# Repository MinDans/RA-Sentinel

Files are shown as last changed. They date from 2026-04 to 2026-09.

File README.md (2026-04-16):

# Project RA-Sentinel - a Radio Access Sentinel
FPGA-based Radio Receiver for securing Wifi an other access points against hacking attacks.

RA-Sentinel is an open-source project focused on creating a cost-effective, small, and low-power wide band radio receiver device that employs an FPGA to automatically detect malicious attacks on Wifi access points, such as Man in the Middle and Denial of Service attacks. By monitoring any Wifi cell, the device enhances internet safety for everyday users.
The device features low-cost receive-only chips that digitize 40 MHz of the Wifi radio spectrum at 2.4 GHz. An FPGA extracts relevant properties from demodulated and decoded packets in real-time without storage. These properties are then processed by a neural network, also implemented on the FPGA, to determine if the traffic is genuine or an attack.

 <br>
This project was funded through the NGI0 Entrust Fund, a fund established by NLnet with financial support from the European Commission's Next Generation Internet programme, under the aegis of DG Communications Networks, Content and Technology under grant agreement No 101069594.

## Latest Updates [15. Dec. 2025]

Added new firmware für the STM32 microcontroller ECU (Embedded Control Unit) on the Backend Board in "/RASBB/Software/RASBB_ECU".
It adds support for UPNP device discovery over Ethernet and provides a system configuration web page.

## System architecture

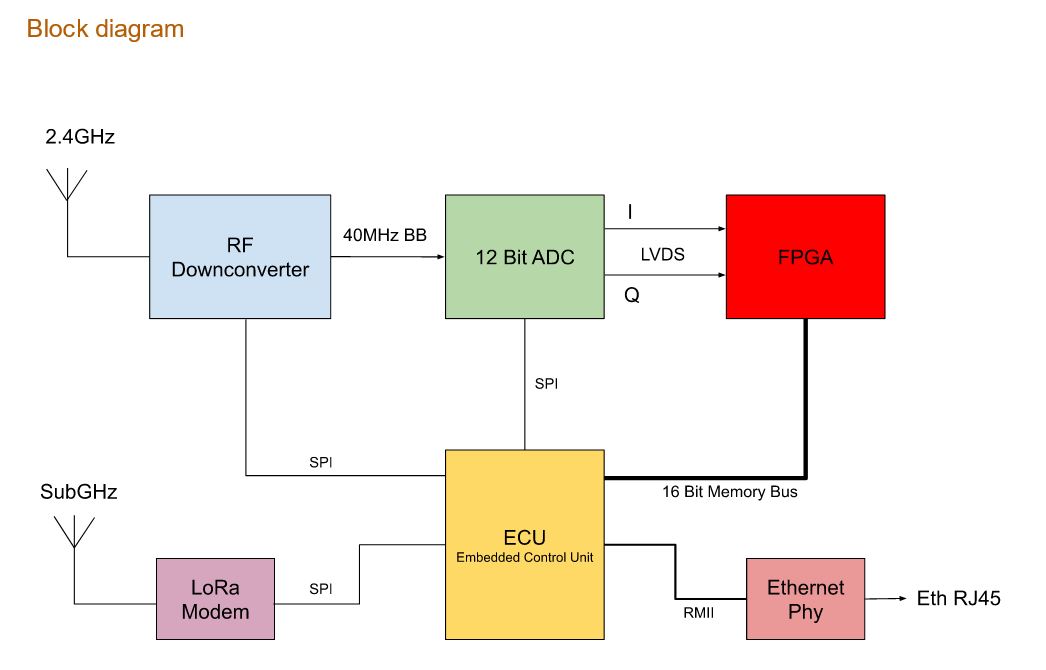
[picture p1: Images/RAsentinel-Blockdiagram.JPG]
RA-Sentinel Block Diagram


## The hardware

The hardware is a wide band SDR receiver that receives at least one complete WiFi Channel on the 2.4GHz ISM band with high resolution (12 Bits) to be able to detect smallest anomalies in a transmitted signal. The initial evaluation hardware consists of a Downcoverter/Tranceiver Chip for 2.4GHz which is widelay used in older WIFi Acess Points (MAX2831). This is followed by a 12 Bit ADC (Texas Instruments ADC3222) which converts a 40MHz window of the 2.4GHZ radio spectrum into a 4 x 240 Bit/s LVDS streams (960kBit/s total) into a XILNIX/AMD Artix7 FPGA sitting on a evaluation board made by QMTECH. 

Picture od the first RA-Sentinel prototype with QM-tech board
<sub>Picture 1: First RA-Sentinel prototype based on the QM-Tech Artix7 board and a new designed RF front end connected via PMOD connector.</sub>

Based on the experience collected with with first prototype, we designed a new SDR prototypr. Two boards of the RASBB and the RASRF2400 have arrived on 23th. Feb. 2025
Testing and bringing up is now ongoing. First results and findings can be found in the corresponding Findings_Rev*.md documents.

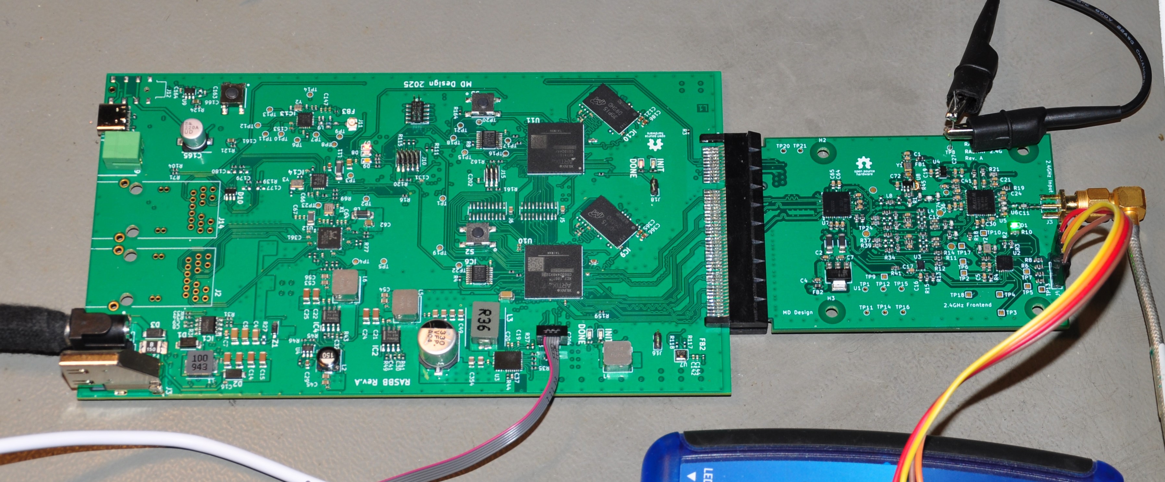
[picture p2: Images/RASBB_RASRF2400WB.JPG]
First RA-Sentinel prototype Revision A

<sub>Picture 2: RA-Sentinel prototype Revision A with RF front end board RASRF2400WB.</sub>

### Design files

**/RFFE2400WB** in this folder of this repository you find the PCB design files in KiCAD format and gerbers for the 2.4GHz 2x PMOD connected RF frontend evaluation/test board.

Link to the FPGA dev. board
[https://de.aliexpress.com/item/1005006473783593.html]

## Software / Firmware

The vast majority of the code will be written in Verilog and run on the FPGA. There is also now a firmware for the RASBB_ECU (Embedded Control Unit) and a"house keeping unit" microcontroller (STM32C031) which programms and controlling the frontend chips. The RASBB_ECI provides the interconnctivity with other systems (alarm forwarding) and the web configuration interface. This firmware is written in C. 

The firmware for the RASBB_ECU can be found <a href="https://github.com/Tobias-DG3YEV/RA-Sentinel/tree/main/RASBB/Software/RASBB_ECU">here</a>. 

The RASBB_ECU Firmware for the onboard STM32 provides a versatile configuration interface with GUI that allows to show statistics and maybe UDP for analytic packets transfer and secure TCP/IP configuration over Ethernet.
To access this, enter the IP of the RAS into your local browser like http://192.168.0.2:4842/. The IP can be easily found via network environment because the RAS supports UPNP over ethernet.

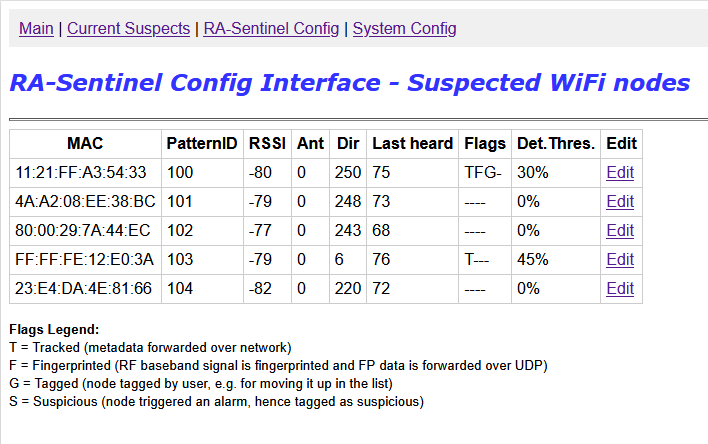
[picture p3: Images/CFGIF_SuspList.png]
WebInterface screenshot


A suspected WiFi node can be

* Tracked: Monitored by relative signal strength and later with additional direction. These values are forwarded to an IDS host that can combine this information with additional data retrieved from different RAS or other network monitoring systems.
* Tagged: Marked for internal memory, moving up in watch list.
* Fingerprinted: Raw IQ data of the frame start is forwarded to a fingerprinting algorythm.

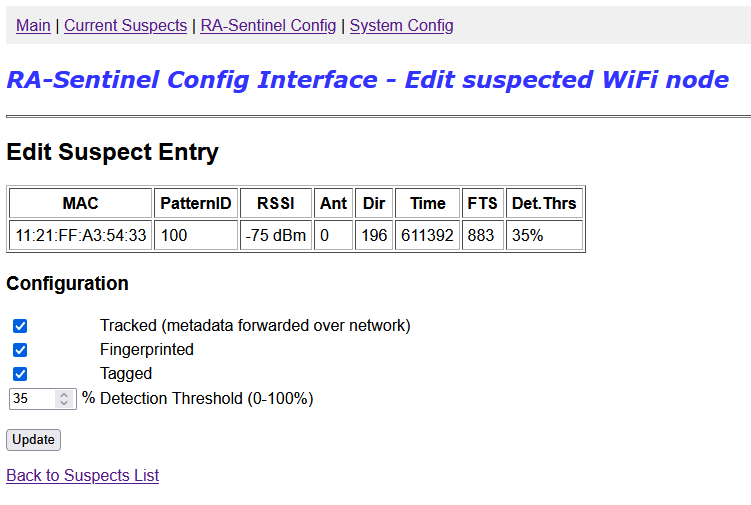
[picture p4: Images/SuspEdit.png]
Suspect Edit Screenshot


**UPNP support**

To ease the installation process, the RAS can be connected to any ethernet based LAN that provides an IPv4 DHCP server. Through the UPNP support, the RAS is easy to find in any network browser of Windows, Linux and Mac etc. 
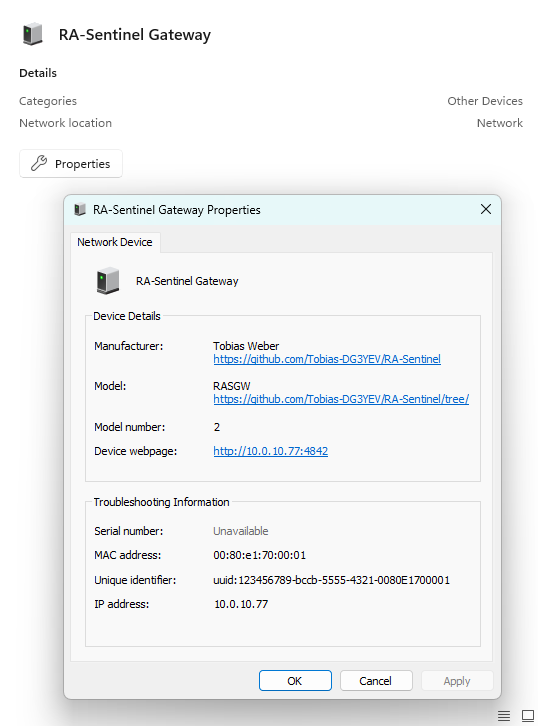
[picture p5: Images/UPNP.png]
UPNP Screenshot


---
## Sub project: RASRF2400WBMC - Directional RF Front End

The **RASRF2400WBMC** is a 4-channel, phase-coherent 2.4 GHz RF front-end board that extends RA-Sentinel with **Angle of Arrival (AoA)** estimation. By receiving the same signal across four spatially separated antennas, the system can estimate the physical direction of a detected attack - enabling threat localization for jamming, spoofing and unauthorized events.

This board connects to the existing RASBB via the PCIe connector and requires no hardware changes to the base band board.

> This sub-project was funded by NLnet: https://nlnet.nl/project/RA-Sentinel-directional/

<a href="https://nlnet.nl/commonsfund/">NGI0 Commons Fund</a>

See [RASRF2400WBMC/README.md](RASRF2400WBMC/README.md) for full details.

---

### Sub Projects / Project steps

The first step on this project was to have a reliable hardware basis. Initially I planned to have at least 40 Megasamples and with this 20 MHz bandwidth which is sufficient to capture the headers and the most common bandwitdhs used on 2.4GHz WiFi (802.11a,b,g) communications channel. But because 802.11n also defines the possibility to use 40MHz bandwith, I wanted the possibility to cover the complete possible channel bandwidth. This has been achieved with the first prototype hardware and prooved with the sub-project RASM2400, Radio Access Spectrum Monitor for 2400MHz. You can find all project details below.

## Sub project #1: RASM2400 - a spectrum monitor

RASM2400 stands for Radio Access Spectrum Monitor operationg on 2400MHZ. It offers a visual spectrum analyzer design that runs on the evaluation hardware set of RA-Sentinel the Artix7 XC7A100T Wukong board and the RFFE2400 front end board.
It shall proove that a 40MHz wide radio spectrum can be received and transported into the FPGA. Further, this project may already be useable for first RF forensics. Feel free to download all the stuff and build an RASM by yourself.

The following diagram shows the system architecture of the RASM2400.

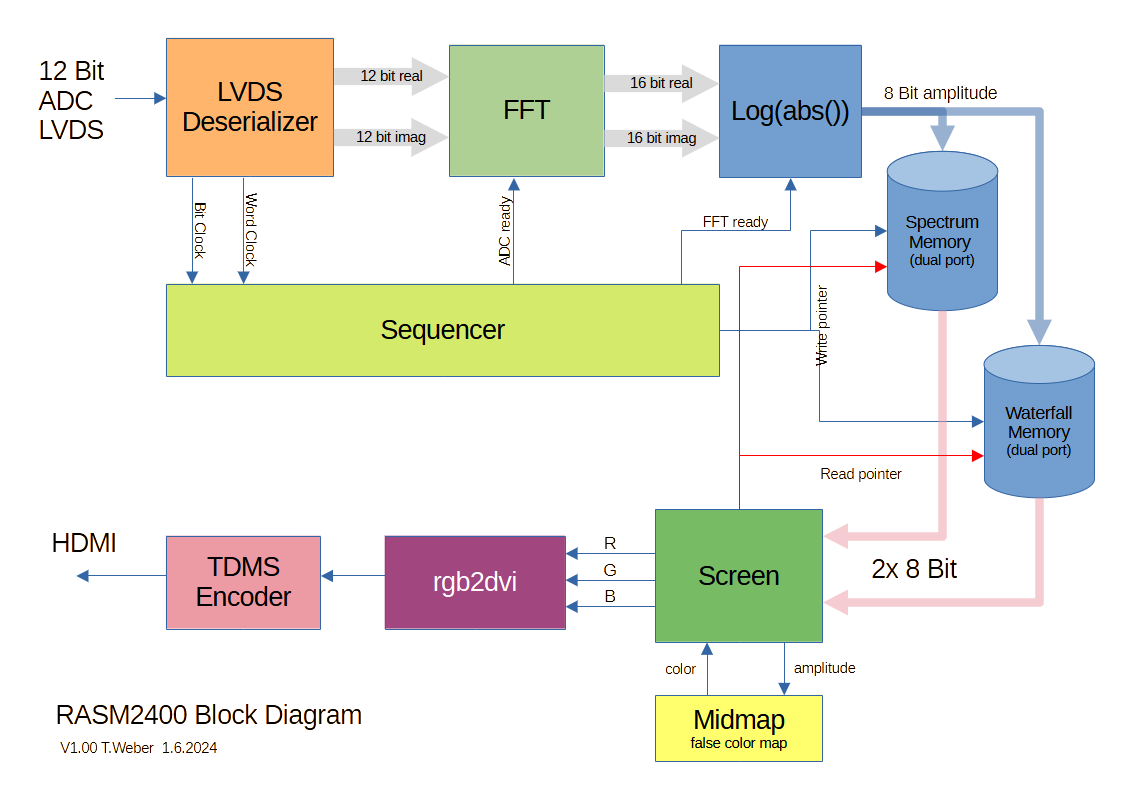
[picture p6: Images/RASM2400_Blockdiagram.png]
RASM2400 Block Diagram


The output of the HDMI port of the QMTECH Wukong board.

Screenshot of the RASM2400 HDMI output

Watch a short demonstration on Youtube by clicking on the thumbnail below.

Watch the video (https://youtu.be/tnwXk62DtHw)

### Software

In this repository you'll find also all software paerts needed to get the project up and running.

**/RASM2400_Verilog**

This folder contains the Verilog source files as well as a ready to program bit stream file. 

**/RASM2400_HKU**

Here you find the firmware for the RF board housekeeping unit. It does not do much a the moment but initializing the Downconverter MAX2831 and the ADC3222. It is planned to receive commands via I2C to change basic parameters wil center frequency, sensitivity and AGC characteristics. This porject can be compiled with arm-gcc or with the free available and Eclipse based development environment (IDE) from ST called "STM32CubeIDE". You can download this IDE from ST.com [https://www.st.com/en/development-tools/stm32cubeide.html]

### Project update 13th Oct. 2024

The target of the next Milestone #2 was the „Identification and isolation of appropriate software components“ and also to „Additionally apply modifications to the openOFDM module to get extra meta data out of the frame demodulator to have a wider data basis for the later fingerprinting process.“

In the following points I describe how I achieved each step of this Milestone.

**1. compile/synthesize openWiFi on the target FPGA**

The code of openWiFi has been successfully ported from the project GitHub site [1] to the evaluation setup that I have designed and set up in the first Milestone. After gluing together the ADC LVDS deserializer block inside the FPGA with the parallel input of the openOFDM core, got rid of several timing constraint issues, I finally achieved to decode a WiFi Frame coming from an arbitrary signal generator. To accomplish this target, the code needed to be isolated from the original open WiFi demo project code. This original demo was based on SDR evaluation boards relying all on the AMD ZYNQ FPGA-ARM chip family. This family provides an FPGA part and an integrated ARM micro processor to which all communication of the FPGA part is connected to. Data from and to the integrated processor is exchanged through a common memory bus. This however is not working with my design idea which is based on a more powerful FPGA with an external ARM co-processor. I tried extracting the needed HDL (Verilog) parts and make this code running stand-alone. Finally I came the conclusion that only the project „openOFDM“ needs to be ported to my RA-Sentinel project hardware because the network layer and the transmit part implemented in openWiFi is not really needed by the RA-Sentinel project because there is no need in routing real data back and forth to a network. We are only interested in the lowest layer of a WiFi frame and its analog characteristics, not the routing of packets and also not in the frame containing payload as such.

First I adapted the test-bench provided in [2] for the Vivado simulation environment. To be able to simulate the complete RA-Sentinel hardware, I created a LVDS emulator that can stream artificial synthesized and recorded  RF data coming originally from the TI ADC 3221. After providing recorded RF data via this LVDS simulator and generating a appropriate, to the ADC phase-locked master clock of 100MHz to the openOFDM core and (see top_tb.v), this setup was able to decode a complete 802.11a/g frame in the AMD Vivado simulator. It took me quite some fiddling and playing with timings and implementation settings of the tool-chain to finally get it running properly on my own hardware. (AMD Artix7 development board my QM-Tech and my 2.4GHz ADC board designed in Milestone 1)

**2. Strip down openWiFi and open OFDM to the receive part**

First this was regarded as an easy task but as deeper I dived into the code  by the original author of the two projects, the more I realized the code provides almost no comments and wire and register definitions are quite ambiguous and non-intuitive. In my opinion the code needed desperately a rework to be better understandable which would also lead to a lower learning curve for others also trying to implement and adapt the existing code base to their needs. Two major things I tried improving with my fork of openOFDM: The introduction of directional prefixes for module ports. I have seen such in the code of another NLnet founded guy called Dan Nissselquist. Adding the prefix  „i_“ to  input ports (defined as wires/registers in Verilog) and „o_“ to the port definition makes it IMHO much easier when browsing through the code, allowing to instantly realize which wire or register is being exported from this current module and which is only a local element. I added these prefixes all over the code of openOFDM. See my fork of openOFDM on GitHub [1] for details. The next thing I found hard to understand, was the use of the ever repeating word „sample“ for all data along the signal path, from the input of the openOFDM core (ADC base-band data) up to near the exit (decoded data bytes). As there is a switch from time domain (endless sample stream) into frequency domain (blocks of 64 frequency bands) in the module „sync_long“, I changed the name of all wires and registers after this module and renamed them into „spectrum“.  Also some comments were added to clarify what a wire or register is doing at a certain point. This work is not yet regarded as being completed. Each time I dig into the original code, I will add comments and try to make the code more „barrier free“.

**3. Create a new fork of openOFDM**

This has been done and the new fork of openOFDm can be found here:

[1] https://github.com/Tobias-DG3YEV/openofdm

It contains comments and my code changes proposed earlier in this document.

**4. Try adding additional meta date stubs**

As I tried figuring out which meta data could be used to distinguish between  genuine transmitting device and a counterfeit device, I found an article at mathworks.com [3] reporting that they proved finding counterfeit, evil twins of a WiFi Access Point by feeding the raw sampled channel data of a transmission into a ML algorithm. For this purpose they followed a kind of a brute force approach by taking all samples of a received frame into account and fed into a ML algorithm. Even the smallest frame like an information or flow control frame that is only 100uS of duration will produce 16kBytes of data which is rather huge. This amount of data may be processable - if the SDR is directly connected to a powerful computer with multiple cores etc. The project RA-Sentinel does not follow this kind of big processing power approach. Amplitude, phase and frequency change due to several effects during the transmission of a frame, but all of these changes always result in a phase shift. So I thought, in  the first attempt identifying a WiFi transmitting device by characterizing (or say learning) the phase deviation over time may be sufficient. Because the RF receiver front end of the RA-Sentinel project has a low noise and high stability master clock (a 40MHz TXCO by Abracom) that is multiple times more accurate that standard commercial WiFi transmitters, I hope that a small amount of phase shift data received in the beginning of a WiFi frame may be enough to clearly identify counterfeit devices. 

**5. Redefine a new simplified interface to access meta parameters**

One thing I have learned throughout the project progress so far, is that even many may say that an FPGA is one of the most versatile digital programmable devices available today, allowing the implementation of any kind of parallel and sequential tasks up to integration of soft-core processors the fact is that all this integrated logic leads to a rather time consuming iterative development process. To optimize WiFi data reception on one side and to interpret and forward meta data on the other side all inside the FPGA leads to an extremely slow and challenging development process. For the analysis of meta data, an external, traditional single chip microprocessor running straight C/C++ code,  offers much more opportunities and most importantly, allows much a faster  development progress. Bit for that, I need a fast and reliable interconnection between the FPGA and the micro processor.

I identified and implemented two interfaces which allow to access 

The first interface I implemented into the FPGA was the SPI slave interface. This interface allows reading and writing 32 wide registers inside the FPGA by an external micro controller (in this case, I use a STM32H743 Cortex-M7)

The SPI interface allows access to the following parameters:

- Receiver characteristics like receiver center frequency, gain, power threshold, max. error rate etc.

- reading current receiver parameters like noise level, signal to noise ratio etc.

Further I needed an interface that is capable transferring header and  metadata that is produced with each WiFi 802.11 frame received to my  external ARM processor. As I cannot foresee at this point in the project how much meta data is needed to distinctly identify a sender hardware of a frame, I was looking for a method to reliably transport greater chunks of data from the FPGA directly into the memory of the external micro-controller without code intervention. Hence, I started evaluating the possibilities based on the peripheral capabilities of the STM32 device family.  After I had invested some effort into research and experiments, I found that SPI especially in a 4-Bit configuration might feasible as it is able transporting 25MByte/s. But the digital camera interface (DCMI) that many of those top range micro-controllers provide, offer 8 Bit parallel data transfer directly into the controller’s memory via DMA at a maximum rate of 80MBytes/s.

So the next step was to design a logic circuit into the FPGA that can mimic the signaling of a digital camera module with DCMI interface. This has been implemented on both sides, the FPGA in Verilog Code and on the STM32H7 in C language. 

The received 802.11 frame info packet that is streamed upon each complete frame reception has the following format:

**Resources:**

[1] https://github.com/open-sdr/openwifi-hw/

[2] https://github.com/Tobias-DG3YEV/openofdm

[3] https://de.mathworks.com/help/comm/ug/design-a-deep-neural-network-with-simulated-data-to-detect-wlan-router-impersonation.html

Project Maintainer: Tobias Weber

Last updated: 27. Feb. 2025

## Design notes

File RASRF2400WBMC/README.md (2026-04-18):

# RASRF2400WBMC - 4-Channel Directional RF Front End

## Overview

The **RASRF2400WBMC** is a 4-channel, 2.4 GHz RF front-end board designed as a directional extension to the RA-Sentinel WiFi intrusion detection system. While the single-channel RASRF2400WB board can detect malicious WiFi attacks, this board adds the ability to determine the **direction from which an attack originates**.

By receiving the same signal across four spatially separated antennas in a phase-coherent manner, the system can estimate the **Angle of Arrival (AoA)** of incoming RF signals. This enables **threat localization** - helping to physically identify and locate sources of jamming, spoofing, Man-in-the-Middle, or Denial of Service attacks.

This board connects to the existing [RASBB](https://github.com/MinDans/RA-Sentinel/tree/main/RASBB) (RA-Sentinel Base Band Board) via a PCIe connector, making use of its multiple ADC input lines without requiring any changes to the base band hardware.

---

## System Architecture

```
ANT 1 --+
ANT 2 --+--[ 4x MAX2831 ]-[ I/Q analog ]-[ ADC3424 #1 ]-[ LVDS D0 ]-|
ANT 3 --+                                  [ ADC3424 #2 ]-[ LVDS D0 ]-|-[ PCIe ] -> RASBB
ANT 4 --+
```

All four channels are **phase-coherent**, meaning the RASBB can compare the phase difference between channels to compute the Angle of Arrival of a detected signal.

---

## Hardware Specifications

| Parameter | Value |
|---|---|
| Frequency | 2.4 GHz ISM band |
| Number of channels | 4 (phase-coherent) |
| Transceiver | Maxim MAX2831 (x4) |
| Digitization | TI ADC3424 x2 - 6-bit eff. - 40 MSPS |
| Interface to RASBB | PCIe connector |
| Primary function | Angle of Arrival (AoA) estimation |
| Status | Sent for manufacturing - not yet delivered |

---

## Repository Structure

```
RASRF2400WBMC/
+-- README.md                          This file
+-- Hardware/
|   +-- KiCad/                         Source design files
|   |   +-- RASRF2400WBMC.kicad_pro
|   |   +-- RASRF2400WBMC.kicad_sch
|   |   +-- RASRF2400WBMC.kicad_pcb
|   |   +-- Libraries/
|   |       +-- Footprints/           KiCad footprints
|   |       +-- Symbols/              KiCad symbols
|   +-- Production/
|       +-- RevA.0/                   Manufacturing outputs for Revision A.0
|           +-- Gerbers/              Gerber + drill files (.gbr, .drl)
|           +-- PickAndPlace/         Component placement files (.csv)
|           +-- BoM/                  Bill of Materials (.csv)
+-- Images/                           Board renders, photos, block diagrams
+-- Docs/
    +-- Design_Notes.md               Design decisions, antenna spacing, AoA theory
```

---

## Relationship to Other RA-Sentinel Boards

| Board | Antennas | Purpose | Interface |
|---|---|---|---|
| RASRF2400WB | 1 | Wideband detection | PCIe -> RASBB |
| RASRF2400WBMC | 4 | Detection + direction finding | PCIe -> RASBB |
| RASBB | - | Base band processing (shared) | - |

Both RF front-end boards are designed to work with the same RASBB.

---

## Status

>  This board has been sent for manufacturing and not yet delivered. A bring-up log will be added to `/Docs/` once the first boards arrive.

---

## Funding

This project was funded through the **NGI0 Commons Fund**, a fund established by NLnet with financial support from the European Commission's Next Generation Internet programme, under the aegis of DG Communications Networks, Content and Technology under grant agreement No 101135429. Additional funding is made available by the Swiss State Secretariat for Education, Research and Innovation (SERI).

<a href="https://nlnet.nl/commonsfund/">NGI0 Commons Fund</a>
<a href="https://nlnet.nl/project/RA-Sentinel-directional/">NLnet</a>

---

## Project Maintainer

**Mina Daneshpajouh** - in collaboration with Tobias Weber

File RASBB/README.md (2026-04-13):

# RA-Sentinel System Overview

The **RA-Sentinel** system consists of two main boards that work together to enable high-performance RF signal reception, digitization, and processing.

## RA-Sentinel Radio Front-End Board (RASRF)
The **RASRF** board is responsible for receiving and conditioning, and digitizing RF signals before transmitting them to the baseband processor.
 - The antenna is connected through a Balun to an RF front-end transceiver, which performs signal reception, downconversion, and filtering.
 - The downconverted signal is then conditioned using a driver circuit optimized for impedance matching and signal integrity.
 - A high-speed 12-bit ADC samples a 40 MHz portion of the 2.4 GHz radio spectrum, converting it into a 960 Mbit/s data stream (2 channels: I+Q, 12-bit each @ 40 
   MSPS). 
 - The digitized data is transmitted over a PCIe interface to the RASBB board for baseband processing.

## RA-Sentinel Baseband Board (RASBB)
The **RASBB** board processes the received digital RF data and manages higher-layer communication.
 - It performs baseband signal processing, extracting relevant information from the digitized RF data.
 - It transitions the processed data from OSI Layer 1 (Physical) to OSI Layer 2 (Data Link) for further communication and protocol handling.
 - The board integrates additional processing units and interfaces for system-level control, data management, and external communication.

Together, the **RASRF** and **RASBB** boards create a scalable, high-performance platform for RF signal acquisition and real-time processing.

Below is the block diagram illustrating the architecture of both boards and their interconnections:





## The hardware

The PCB of the RASBB is constructed from an FR4 eight-layer PCB, which contains several processing units, sensors, and radio and wired interfaces.
Below is a list of its features:

- Two Artix-7 FPGAs with 100k Logic Elements each
- 4 Gigabit (512MB with 16-bit access) Low Voltage DDR3 RAM
- STM32H7 high-performance (up to 480MHz) ARM Cortex-M7 microcontroller
- x8 PCI Express slot
- HDMI port, with video generated in FPGA 1
- 40-bit (32+8) inter-processor communication bridge (accessible by external logic analyzers)
- Two separately usable 16M Flash chips for FPGA configuration, accessible by both FPGA and STM32
- Temperature and humidity sensor for physical environment supervision
- Audio DAC with a 1W output amplifier (for alarm and voice output)
- Audio ADC for capacitive microphone connection (for acoustic environment surveillance)
- Open-collector 30V/1A capable switching output (for alarming devices)
- USB-C port with virtual COM port support for debugging and updates
- 2.4GHz LoRaWAN™ modem chip for robust alarm distribution
- 100Mbit/s Ethernet port connected to the STM32H7 MCU
- 1Gbit/s Ethernet port connected to FPGA 2
- Power over Ethernet (PoE) Type 1 with a maximum power of 13W
- LEDs for indication
- Configuration button
- FPGAs and STM32 accessible through JTAG port

*The RA-Sentinel Baseband Board design will fit into a 100mm extrusion enclosure.* 


*RASBB Rev A (Top View)*


*RASBB Rev AB (Bottom View)*

The PCB of the RASRF is constructed from an FR4 Four-layer PCB, which contains  processing unit, RF-transmitter, and an Analoge/to/Digital converter.

*RASRF Rev AB (Top View)*


*RASRF Rev AB (Bottom View)*

*Hardware designed by **Mina Daneshpajouh**.*

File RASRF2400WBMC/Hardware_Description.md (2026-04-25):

# RASRF2400WBMC - Hardware Description

## What this board does

The RASRF2400WBMC is the RF front end for the directional extension of RA-Sentinel. Where the original single-channel board can tell you *that* a WiFi attack is happening, this one can tell you *where it's coming from*. It does that by receiving the same signal on four separate antennas simultaneously and measuring the phase difference between channels - from which the RASBB can calculate the Angle of Arrival (AoA).

The board was designed to plug into the same PCIe slot as the single-channel RASRF_2400WB. No changes to the RASBB are needed; the baseboard already has enough ADC inputs and the FPGA handles the rest.

---

## Signal chain

Four antennas connect through balun transformers (HHM1902B1) directly into four MAX2831 transceivers. The MAX2831 is a direct-conversion 2.4 GHz chip - it downconverts the incoming signal to baseband I/Q, which comes out as a differential analog signal. Those analog outputs feed two ADC3424 converters (Texas Instruments, 12-bit capable - **6-bit effective**, quad-channel, 40 MSPS). Only the D0 LVDS output pairs are connected; D1 pairs are left unconnected. Each ADC handles two channels (I+Q each), so ADC #1 digitises CH1 and CH2, and ADC #2 handles CH3 and CH4. The resulting LVDS streams go through the PCIe connector to the RASBB, where the FPGA picks them up.

Total digital data rate: four channels x 6-bit I/Q x 40 MSPS = ~ 1.92 Gbit/s.

```
ANT 1 --+
ANT 2 --+--[ 4x MAX2831 ]-[ I/Q analog ]-[ ADC3424 #1 ]-[ LVDS D0 ]-|
ANT 3 --+                                  [ ADC3424 #2 ]-[ LVDS D0 ]-|-[ PCIe ] -> RASBB
ANT 4 --+                                                              +
```

---

## Clock distribution

Phase coherence across the four channels depends entirely on all four MAX2831 chips and both ADCs sharing a single reference clock. A 5PB1206NDGK8 clock fanout buffer takes the 40 MHz reference from an onboard TCXO and distributes it to six outputs: one per MAX2831 and one per ADC. PCB trace lengths from the fanout to each chip are matched.

---

## Housekeeping MCU

A STM32C031K6U6 manages startup and configuration. It talks to all four MAX2831 chips and both ADC3424s over a shared SPI bus, with individual chip selects per device. A level shifter (SN74AXC4T774RSVR) handles the voltage translation between the STM32 and the ADCs SPIs pins. The STM32 also has an I2C interface connected to the RASBB, so the RASBB can send configuration commands or read status without the STM32 needing a standalone firmware update for each parameter change.

---

## Power supply

The board takes 3.3 V from the PCIe connector and generates the additional rails locally:

- **1.8 V** - LD1117 LDO, for the ADC3424 core supply
- **3 V** - ADP7154 LDO, for the MAX2831 supply rails

---

## Key components

| Part | Function |
|---|---|
| Maxim MAX2831 x4 | 2.4 GHz direct-conversion transceiver, RX only in this design |
| TI ADC3424 x2 | 12-bit capable (6-bit effective, D0 only), quad-channel ADC, 40 MSPS, LVDS output |
| 5PB1206NDGK8 | 6-output clock fanout buffer, drives all four transceivers and both ADCs |
| STM32C031K6U6 | Housekeeping MCU - SPI config, I2C to RASBB |
| SN74AXC4T774RSVR | 4-bit dual-supply level shifter (3.3 V <-> 1.8 V) |
| HHM1902B1 x4 | 2.4 GHz balun, single-ended to differential conversion at antenna input |
| LD1117DT18  | 1.8 V LDO regulator |
| ADP7156ACPZ-3.0-R7 | Adjustable LDO, set to 3V |

---

## Block diagram
Block Diagram

---

## Design notes

See [Design Notes](https://github.com/MinDans/RA-Sentinel/blob/main/RASRF2400WBMC/Docs/Design_Notes.md) for antenna spacing derivation, AoA algorithm selection, phase coherence strategy, and the open questions list being worked through during the design phase.

---

*Hardware design: Mina Daneshpajouh*
*Firmware / signal processing: Tobias Weber*

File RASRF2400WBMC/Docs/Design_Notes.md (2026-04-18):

# 

>  This document is a living record of design decisions made during development. It will be updated as the design matures and bring-up begins.

---

## 1. Motivation and Design Goals

The single-channel RASRF2400WB board can detect the presence a WiFi attack (e.g. jamming, spoofing), but cannot determine where the attacker is physically located. In dense environments - offices, apartment buildings, public venues - this limits the usefulness of the detection: an alert without a direction is difficult to act on.

The RASRF2400WBMC adds a spatial dimension to RA-Sentinel's detection capability by implementing a 4-element antenna array with phase-coherent reception. From the phase differences measured across channels, the RASBB FPGA can compute the Angle of Arrival (AoA) of any detected transmission.

---

## 2. Angle of Arrival (AoA) Theory

### 2.1 Basic Principle

To be added

### 2.4 Algorithms Considered

To be added

---

## 3. Phase Coherence Strategy

All 4 MAX2831 transceivers must share a single reference clock to ensure phase coherence across channels. Any independent oscillator drift would introduce pseudo-random phase offsets that make AoA estimation impossible.

**Approach:**
- Route a single master clock (from RASBB or an on-board TCXO) to all four MAX2831 REF_CLK inputs
- Use matched-length PCB traces from the clock source to each transceiver
- Use matched-length traces from ADC outputs to the PCIe connector

The MAX2831 requires a 40 MHz reference clock. This is consistent with the 40 MHz TCXO already used on the RASRF2400WB board.

---

## 4. ADC and Data Path

Each MAX2831 produces a baseband I/Q analog output. Each of the 4 channels feeds an ADC for digitisation. The digitised streams are serialised for transport over the PCIe interface to the RASBB.

Data rate estimate per channel:
- 6-bit I, 6-bit Q @ 40 MSPS = 480 Mbit/s per channel (ADC3424 D0 only - D1 pairs not connected)
- 4 channels = 1.92 Gbit/s total

---

## 5. PCB Stack-up 

The RASRF_2400_Directional PCB will use a **6-layer stack-up**:

| Layer | Function |
|---|---|
| Top | RF and signal routing |
| L2 | Ground plane |
| L3 | Power plane/signal routing |
| L4 | Power plane/signal routing |
| L5 | Ground plane |
| L6 | Signal routing |

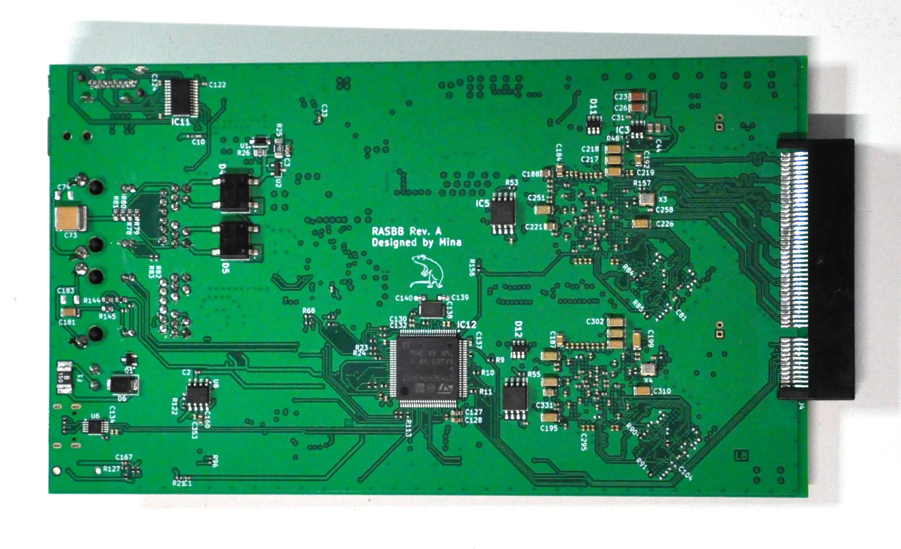
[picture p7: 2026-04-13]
RASBB/RASBB_RevA_back.JPG

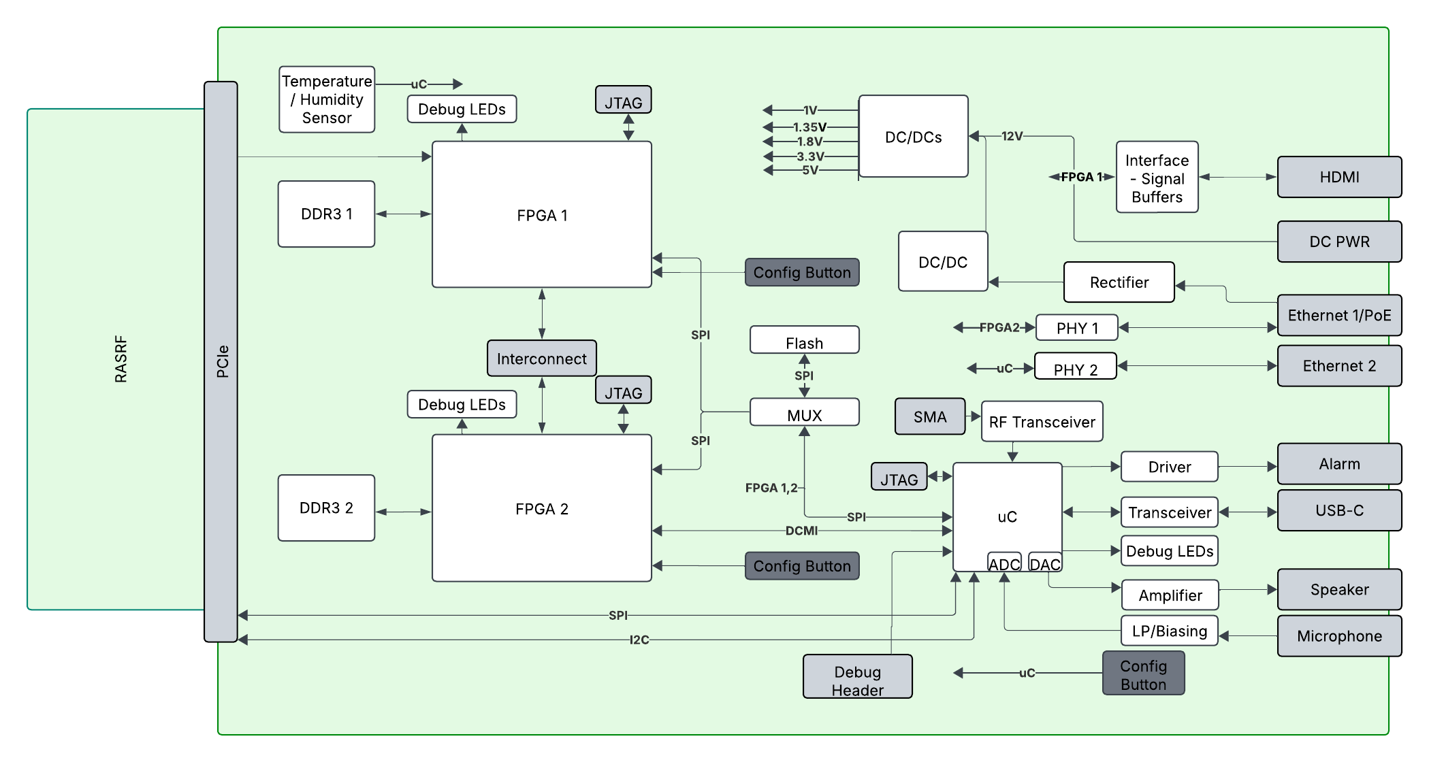
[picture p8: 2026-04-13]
RASBB/RASBB-BlockDiagram.png

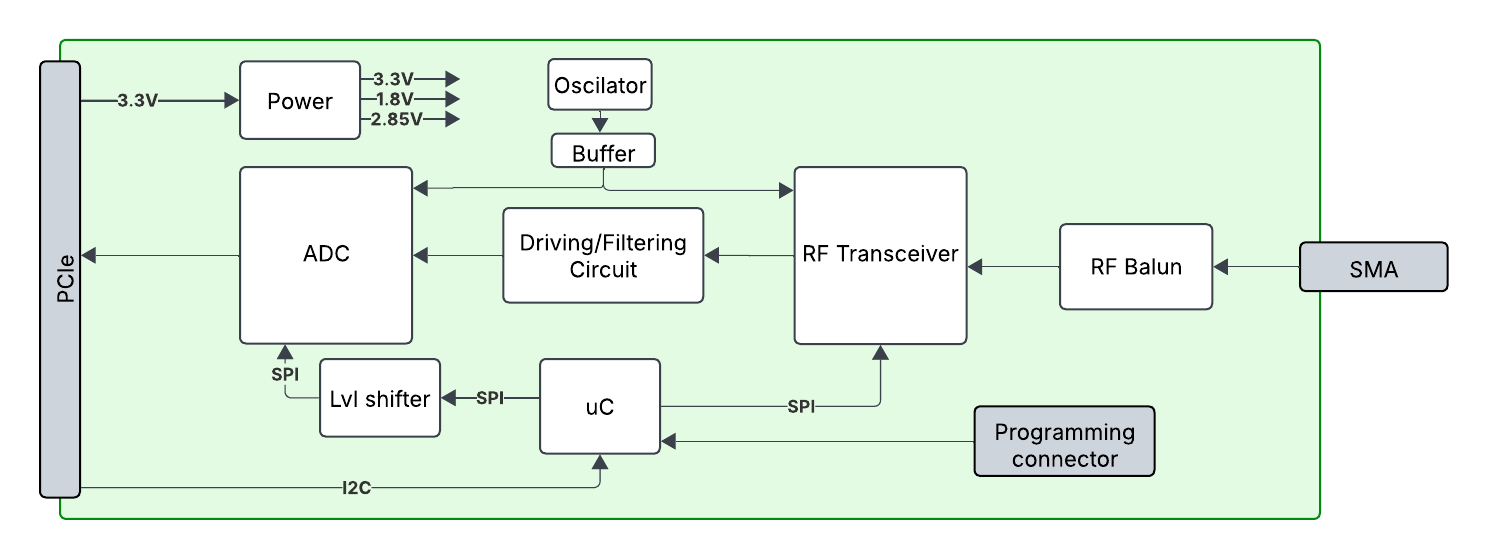
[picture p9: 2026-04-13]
RASBB/RASRF-BlockDiagram.png

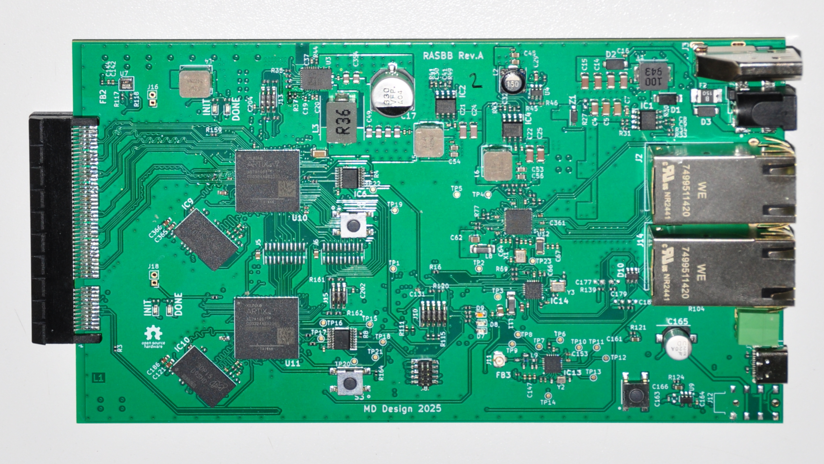
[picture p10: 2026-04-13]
RASBB/RASBB_RevA_top.jpg

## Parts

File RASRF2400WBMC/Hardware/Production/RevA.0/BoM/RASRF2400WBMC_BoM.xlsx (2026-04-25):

Reference | Qty | Value | DNP | Exclude from BOM | Exclude from Board | Footprint | Manufacturer_Name | Manufacturer_Part_Number | Description
H1,H2,H3,H4 | 4 | MountingHole | DNP |  |  | MountingHole:MountingHole_3.2mm_M3_ISO7380
J7 | 1 | PCIexpress_x8 | DNP |  |  | Connector_PCBEdge:BUS_PCIexpress_x8
TP1,TP2,TP3,TP4,TP5,TP6,TP7,TP9,TP10,TP12,TP16,TP19,TP20,TP22 | 14 | TestPoint | DNP |  |  | TestPoint:TestPoint_THTPad_D1.0mm_Drill0.5mm
TP8 | 1 | TestPoint | DNP |  |  | TestPoint:TestPoint_Pad_1.0x1.0mm
TP11,TP13,TP15,TP17 | 4 | TestPoint | DNP |  |  | TestPoint:TestPoint_Pad_D1.0mm
J1,J2,J3,J4 | 4 | 60312202111527 |  |  |  | JACK_02114307_WRE | Würth Elektronik | 60312202111527 | Conn, WR-MPC3 Power, Male Header, 2-pos, 3.81mm Pitch, SMD, 12A, 250V
J5 | 1 | 1-1478979-0 | DNP |  |  | 114789790 | TE Connectivity | 1-1478979-0 | Conn, SMA, Jack/Female, Straight, PCB Mount, 50Ω, Solder, Through Hole, 18GHz
C159,C160,C161,C162,C163,C164,C165,C166,C194,C195,C196,C197,C198,C199,C200,C201 | 16 | 11pF |  |  |  | Capacitor_SMD:C_0402_1005Metric | Johanson | 500R07S110GV4T | Cap, MLCC, 11pF, 50V, C0G/NP0, 0402, ±2%
IC2 | 1 | 5PB1206NDGK8 |  |  |  | QFN40P300X300X100-21N-D | Renesas Electronics | 5PB1206NDGK8 | IC, Clock Buffer, 1:6 TCXO/LVCMOS, 1.8V, 200MHz, Individual OE, 20-VFQFPN, T&R
Y1 | 1 | 7L-40.000MBS-T |  |  |  | 4-SMD_NoLead_Oscillator | TXC Corporation | 7L-40.000MBS-T | OSC, TCXO, 40MHz, 3.3V, ±2ppm, Clipped Sine, SMD 2.5x2mm, 4-Pin
Y2 | 1 | ABM10-166-12.000MHZ-T3 |  |  |  | ABM10 | Abracon | ABM10-166-12.000MHZ-T3 | Crystal, 12MHz, 8pF, ±10ppm, 125Ω ESR, SMD 2.5x2.0mm, T&R
IC5,IC6 | 2 | ADC3424IRTQR |  |  |  | QFN50P800X800X100-57N-D | Texas Instruments | ADC3424IRTQR | IC, ADC, Quad-Ch, 12-bit, 25–125MSPS, LVDS Output, JESD204B, 56-QFN (8x8mm), T&R
IC1 | 1 | ADP7156ACPZ-3.0-R7 |  |  |  | SON50P300X300X80-11N-D | Analog Devices | ADP7156ACPZ-3.0-R7 | 1.2 A, Ultralow Noise, High PSRR, Fixed Output, RF Linear Regulator
D1 | 1 | APTD1608SECK/J4-PF |  |  |  | LED_SMD:LED_0603_1608Metric | Kingbright | APTD1608SECK/J4-PF | LED, Orange, 605nm, 2.2V, 20mA, 0603, SMD
FB1 | 1 | BLM18BD601BH1D |  |  |  | IND_BLM18_0603_MUR | Murata | BLM18BD601BH1D | Ferrite Bead, 600Ω @100MHz, 500mA, 0.38Ω DCR, 0603, T&R
FB2 | 1 | BLM18SG331TN1B |  |  |  | IND_BLM18_0603_MUR | Murata | BLM18SG331TN1D | Ferrite Bead, 330Ω @100MHz, ±25%, 1.5A, 70mΩ DCR, 0603, T&R
FB3,FB4,FB5,FB6 | 4 | BLM41PG102SN1L |  |  |  | IND_BLM41_1806_MUR | Murata | BLM41PG102SN1L | Ferrite Bead, 1kΩ @100MHz, ±25%, 1.5A, 90mΩ DCR, 1806 (4516 Metric), T&R
Z1 | 1 | BZT52C4V7 |  |  |  | BZT52C4V7 | Diotec | BZT52C4V7 | Zener Diode, 4.7V, ±5%, 200mW, SOD-123, T&R
C171,C173,C176,C178,C206,C208,C211,C213 | 8 | 0.22uF |  |  |  | Capacitor_SMD:C_0603_1608Metric | Yageo | CC0603KRX7R9BB224 | Cap, MLCC, 220nF, 50V, X7R, 0603, ±10%
C77,C78,C100,C101,C123,C124,C146,C147 | 8 | 1.5pF |  |  |  | Capacitor_SMD:C_0402_1005Metric | Murata | GJM1555C1H1R5BB01D | Cap, MLCC, 1.5pF, 50V, C0G/NP0, 0402, ±0.1pF
C52,C54 | 2 | 6pF |  |  |  | Capacitor_SMD:C_0402_1005Metric | Murata | GJM1555C1H6R0CB01D | Cap, MLCC, 6pF, 50V, C0G/NP0, 0402, ±0.25pF
C71,C72,C94,C95,C117,C118,C140,C141 | 8 | 10pF | DNP |  |  | Capacitor_SMD:C_0402_1005Metric | Murata | GRM1555C1H100JZ01D | Cap, MLCC, 10pF, 50V, C0G/NP0, 0402, ±5%
C61,C62,C65,C68,C70,C75,C80,C84,C85,C88,C91,C93,C98,C103,C107,C108,C111,C114,C116,C121,C126,C130,C131,C134,C137,C139,C144,C149 | 28 | 100pF |  |  |  | Capacitor_SMD:C_0402_1005Metric | Murata | GRM1555C1H101JA01D | Cap, MLCC, 100pF, 50V, C0G/NP0, 0402, ±5%
C2 | 1 | 2200pF | DNP |  |  | Capacitor_SMD:C_0402_1005Metric | Murata | GRM1555C1H222JA01D | Cap, MLCC, 2200pF, 50V, C0G/NP0, 0402, ±5%
C3,C81,C104,C127,C150 | 5 | 2200pF |  |  |  | Capacitor_SMD:C_0402_1005Metric | Murata | GRM1555C1H222JA01D | Cap, MLCC, 2200pF, 50V, C0G/NP0, 0402, ±5%
C7,C8,C9,C10 | 4 | 47pF |  |  |  | Capacitor_SMD:C_0402_1005Metric | Murata | GRM1555C1H470FA01D | Cap, MLCC, 47pF, 50V, C0G/NP0, 0402, ±1%
C79,C102,C125,C148 | 4 | 68pF |  |  |  | Capacitor_SMD:C_0402_1005Metric | Murata | GRM1555C1H680JZ01D | Cap, MLCC, 68pF, 50V, C0G/NP0, 0402, ±5%
C55,C59,C60,C63,C73,C82,C83,C86,C96,C105,C106,C109,C119,C128,C129,C132,C142 | 17 | 10uF |  |  |  | Capacitor_SMD:C_0402_1005Metric | Murata | GRM155R61A106ME11D | Cap, MLCC, 10µF, 10V, X5R, 0402, ±20%
C1,C11,C12,C13,C14,C15,C16,C17,C18,C19,C20,C21,C22,C23,C24,C25,C26,C27,C28,C29,C30,C31,C32,C36,C41,C44,C56,C57,C58,C76,C99,C122,C145,C167,C168,C169,C170,C172,C174,C175,C177,C179,C180,C181,C182,C183,C184,C185,C202,C203,C204,C205,C207,C209,C210,C212,C214,C215,C216,C217,C218,C219,C220 | 63 | 100nF |  |  |  | Capacitor_SMD:C_0402_1005Metric | Murata | GRM155R71A104KA01D | Cap, MLCC, 100nF, 10V, X7R, 0402, ±10%
C39,C45,C46,C47,C64,C66,C67,C69,C74,C87,C89,C90,C92,C97,C110,C112,C113,C115,C120,C133,C135,C136,C138,C143 | 24 | 10nF |  |  |  | Capacitor_SMD:C_0402_1005Metric | Murata | GRM155R71H103KA88D | Cap, MLCC, 10nF, 50V, X7R, 0402, ±10%
C33,C34,C35,C38,C42,C48,C50,C51 | 8 | 10uF |  |  |  | Capacitor_SMD:C_0603_1608Metric | Murata | GRM188R61E106MA73D | Cap, MLCC, 10µF, 25V, X5R, 0603, ±10%
C40,C43,C49 | 3 | 1uF |  |  |  | Capacitor_SMD:C_0603_1608Metric | Murata | GRM188R71E105KA12D | Cap, MLCC, 1µF, 25V, X7R, 0603, ±10%
C4,C5,C6,C53 | 4 | 100nF | DNP |  |  | Capacitor_SMD:C_0603_1608Metric | Murata | GRM188R71H104KA93D | Cap, MLCC, 100nF, 50V, X7R, 0603, ±10%
C37,C151,C152,C153,C154,C155,C156,C157,C158,C186,C187,C188,C189,C190,C191,C192,C193 | 17 | 100nF |  |  |  | Capacitor_SMD:C_0603_1608Metric | Murata | GRM188R71H104KA93D | Cap, MLCC, 100nF, 50V, X7R, 0603, ±10%
U5,U7,U9,U11 | 4 | HHM1902B1 |  |  |  | HHM-4_1P0X0P5 | TDK Corporation | HHM1902B1 | Balun, Multilayer, 2.4–2.5GHz, 50/50Ω, 0.8dB IL, SMD 0402
U2 | 1 | LD1117DT33TR |  |  |  | DPAK456P1010X240-3N | STMicroelectronics | LD1117DT33TR | IC, LDO Regulator, 3.3V, 800mA, Fixed, DPAK (TO-252), T&R
U4,U6,U8,U10 | 4 | MAX2831ETM+T |  |  |  | 21-0144_T4877&plus_4_MXM | Analog Devices (Maxim Integrated) | MAX2831ETM+T | IC, RF Transceiver, 802.11b/g, 2.4–2.5GHz, 21dBm, 48-TQFN, T&R
Q2 | 1 | MMBT3904LT1G |  |  |  | SOT96P237X111-3N | Onsemi | MMBT3904LT1G | These Devices are Pb-Free, Halogen Free/BFR Free and are RoHS Compliant; S Prefix for Automotive and Other Applications Requiring Unique Site and Control Change Requirements; AEC-Q101 Qualified and PPAP Capable
R9,R23,R24,R26,R27,R29,R30,R31,R32,R33,R34,R95,R125,R126 | 14 | 10K |  |  |  | Resistor_SMD:R_0402_1005Metric | Yageo | RC0402FR-0710KL | Res, Thick Film, 10kΩ, 1/16W, 0402, ±1%
R35,R36,R44,R45,R53,R54,R62,R63 | 8 | 10K | DNP |  |  | Resistor_SMD:R_0402_1005Metric | Yageo | RC0402FR-0710KL | Res, Thick Film, 10kΩ, 1/16W, 0402, ±1%
R16,R17 | 2 | 4K7 | DNP |  |  | Resistor_SMD:R_0402_1005Metric | Yageo | RC0402FR-074K7L | Res, Thick Film, 4.7kΩ, 1/16W, 0402, ±1%
R18,R19,R20,R21,R127 | 5 | 100K |  |  |  | Resistor_SMD:R_0402_1005Metric | Yageo | RC0402FR-07100KL | Res, Thick Film, 100kΩ, 1/16W, 0402, ±1%
R28,R71,R72,R73,R74,R75,R76,R77,R78,R98,R99,R100,R101,R102,R103,R104,R105 | 17 | 1K |  |  |  | Resistor_SMD:R_0603_1608Metric | Yageo | RC0603FR-071KL | Res, Thick Film, 1kΩ, 1/10W, 0603, ±1%
R2 | 1 | 10K | DNP |  |  | Resistor_SMD:R_0603_1608Metric | Yageo | RC0603FR-0710KL | Res, Thick Film, 10kΩ, 1/10W, 0603, ±1%
R3,R8 | 2 | 10K |  |  |  | Resistor_SMD:R_0603_1608Metric | Yageo | RC0603FR-0710KL | Res, Thick Film, 10kΩ, 1/10W, 0603, ±1%
R10,R11,R12,R13,R14,R15 | 6 | 33 |  |  |  | Resistor_SMD:R_0603_1608Metric | Yageo | RC0603FR-0733RL | Res, Thick Film, 33Ω, 1/10W, 0603, ±1%
R4 | 1 | 100K |  |  |  | Resistor_SMD:R_0603_1608Metric | Yageo | RC0603FR-07100KL | Res, Thick Film, 100kΩ, 1/10W, 0603, ±1%
R22 | 1 | 100K | DNP |  |  | Resistor_SMD:R_0603_1608Metric | Yageo | RC0603FR-07100KL | Res, Thick Film, 100kΩ, 1/10W, 0603, ±1%
R39,R48,R57,R66 | 4 | 100 |  |  |  | Resistor_SMD:R_0603_1608Metric | Yageo | RC0603FR-07100RL | Res, Thick Film, 100Ω, 1/10W, 0603, ±1%
R87,R88,R89,R90,R91,R92,R93,R94,R114,R115,R116,R117,R118,R119,R120,R121 | 16 | 150 |  |  |  | Resistor_SMD:R_0603_1608Metric | Yageo | RC0603FR-07150RL | Res, Thick Film, 150Ω, 1/10W, 0603, ±1%
R42,R51,R60,R69 | 4 | 750 |  |  |  | Resistor_SMD:R_0603_1608Metric | Yageo | RC0603FR-07750RL | Res, Thick Film, 750Ω, 1/10W, 0603, ±1%
R43,R52,R61,R70 | 4 | 1.2K |  |  |  | Resistor_SMD:R_0603_1608Metric | Yageo | RC0603FR-071K2L | Res, Thick Film, 1.2kΩ, 1/10W, 0603, ±1%
R40,R41,R49,R50,R58,R59,R67,R68,R96,R123 | 10 | 49.9 |  |  |  | Resistor_SMD:R_0603_1608Metric | Yageo | RC0603FR-0749R9L | Res, Thick Film, 49.9Ω, 1/10W, 0603, ±1%
R5 | 1 | 68.1K |  |  |  | Resistor_SMD:R_0603_1608Metric | Yageo | RC0603FR-0768K1L | Res, Thick Film, 68.1kΩ, 1/10W, 0603, ±1%
L1,L2,L3,L4,L5,L6,L7,L8 | 8 | 0 |  |  |  | Inductor_SMD:L_0603_1608Metric | Yageo | RC0603JR-070RL | Res, Thick Film, 0Ω, 1/10W, 0603, Jumper
R1 | 1 | 0 | DNP |  |  | Resistor_SMD:R_0603_1608Metric | Yageo | RC0603JR-070RL | Res, Thick Film, 0Ω, 1/10W, 0603, Jumper
R6,R7,R25,R37,R38,R46,R47,R55,R56,R64,R65,R79,R80,R81,R82,R83,R84,R85,R86,R97,R106,R107,R108,R109,R110,R111,R112,R113,R124 | 29 | 0 |  |  |  | Resistor_SMD:R_0603_1608Metric | Yageo | RC0603JR-070RL | Res, Thick Film, 0Ω, 1/10W, 0603, Jumper
U3 | 1 | SN74AXC4T774RSVR |  |  |  | RSV0016A | Texas Instruments | SN74AXC4T774RSVR | IC, Level Shifter, 4-bit Dual-Supply Bus Transceiver, Bidirectional, Independent Dir Control, Tri-State, 16-UQFN (1.8x2.6mm), T&R
IC3 | 1 | STM32C031K6U6 |  |  |  | QFN50P500X500X60-33N-D | STMicroelectronics | STM32C031K6U6 | IC, MCU, 32-bit ARM Cortex-M0+, 48MHz, 32KB Flash, 12KB RAM, 2x USART, SPI, I2C, ADC, 2–3.6V, 32-UFQFPN
U1 | 1 | TLV9001DBVR |  |  |  | Package_TO_SOT_SMD:SOT-23-5 | Texas Instruments | TLV9001DBVR | R-R I/O, 1MHz, 60µA, 3.3V
J6 | 1 | Conn_01x04_Pin |  |  |  | Connector_PinSocket_2.54mm:PinSocket_1x04_P2.54mm_Vertical | Samtec | TSW-104-07-G-S | Conn, Header, Male, 1x4, 2.54mm Pitch, THT, Vertical, Unshrouded

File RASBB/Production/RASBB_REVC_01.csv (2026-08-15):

Reference | Value | Footprint | Qty | DNP | LCSC Part # | Mfr. Part # | Description
C1,C2,C19,C130,C167,C171 | 1uF | Capacitor_SMD:C_0402_1005Metric | 6 |  | C3889771 | 0402X105M160CT | 16V 1uF X5R ±20% 0402 Multilayer Ceramic Capacitors MLCC - SMD/SMT ROHS
C3,C7 | 10nF | Capacitor_SMD:C_0603_1608Metric | 2 |  | C6119837 | CGA0603X7R103K101JT | ±10% X7R 10nF 100V 0603
C4 | 10uF/100V | Capacitor_SMD:C_1206_3216Metric | 1 |  | C6872041 | C3216X6S2A106K160AC | 100V 10uF X6S ±10% 1206 Multilayer Ceramic Capacitors MLCC - SMD/SMT ROHS
C5,C6 | 4.7uF | Capacitor_SMD:C_1206_3216Metric | 2 |  | C2997285 | GRM31CZ72A475KE11L | 100V 4.7uF X7R ±10% 1206 Multilayer Ceramic Capacitors MLCC - SMD/SMT ROHS
C8 | 22pF | Capacitor_SMD:C_0402_1005Metric | 1 |  | C2175872 | CC0402JRNPO7BN220 | 16V 22pF NP0 ±5% 0402 Multilayer Ceramic Capacitors MLCC - SMD/SMT ROHS
C9 | 4.7nF | Capacitor_SMD:C_0402_1005Metric | 1 |  | C1852867 | CC0402KRX7R6BB472 | 10V 4.7nF X7R ±10% 0402 Multilayer Ceramic Capacitors MLCC - SMD/SMT ROHS
C10,C16,C18,C27,C28,C31,C33,C34,C35,C36,C37,C55,C58,C59,C60,C61,C63,C64,C65,C67,C68,C70,C71,C76,C77,C84,C95,C99,C100,C107,C118,C122,C123,C124,C129,C131,C132,C133,C134,C135,C136,C137,C138,C144,C148,C152,C154,C164,C169,C172,C173,C174,C202,C204,C237,C258,C259,C260,C268,C270,C276,C283,C342,C352,C353,C356,C357,C358,C359,C360,C361,C362,C363,C364 | 100nF | Capacitor_SMD:C_0402_1005Metric | 74 |  | C152814 | 0402B104K500CT | 10V 100nF X7R ±10% 0402 Multilayer Ceramic Capacitors MLCC - SMD/SMT ROHS,50V 100nF X7R ±10% 0402 Multilayer Ceramic Capacitors MLCC - SMD/SMT ROHS
C11,C38,C39,C40,C50,C51,C126,C150,C151 | 10nF | Capacitor_SMD:C_0402_1005Metric | 9 |  | C301927 | 0402B103K500CT | 50V 10nF X7R ±10% 0402 Multilayer Ceramic Capacitors MLCC - SMD/SMT ROHS
C12,C13,C14,C15,C21,C22,C23,C24,C25,C26 | 10uF | Capacitor_SMD:C_1206_3216Metric | 10 |  | C531431 | CGA5L1X7R1H106KT0Y0N | 50V 10uF X7R ±10% 1206 Multilayer Ceramic Capacitors MLCC - SMD/SMT ROHS
C17 | 33uF | RASBB:EEE0JA152UAP | 1 |  | C178581 | EEE-FP1V330AP | Aluminum Electrolytic Capacitors - SMD 33UF 35V ELECT FP SMD
C20,C69,C72,C206,C208,C210,C211,C212,C213,C214,C215,C216,C217,C223,C227,C228,C246,C247,C249,C250,C266,C267,C290,C292,C294,C295,C296,C297,C298,C299,C300,C301,C307,C311,C312,C330,C331,C333,C334,C350,C351 | 4.7uF | Capacitor_SMD:C_0402_1005Metric | 41 |  | C77004 | GRM155R61A475KEAAD | 10V 4.7uF X5R ±10% 0402 Multilayer Ceramic Capacitors MLCC - SMD/SMT ROHS
C29,C98,C115,C121,C127,C128,C175,C186,C279,C365,C366 | 4.7uF | Capacitor_SMD:C_0603_1608Metric | 11 |  | C7281848 | GMK107BBJ475KA-T | 35V 4.7uF X5R ±10% 0603 Multilayer Ceramic Capacitors MLCC - SMD/SMT ROHS
C30,C32,C75,C89,C92,C112,C153,C182,C185,C189,C190,C191,C193,C194,C196,C197,C200,C201,C203,C205,C207,C209,C222,C224,C225,C229,C230,C231,C232,C233,C234,C235,C236,C238,C239,C241,C242,C243,C244,C245,C251,C252,C253,C254,C255,C257,C261,C262,C263,C264,C265,C269,C273,C274,C275,C277,C278,C280,C281,C284,C285,C287,C289,C291,C293,C306,C308,C313,C314,C315,C316,C326,C327,C328,C329,C335,C336,C337,C338,C346,C347,C348,C349 | 470nF | Capacitor_SMD:C_0402_1005Metric | 83 |  | C471404 | GRT155R71A474KE01D | 16V 470nF X7R ±10% 0402 Multilayer Ceramic Capacitors MLCC - SMD/SMT ROHS
C41 | 10pF | Capacitor_SMD:C_0402_1005Metric | 1 |  | C2182752 | C0402C100J4GAC7867 | 16V 10pF C0G ±5% 0402 Multilayer Ceramic Capacitors MLCC - SMD/SMT ROHS
C42,C46,C49,C52,C62,C170,C184,C187,C188,C192,C221,C305 | 47uF | Capacitor_SMD:C_0805_2012Metric | 12 |  | C124129 | GRM21BR61A476ME15L | 10V 47uF X5R ±20% 0805 Multilayer Ceramic Capacitors MLCC - SMD/SMT ROHS
C43 | 5.1pF | Capacitor_SMD:C_0402_1005Metric | 1 |  | C3855079 | GRM1555C1E5R1CA01D | 25V 5.1pF C0G 0402 Multilayer Ceramic Capacitors MLCC - SMD/SMT ROHS
C44,C45,C47,C48,C53,C54,C56,C57,C125,C256 | 22uF | Capacitor_SMD:C_0603_1608Metric | 10 |  | C6776252 | 0603YD226MAT2A | 16V 22uF X5R ±20% 0603 Multilayer Ceramic Capacitors MLCC - SMD/SMT ROHS
C66 | 470pF | Capacitor_SMD:C_0402_1005Metric | 1 |  | C526993 | CC0402JRNPO7BN471 | 16V 470pF NP0 ±5% 0402 Multilayer Ceramic Capacitors MLCC - SMD/SMT ROHS
C73 | 100nF | Capacitor_SMD:C_2220_5750Metric | 1 |  | C5290327 | FV55X104K202EGG | 2kV 100nF X7R ±10% 2220 Multilayer Ceramic Capacitors MLCC - SMD/SMT ROHS
C74,C183 | tbd | Capacitor_SMD:C_1206_3216Metric | 2 | DNP |  |  | CAP, CER, 1nF, 2kV, 10%, X7R, 1210
C78,C79,C80,C81,C82,C83,C85,C86,C87,C88,C90,C91,C93,C94,C96,C97,C101,C102,C103,C104,C105,C106,C108,C109,C110,C111,C113,C114,C116,C117,C119,C120,C162,C317,C339 | 47nF | Capacitor_SMD:C_0402_1005Metric | 35 |  | C2178375 | C0402C473J8RAC7867 | 10V 47nF X7R ±5% 0402 Multilayer Ceramic Capacitors MLCC - SMD/SMT ROHS
C139,C140,C145,C149 | 20p | Capacitor_SMD:C_0402_1005Metric | 4 |  | C123468 | 0402N200J500CT | 50V 20pF NP0 ±5% 0402 Multilayer Ceramic Capacitors MLCC - SMD/SMT ROHS
C141,C143 | 2.2uF | Capacitor_SMD:C_0402_1005Metric | 2 |  | C3905586 | 0402X225M160CT | 16V 2.2uF X5R ±20% 0402 Multilayer Ceramic Capacitors MLCC - SMD/SMT ROHS
C142,C146,C147 | 10uF | Capacitor_SMD:C_0402_1005Metric | 3 |  | C2992625 | 0402X106M100CT | 10V 10uF X5R ±20% 0402 Multilayer Ceramic Capacitors MLCC - SMD/SMT ROHS
C155 | 0.8pF | Capacitor_SMD:C_0402_1005Metric | 1 |  | C396870 | RF15N0R8B500CT | 50V 0.8pF NP0 0402 Multilayer Ceramic Capacitors MLCC - SMD/SMT ROHS
C156,C158 | 1.2pF | Capacitor_SMD:C_0402_1005Metric | 2 |  | C301969 | 0402N1R2C500CT | 50V 1.2pF NP0 0402 Multilayer Ceramic Capacitors MLCC - SMD/SMT ROHS
C157 | 0.5pF | Capacitor_SMD:C_0402_1005Metric | 1 |  | C2918554 | RT15N0R5B500CT | 50V 0.5pF NP0 0402 Multilayer Ceramic Capacitors MLCC - SMD/SMT ROHS
C159,C163 | 100pF | Capacitor_SMD:C_0402_1005Metric | 2 |  | C387967 | 0402N101G500CT | 50V 100pF NP0 ±2% 0402 Multilayer Ceramic Capacitors MLCC - SMD/SMT ROHS
C160,C161,C166 | 10uF | Capacitor_SMD:C_0603_1608Metric | 3 |  | C4555498 | 0603X106M250CT | 25V 10uF X5R ±20% 0603 Multilayer Ceramic Capacitors MLCC - SMD/SMT ROHS
C165 | UUD1A221MCL1GS | RASBB:CAPAE660X800N | 1 |  | C445275 | UUD1A221MCL1GS | 220uF 10V 280mA@100kHz 340mΩ@100kHz ±20% SMD,D6.3xL7.7mm Aluminum Electrolytic Capacitors - SMD ROHS
C168,C176 | 10p | Capacitor_SMD:C_0402_1005Metric | 2 |  | C301961 | 0402N100J500CT | 10pF 50V C0G/NP0 ±5% 0402 Multilayer Ceramic Capacitors MLCC - SMD/SMT ROHS
C177,C178,C179,C180 | 10p/50V | Capacitor_SMD:C_0603_1608Metric | 4 |  | C152928 | 0603N100J500CT | 10pF 50V C0G/NP0 ±5% 0603Multilayer Ceramic Capacitors MLCC - SMD/SMT ROHS
C181 | 1nF | Capacitor_SMD:C_1206_3216Metric | 1 |  | C303946 | 1206B102K202CT | 2kV 1nF X7R ±10% 1206 Multilayer Ceramic Capacitors MLCC - SMD/SMT ROHS
C195,C198,C199,C218,C220,C226,C248,C282,C302,C303,C304,C310,C332 | 100uF | Capacitor_SMD:C_1206_3216Metric | 13 |  | C883598 | GRM31CR61A107MEA8L | 10V 100uF X5R ±20% 1206 Multilayer Ceramic Capacitors MLCC - SMD/SMT ROHS
C219 | 100uF | Capacitor_SMD:C_1206_3216Metric | 1 | DNP | C883598 | GRM31CR61A107MEA8L | 10V 100uF X5R ±20% 1206 Multilayer Ceramic Capacitors MLCC - SMD/SMT ROHS
C271 | 2200pF | Capacitor_SMD:C_0402_1005Metric | 1 | DNP |  |  | Cap, MLCC, 2200pF, 50V, C0G/NP0, 0402, ±5%
C272 | 2200pF | Capacitor_SMD:C_0402_1005Metric | 1 |  | C1531 | 0402B222K500NT | Cap, MLCC, 2200pF, 50V, C0G/NP0, 0402, ±5%
C354,C355 | 2.2uF | Capacitor_SMD:C_0805_2012Metric | 2 |  | C2918681 | 0805B225K500CT | 50V 2.2uF X7R ±10% 0805 Multilayer Ceramic Capacitors MLCC - SMD/SMT ROHS
D1 | SDT5A60SA-13 | RASBB:SDT5A60SA13 | 1 |  | C3024223 | SDT5A60SA-13 | Diode 60 V 5A Surface Mount SMA
D2,D3 | VSSAF5L45HM3_A_H | RASBB:SODFL5226X100N | 2 |  | C6000165 | VSSAF5L45HM3_A/H | Schottky Diodes & Rectifiers TMBS 45V Vrrm eSMP AEC-Q101 Qualified
D4,D5,D26 | DF1501S-T | RASBB:DF1501ST | 3 |  | C155338 | DF1501S-T | 50A 1.1V@1.5A 1.5A 100V DF-S Bridge Rectifiers ROHS
D6 | S210_R1_00001 | Diode_SMD:D_SMB | 1 |  | C391676 | S210_R1_00001 | 2A Independent Type 100V 660mV@2A SMB(DO-214AA) Diodes - General Purpose ROHS
D7,D13,D14,D15,D16 | A-SP192YR6C-C01-4T | LED_SMD:LED_0603_1608Metric | 5 |  | C5355433 | A-SP192YR6C-C01-4T | 5mA Colorless Transparent Lens 72mcd 616nm~624nm -40℃~+85℃ Positive Stick Red 120° 60mW 1.7V~2.2V 0603 LED Indication - Discrete ROHS
D8,D17,D18,D19,D20,D21,D22,D25 | A-SP192DGHC-C01-4T | LED_SMD:LED_0603_1608Metric | 8 |  | C19171301 | A-SP192DGHC-C01-4T | 225mcd~450mcd Colorless Transparent Lens -40℃~+85℃ Positive Stick 520nm~535nm Green 120° 70mW 2.4V~3V 0603 LED Indication - Discrete ROHS
D9,D23,D24 | A-SP192GS1D-C01-4T | LED_SMD:LED_0603_1608Metric | 3 |  | C5355434 | A-SP192GS1D-C01-4T | 5mA 285mcd Frosted Orange Lens -40℃~+85℃ 592nm~600nm Positive Stick Orange 130° 20mW 2.4V~3V 0603 LED Indication - Discrete ROHS
D10 | D5V0F4U6SO-7 | RASBB:SOT95P285X140-6N | 1 |  | C445539 | D5V0F4U6SO-7 | 3A@8/20us 12V 6V Unidirectional 5.5V SOT-26 ESD and Surge Protection (TVS/ESD) ROHS
D11,D12 | DT2042-04SO-7 | RASBB:SOT95P285X140-6N | 2 |  | C2841428 | DT2042-04SO-7 | Diodes Inc DT2042-04SO-7 Quad Uni-Directional TVS Diode Array, 300mW peak, 6-Pin SOT-26
D27 | SMAJ33A | DIOM5026X229N | 1 |  | C223988 | SMAJ33A | 33V 400W 53.3V 7.5A SMA(DO-214AC) Uni-Directional TVS Voltage Suppressors / Diodes ROHS
F1 | Polyfuse 1.5A | RASBB:BSMD1812 | 1 |  | C883154 | BSMD1812-150-33V | PTC RESET FUSE 33V 1.5A 1812
F2 | Polyfuse 2A | RASBB:BSMD1812 | 1 |  | C960026 | BSMD1812-200-30V | PTC RESET FUSE 30V 2A 1812
FB1,FB2,FB3 | BLM15BD601SH1D | RASBB:NFZ15SG152SN10B | 3 |  | C710334 | BLM15BD601SH1D | BLM15_H1D Series EMI Suppression Filter 600+/-25% at 100MHz 200mA @85
IC1 | RT6365GSP | RASBB:SOIC127P600X175-9N | 1 |  | C3024482 | RT6365GSP | Switching Voltage Regulators 60VIN, 5A, Asynchronous Step-Down Converter with Low Quiescent Current
IC2,IC4 | TPS56528DDAR | RASBB:SOIC127P600X170-9N | 2 |  | C138716 | TPS56528DDAR | 4.5V to 18V Input, 5-A Synchronous Step-Down Converter with Advanced Eco-mode&#153;
IC3 | TPS563201DDCR | RASBB:SOT95P280X110-6N | 1 |  | C116592 | TPS563201DDCR | 4.5 V to 17 V input, 3 A output, synchronous step-down converter in Eco-mode
IC5,IC7 | S25FL128LAGMFI010 | RASBB:SOIC127P800X216-8N | 2 |  | C2959152 | S25FL128LAGMFI010 | CYPRESS SEMICONDUCTOR - S25FL128LAGMFI010 - FLASH MEMORY, 128MBIT, 133MHZ, SOIC-8
IC6,IC8 | TS3A5018DBQR | RASBB:SOP64P600X175-16N | 2 |  | C202285 | TS3A5018DBQR | Analog SW Quad SPDT 3.6V 16-Pin SSOP Texas Instruments TS3A5018DBQR, Analogue SPDT Switch Quad SPDT, 3 V, 16-Pin SSOP
IC9,IC10 | MT41K128M16JT-107:K | RASBB:BGA96C80P9X16_800X1400X120 | 2 |  | C2841151 | MT41K128M16JT-107:K | IC DRAM 2GBIT PAR 96FBGA
IC11 | TPD12S016PWR | RASBB:SOP65P640X120-24N | 1 |  | C201665 | TPD12S016PWR | Texas Instruments,TPD12S016PWR,IC,HDMI TPD12S016PWR, HDMI Interface 12-channel HDMI 4.5
IC12 | STM32H743VGT6 | RASBB:QFP50P1600X1600X160-100N | 1 |  | C730183 | STM32H743VGT6 | STM32H743VGT6
IC13 | SX1280IMLTRT | RASBB:QFN50P400X400X100-25N-D | 1 |  | C125969 | SX1280IMLTRT | RF Transceiver Long range 2.4 GHz Wireless Transceiver
IC14 | LAN8742AI-CZ-TR | RASBB:QFN50P400X400X100-25N-D | 1 |  | C621425 | LAN8742AI-CZ-TR | VQFN-24-EP(4x4) Buffers, Drivers, Receivers, Transceivers ROHS
IC15 | DS90LV028AQDQFRQ1 | RASBB:SON50P200X200X80-8N | 1 |  | C2868409 | DS90LV028AQDQFRQ1 | LVDS Driver 5-Pin SOT-23 T/R
J1 | PJ-002AH-SMT-TR | RASBB:CUI_PJ-002AH-SMT-TR | 1 |  | C22434687 | PJ-002AH-SMT-TR | SMD DC Power Connectors ROHS
J2 | HR911196AE | RASBB:JK00229NL | 1 |  | C5149194 | HR911196AE | Plugin Ethernet Connectors / Modular Connectors (RJ45 RJ11) ROHS
J3 | HDMI-001A | RASBB:HDMI-001A | 1 |  | C41347845 | HDMI-001A | Push-Pull HDMI Connectors ROHS
J4 | X3157WS-98-9TV30 | RASBB:SAMTEC_PCIE-098-02-X-D-EMS3 | 1 |  | C5711253 | X3157WS-98-9TV30 | Plugin PCI / PCIe Connector ROHS
J5 | FH12-50S-0.5SV | RASBB:CON50_1X50_DUTB_HRS_HIR | 1 |  | C597991 | FH12-50S-0.5SVA(54) | CONN FFC FPC 50POS 0.5mm VERTICAL - 1 SIDED CNT SMD
J7 | USB_C_Receptacle | Connector_USB:USB_C_Receptacle_Palconn_UTC16-G | 1 |  | C2765186 | TYPE-C 16PIN 2MD(073) | USB Full-Featured Type-C Receptacle connector
J8,J10 | ZX-PZ1.27-2-5PWZ | Connector_PinHeader_1.27mm:PinHeader_2x05_P1.27mm_Vertical_SMD | 2 |  | C41370773 | ZX-PZ1.27-2-5PWZ | https://www.lcsc.com/datasheet/lcsc_datasheet_2408280907_Megastar-ZX-PZ1-27-2-5PWZ_C41370773.pdf
J9 | KF2EDGR-3.5-2P | RASBB:SHDRRA2W80P0X350_1X2_1050X920X750P | 1 |  | C441171 | KF2EDGR-3.5-2P | Bend -40℃~+105℃ 1 3.5mm 300V 10A 2 1x2P Green Receptacle-Close Push-Pull,P=3.5mm Pluggable System Terminal Block ROHS
J11 | Conn_Coaxial | Connector_Coaxial:U.FL_Hirose_U.FL-R-SMT-1_Vertical | 1 |  | C22418213 | CONUFL001-SMD-T or similar | coaxial connector (BNC, SMA, SMB, SMC, Cinch/RCA, LEMO, ...)
J12 | AudioJack4 | RASBB:FC68128 | 1 |  | C7501803 | HC-PJ-313E8-B-SMT | -25℃~+70℃ 3.5mm Headphone Jack 30V Nickel 500mA Phosphor Bronze SMD Audio Connectors ROHS
J13,J15 | Conn_01x06_Socket | Connector_PinHeader_1.27mm:PinHeader_2x03_P1.27mm_Vertical_SMD | 2 |  | C41370771 | ZX-PZ1.27-2-3PWZ | Gold 1A Standing paste Policy 1mm 6P 4mm -40℃~+105℃ 1.27mm Brass Double Row Black 2x3P 1.27mm SMD,P=1.27mm Pin Headers ROHS
J14 | 636101112001 | RASBB:J_Wurth_WR-UMRF_636101112001 | 1 |  |  | 636101112001 | PCB Receptacle with 3 Pads
J16,J17,J18,J20 | Conn_01x02_Pin | Connector_PinHeader_2.54mm:PinHeader_1x02_P2.54mm_Vertical | 4 |  | C492401 | PZ254V-11-02P | Generic connector, single row, 01x02, script generated
J19 | HC-WK88-H16-DB | RASBB:HC-WK88-H16-DB | 1 |  | C7501824 | HC-WK88-H16-DB | CONN MOD JACK RJ45 TH R/A SHIELDED
L1 | 10uH | RASBB:0630CDMCDDS-100MC | 1 |  | C2595948 | 0630CDMCDDS-100MC | 4.5A 10uH ±20% 4.6A 2726 Power Inductors ROHS
L2 | 15uH | RASBB:SMDRS6028-150N | 1 |  | C163563 | SMDRS6028-150N | 1A 15uH Shielded inductor ±30% 1A SMD Power Inductors ROHS
L3 | 360nH | RASBB:INDPM109103X400N | 1 |  | C845083 | IHLP4040DZERR36M01 | 31.5A 360nH ±20% 60A SMD,10.8x10.2mm Power Inductors ROHS
L4,L5,L6 | 2.2uH | RASBB:IND_IHLP-2525CZ_VIS | 3 |  | C845037 | IHLP2525EZER2R2M01 | 10A 2.2uH ±20% 10A SMD,6.5x6.9mm Power Inductors ROHS
L7 | 2.2uH | Inductor_SMD:L_1206_3216Metric | 1 |  | C486337 | microgate MGFL3216F2R2MT-LF | 1.3A 2.2uH ±20% 150mΩ 1206 Inductors (SMD) ROHS
L8,L11 | BLM41PG102SN1L | RASBB:IND_BLM41_1806_MUR-M | 2 |  | C88999 | BLM41PG102SN1L | 90mΩ ±25% 1kΩ@100MHz 1806 Ferrite Beads ROHS
L9 | 3nH | Inductor_SMD:L_0402_1005Metric | 1 |  | C433005 | MHQ1005P3N0BT000 | 3nH 800mA ±0.1nH 0402 High Frequency / RF Inductors - Surface Mount ROHS
L10 | 2.5nH | Inductor_SMD:L_0402_1005Metric | 1 |  | C317668 | FHW0402UC2N5KST | 640mA 2.5nH ±10% 120mΩ 0402 Inductors (SMD) ROHS
Q1 | DMN6075S | Package_TO_SOT_SMD:SOT-23 | 1 |  | C5122015 | DMN6075S | 60V 3A 350mW 125mΩ@4.5V,3A 500mV@250uA SOT-23 MOSFETs ROHS
R1,R2,R3,R4,R6,R7,R8,R11,R12,R13,R14,R15,R16,R22,R72,R73,R139,R140,R141,R142,R152,R153,R154,R155,R157,R158,R159,R160,R161,R162,R163,R166,R167 | 49.9 | Resistor_SMD:R_0402_1005Metric | 33 |  | C4229190 | RMCF0402FT49R9 | 62.5mW Thick Film Resistors ±100ppm/℃ ±1% 49.9Ω 0402 Chip Resistor - Surface Mount ROHS
R5,R53,R54,R55,R56,R85,R86,R91,R92,R103,R196,R197,R198,R199,R204,R207 | 4K7 | Resistor_SMD:R_0402_1005Metric | 16 |  | C105871 | RC0402FR-074K7L | 62.5mW Thick Film Resistors 50V ±100ppm/℃ ±1% 4.7kΩ 0402 Chip Resistor - Surface Mount ROHS
R9,R10,R57,R58,R59,R60,R61,R62,R74,R76,R101,R107,R114,R115,R116,R117,R118,R119,R120 | 4.7K | Resistor_SMD:R_0402_1005Metric | 19 |  | C163826 | WR04X4701FTL | 62.5mW Thick Film Resistors 50V ±100ppm/℃ ±1% 4.7kΩ 0402 Chip Resistor - Surface Mount ROHS
R17,R18,R19,R20,R23,R24,R99,R100 | 22 | Resistor_SMD:R_0402_1005Metric | 8 |  | C163821 | WR04X22R0FTL | 62.5mW Thick Film Resistors 50V ±100ppm/℃ ±1% 22Ω 0402 Chip Resistor - Surface Mount ROHS
R21,R63,R64,R65,R66,R68,R69,R70,R71,R87,R93,R187,R188,R189,R190 | 100 | Resistor_SMD:R_0402_1005Metric | 15 |  | C163808 | WR04X1000FTL | 62.5mW Thick Film Resistors 50V ±100ppm/℃ ±1% 100Ω 0402 Chip Resistor - Surface Mount ROHS
R25 | 24.9K | Resistor_SMD:R_1206_3216Metric | 1 |  | C171074 | WR12X2492FTL | 250mW Thick Film Resistors 200V ±100ppm/℃ ±1% 24.9kΩ 1206 Chip Resistor - Surface Mount ROHS
R26 | 249K | Resistor_SMD:R_0805_2012Metric | 1 |  | C170853 | WR08X2493FTL | 125mW Thick Film Resistors 150V ±100ppm/℃ ±1% 249kΩ 0805 Chip Resistor - Surface Mount ROHS
R27,R123 | 51K | Resistor_SMD:R_0603_1608Metric | 2 |  | C227390 | WR06X5102FTL | 100mW Thick Film Resistors 75V ±100ppm/℃ ±1% 51kΩ 0603 Chip Resistor - Surface Mount ROHS
R28 | 590K | Resistor_SMD:R_0402_1005Metric | 1 |  | C172103 | WR04X5903FTL | 62.5mW Thick Film Resistors 50V ±100ppm/℃ ±1% 590kΩ 0402 Chip Resistor - Surface Mount ROHS
R29,R30 | 18K | Resistor_SMD:R_0402_1005Metric | 2 |  | C168206 | WR04X1802FTL | 62.5mW Thick Film Resistors 50V ±100ppm/℃ ±1% 18kΩ 0402 Chip Resistor - Surface Mount ROHS
R31 | 120K | Resistor_SMD:R_0402_1005Metric | 1 |  | C137924 | RC0402JR-07120KL | 62.5mW Thick Film Resistors 50V ±100ppm/℃ ±5% 120kΩ 0402 Chip Resistor - Surface Mount ROHS
R32,R44 | 3.3 | Resistor_SMD:R_0402_1005Metric | 2 |  | C384380 | CRCW04023R30FKEDC | 62.5mW Thick Film Resistors ±100ppm/℃ ±1% 3.3Ω 0402 Chip Resistor - Surface Mount ROHS
R33 | 180K | Resistor_SMD:R_0402_1005Metric | 1 |  | C168207 | WR04X1803FTL | 62.5mW Thick Film Resistors 50V ±100ppm/℃ ±1% 180kΩ 0402 Chip Resistor - Surface Mount ROHS
R34 | 12K | Resistor_SMD:R_0402_1005Metric | 1 |  | C2991361 | SR04X1202FTL | 100mW Thick Film Resistors 50V ±100ppm/℃ ±1% 12kΩ 0402 Chip Resistor - Surface Mount ROHS
R35,R41,R42,R43,R49,R125,R126 | 100K | Resistor_SMD:R_0402_1005Metric | 7 | DNP | C60491 | RC0402FR-07100KL | 62.5mW Thick Film Resistors 50V ±100ppm/℃ ±1% 100kΩ 0402 Chip Resistor - Surface Mount ROHS
R36 | 220K | Resistor_SMD:R_0402_1005Metric | 1 |  | C25767 | 0402WGF2203TCE | 62.5mW Thick Film Resistors 50V ±100ppm/℃ ±1% 220kΩ 0402 Chip Resistor - Surface Mount ROHS
R37 | 100K | Resistor_SMD:R_0402_1005Metric | 1 |  | C60491 | RC0402FR-07100KL | 62.5mW Thick Film Resistors 50V ±100ppm/℃ ±1% 100kΩ 0402 Chip Resistor - Surface Mount ROHS
R38 | 5.49K | Resistor_SMD:R_0402_1005Metric | 1 |  | C2092200 | CRCW04025K49FKED | 62.5mW Thick Film Resistors 50V ±1% ±100ppm/℃ 5.49kΩ 0402 Chip Resistor - Surface Mount ROHS
R39 | 2.32K | Resistor_SMD:R_0402_1005Metric | 1 |  | C2091739 | CRCW04022K32FKED | 62.5mW Thick Film Resistors 50V ±1% ±100ppm/℃ 2.32kΩ 0402 Chip Resistor - Surface Mount ROHS
R40 | 3.48K | Resistor_SMD:R_0402_1005Metric | 1 |  | C4336043 | CRCW04023K48FKED | 63mW Thick Film Resistors ±100ppm/℃ ±1% 3.48kΩ 0402 Chip Resistor - Surface Mount ROHS
R45 | 11K | Resistor_SMD:R_0402_1005Metric | 1 |  | C172152 | WR04X113JTL | 62.5mW Thick Film Resistors 50V ±100ppm/℃ ±5% 11kΩ 0402 Chip Resistor - Surface Mount ROHS
R46 | 2.1K | Resistor_SMD:R_0402_1005Metric | 1 |  | C170256 | WR04X2101FTL | 62.5mW Thick Film Resistors 50V ±100ppm/℃ ±1% 2.1kΩ 0402 Chip Resistor - Surface Mount ROHS
R47 | 7.68k | Resistor_SMD:R_0402_1005Metric | 1 |  | C334733 | WR04X7681FTL | 62.5mW Thick Film Resistors 50V ±100ppm/℃ ±1% 7.68kΩ 0402 Chip Resistor - Surface Mount ROHS
R48,R67,R96,R104,R105,R106,R111,R112,R113,R124,R132,R133,R135,R137,R156,R164,R191,R192,R193,R194,R202 | 10K | Resistor_SMD:R_0402_1005Metric | 21 |  | C163810 | WR04X1002FTL | 62.5mW Thick Film Resistors 50V ±100ppm/℃ ±1% 10kΩ 0402 Chip Resistor - Surface Mount ROHS
R50,R52 | 49.9K | Resistor_SMD:R_0402_1005Metric | 2 |  | C350874 | CRCW040249K9FKED | 62.5mW Thick Film Resistors 50V ±1% ±100ppm/℃ 49.9kΩ 0402 Chip Resistor - Surface Mount ROHS
R51 | 226K | Resistor_SMD:R_0402_1005Metric | 1 |  | C2076623 | CRCW0402226KFKED | 62.5mW Thick Film Resistors 50V ±1% ±100ppm/℃ 226kΩ 0402 Chip Resistor - Surface Mount ROHS
R75,R88,R89,R94,R95,R108,R109,R110,R131,R138,R146,R147,R148,R149 | 1K | Resistor_SMD:R_0402_1005Metric | 14 |  | C327796 | MR04X1001FTL | 100mW Thick Film Resistors 50V ±100ppm/℃ ±1% 1kΩ 0402 Chip Resistor - Surface Mount ROHS
R77,R136,R205,R206 | 1.5K | Resistor_SMD:R_0402_1005Metric | 4 |  | C384376 | WR04X152JTL | 62.5mW Thick Film Resistors 50V ±100ppm/℃ ±5% 1.5kΩ 0402 Chip Resistor - Surface Mount ROHS
R78,R79,R80,R81,R144,R145 | 75 | Resistor_SMD:R_0603_1608Metric | 6 |  | C2074227 | ESR03EZPF75R0 | 250mW Thick Film Resistors 150V ±100ppm/℃ ±1% 75Ω 0603 Chip Resistor - Surface Mount ROHS
R82,R83,R186 | 270 | Resistor_SMD:R_0402_1005Metric | 3 |  | C880838 | SR04X271JTL | 62.5mW ±100ppm/℃ ±5% 270Ω 0402 Chip Resistor - Surface Mount ROHS
R84,R90 | 240 | Resistor_SMD:R_0402_1005Metric | 2 |  | C728568 | RT0402BRE07240RL | 62.5mW Thin Film Resistor 50V ±50ppm/℃ ±0.1% 240Ω 0402 Chip Resistor - Surface Mount ROHS
R97,R98 | 5.1K | Resistor_SMD:R_0402_1005Metric | 2 |  | C384321 | WR04X512JTL | 62.5mW Thick Film Resistors 50V ±100ppm/℃ ±5% 5.1kΩ 0402 Chip Resistor - Surface Mount ROHS
R102 | 0 | Resistor_SMD:R_0402_1005Metric | 1 |  | C396825 | MR04X000PTL | 100mW Thick Film Resistors 50V -200ppm/℃~+400ppm/℃ 0Ω 0402 Chip Resistor - Surface Mount ROHS
R121 | 1.2K | Resistor_SMD:R_0402_1005Metric | 1 |  | C168197 | WR04X1201FTL | 62.5mW Thick Film Resistors 50V ±100ppm/℃ ±1% 1.2kΩ 0402 Chip Resistor - Surface Mount ROHS
R122 | 10 | Resistor_SMD:R_0402_1005Metric | 1 |  | C25077 | 0402WGF100JTCE | 62.5mW Thick Film Resistors 50V ±1% ±200ppm/℃ 10Ω 0402 Chip Resistor - Surface Mount ROHS
R127 | 5.6K | Resistor_SMD:R_0402_1005Metric | 1 |  | C168239 | WR04X5601FTL | 62.5mW Thick Film Resistors 50V ±100ppm/℃ ±1% 5.6kΩ 0402 Chip Resistor - Surface Mount ROHS
R128,R129,R130 | 715 | Resistor_SMD:R_0402_1005Metric | 3 |  | C334727 | WR04X7150FTL | 62.5mW Thick Film Resistors 50V ±100ppm/℃ ±1% 715Ω 0402 Chip Resistor - Surface Mount ROHS
R134 | 12.1K | Resistor_SMD:R_0402_1005Metric | 1 |  | C168199 | WR04X1212FTL | 62.5mW Thick Film Resistors 50V ±100ppm/℃ ±1% 12.1kΩ 0402 Chip Resistor - Surface Mount ROHS
R143 | 0 | Resistor_SMD:R_0603_1608Metric | 1 |  | C2094997 | RCS06030000Z0EC | 250mW Thick Film Resistors 75V 0Ω 0603 Chip Resistor - Surface Mount ROHS
R150 | 0 | Resistor_SMD:R_0603_1608Metric | 1 | DNP |  |  | Res, Thick Film, 0Ω, 1/10W, 0603, Jumper
R151 | 10K | Resistor_SMD:R_0603_1608Metric | 1 | DNP |  |  | Res, Thick Film, 10kΩ, 1/10W, 0603, ±1%
R165 | 0.005 | Resistor_SMD:R_2512_6332Metric | 1 |  | C7419996 | FRM252WJR005TN | 2W 5mΩ Current Sensing Resistors ±50ppm/℃ ±5% 2512 Current Sense Resistors / Shunt Resistors ROHS
R168,R169,R170,R171,R172,R173,R174,R175,R176,R177,R178,R179,R180,R181,R182,R183,R184 | 100 | Resistor_SMD:R_0201_0603Metric | 17 |  | C367410 | WR02X1000FTL | 50mW 25V ±100ppm/℃ ±1% 100Ω 0201 Chip Resistor - Surface Mount ROHS
R185 | 0 | Resistor_SMD:R_1206_3216Metric | 1 |  | C17888 | 1206W4F0000T5E | 250mW Thick Film Resistors 200V 0Ω 1206 Chip Resistor - Surface Mount ROHS
R195,R200,R201 | 10K | Resistor_SMD:R_0603_1608Metric | 3 |  | C25804 | 0603WAF1002T5E | Res, Thick Film, 10kΩ, 1/10W, 0603, ±1%
R203 | 2.49K | Resistor_SMD:R_0402_1005Metric | 1 |  | C114768 | RC0402FR-072K49L | 62.5mW Thick Film Resistors 50V ±100ppm/℃ ±1% 2.49kΩ 0402 Chip Resistor - Surface Mount ROHS
RN1,RN2,RN3,RN4,RN5,RN6,RN7,RN8,RN9,RN10 | CAY10-330J4LF | RASBB:CAY10-XXXJ4 | 10 |  | C1731024 | CAY10-330J4LF | Bourns CAY10 Series 33 +/-5% Isolated SMT Resistor Array, 4 Resistors, 0.125W total 0804 (2010M) package Convex
S1,S2,S3 | B3FS-1002P | RASBB:B3FS-1000P | 3 |  | C271750 | B3FS-1002P | Tactile Switches 6x6x3.1mm Flat 150OF PhosphorBronze Ag TR
SW1,SW2 | 435451019820 | RASBB:J_Wurth_WR-UMRF_636101112001 | 2 |  |  | 435451019820 | SMT Washable Tact Switch 4.1 x 2.8 mm
T1 | 15FB-30NL | RASBB:SOIC127P940X597-16N | 1 | DNP | C2987675 | 15FB-30NL | Power over Ethernet (POE+) Magnetics, 10/100BASE-TX VoIP Magnetics Modules
TP1,TP2,TP3,TP4,TP5,TP6,TP7,TP8,TP9,TP10,TP11,TP12,TP13,TP14,TP15,TP16,TP17,TP18,TP19,TP20,TP21,TP22 | TestPoint | TestPoint:TestPoint_Pad_D1.0mm | 22 | DNP |  |  | test point
TP23 | 125M | TestPoint:TestPoint_Pad_D1.0mm | 1 | DNP |  |  | test point
U1 | SZMMSZ4702T1G | RASBB:SOD-123_ONS | 1 |  | C463904 | SZMMSZ4702T1G | 500mW 15V SOD-123 Zener Diodes ROHS
U2 | SI2324DS-T1-GE3 | RASBB:SOT_4DS-T1-GE3_VIS | 1 |  | C190351 | SI2324DS-T1-GE3 | 100V 2.3A 1.6W 0.234Ω@10V,2.3A 2.8V@250uA SOT-23 MOSFETs ROHS
U3 | SIC453ED-T1-GE3 | RASBB:POWERPAK_MLP34-57_VIS | 1 |  | C5334327 | SIC453ED-T1-GE3 | https://www.lcsc.com/datasheet/lcsc_datasheet_2212301230_Vishay-Intertech-SIC453ED-T1-GE3_C5334327.pdf
U4 | JW5026 | Package_TO_SOT_SMD:SOT-23-6 | 1 |  | C185109 | JW5026 | Step-down type 1A SOT-23-6 DC-DC Converters ROHS
U5 | TLV9001DBVR | Package_TO_SOT_SMD:SOT-23-5 | 1 |  |  | TLV9001QDBVRQ1 | R-R I/O, 1MHz, 60µA, 3.3V
U6 | CH340E | Package_SO:MSOP-10-1EP_3x3mm_P0.5mm_EP1.68x1.88mm | 1 |  | C99652 | CH340E | 2Mbps Transceiver USB 2.0 MSOP-10 USB Converters ROHS
U7 | AHT20 | RASBB:AHT20 | 1 |  | C2757850 | AHT20 | SMD Temperature and Humidity Sensor ROHS
U8 | LM386 | Package_SO:SOP-8_3.9x4.9mm_P1.27mm | 1 |  | C510560 | LM386D | SOP-8 Audio Amplifiers ROHS
U9 | LM321 | Package_TO_SOT_SMD:SOT-23-5 | 1 |  | C280706 | LM321-TR | Low Power Single Operational Amplifier, SOT-23-5
U10,U11 | XC7A100T-CSG324 | RASBB:BGA324C80P18X18_1500X1500X150 | 2 |  | C1521791 | XC7A100T-2CSG324I | Artix 7 T 100 XC7A100T-CSG324
U12 | RTL8211E-VB-CG | RASBB:QFN48_6X6X0P85_RTK | 1 |  | C90735 | RTL8211E-VB-CG | 4 PHYtransceiver QFN-48-EP(6x6) Ethernet Transceivers ROHS
X1,X3,X4 | OT2EL4C4JI-111OLP-50M | Oscillator:Oscillator_SMD_Abracon_ASE-4Pin_3.2x2.5mm | 3 |  | C5203552 | OT2EL4C4JI-111OLP-50M | 1.8V~3.3V ±10ppm CMOS 50MHz SMD3225-4P Crystal Oscillator
Y1 | X503220MSB2GI | RASBB:X503220MSB2GI | 1 |  | C112566 | X503220MSB2GI | 20MHz Surface Mount Crystal 20pF ±10ppm ±20ppm SMD5032 Crystals ROHS
Y2 | XC21M4-52.000-F10NNHPL | RASBB:XC21M4-52.000-F10NNHPL | 1 |  | C3034316 | XC21M4-52.000-F10NNHPL | 52MHz Surface Mount Crystal 10pF ±10ppm ±10ppm SMD2016-4P Crystals ROHS
Y3 | 25MHz | Crystal:Crystal_SMD_3225-4Pin_3.2x2.5mm | 1 |  | C5280577 | XL2EL89CSI-111YLC-25M | Four pin crystal, GND on pins 2 and 3
Z1 | MMSZ5255BT1G | RASBB:SOD3716X135N | 1 |  | C242284 | MMSZ5255BT1G | Independent Type 26.6V~29.4V 500mW 28V SOD-123 Zener Diodes ROHS

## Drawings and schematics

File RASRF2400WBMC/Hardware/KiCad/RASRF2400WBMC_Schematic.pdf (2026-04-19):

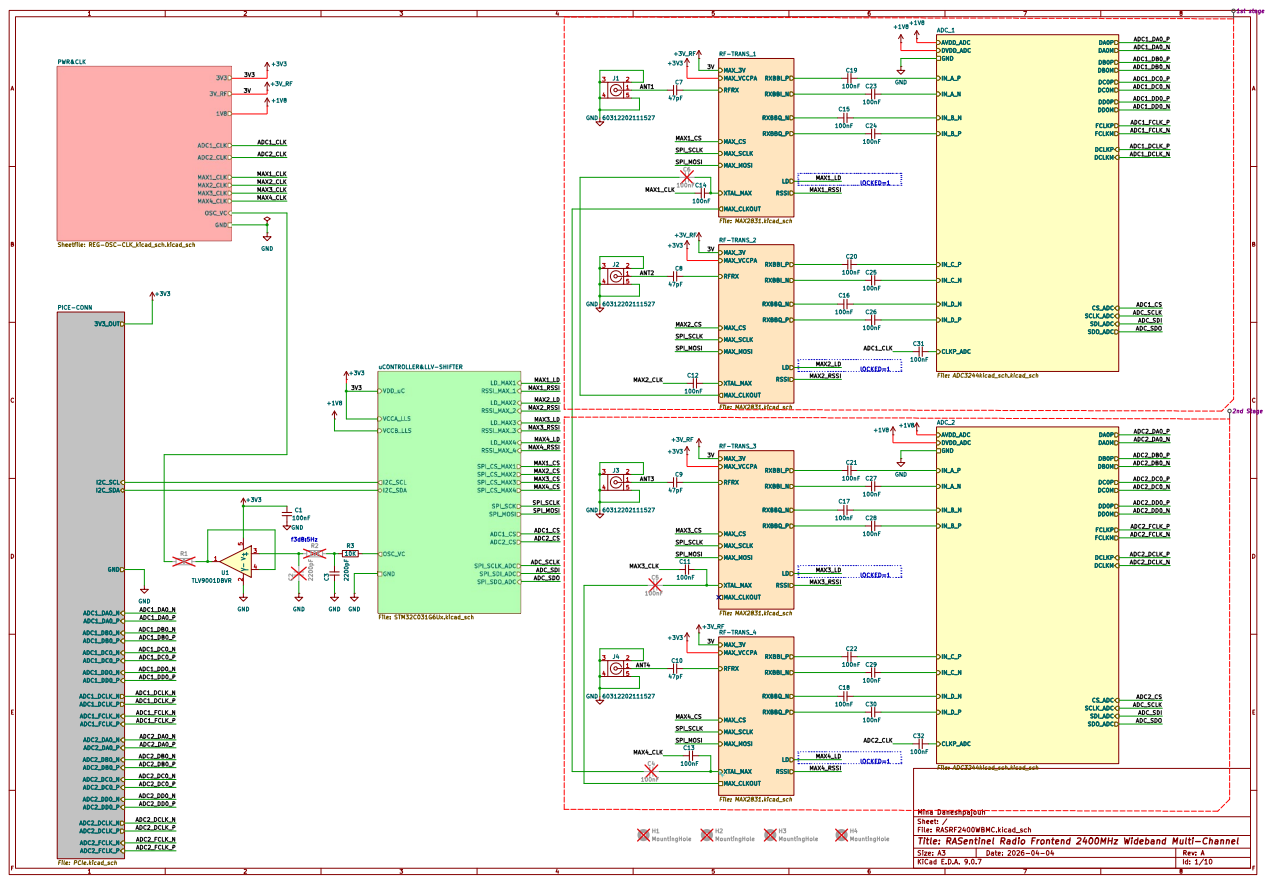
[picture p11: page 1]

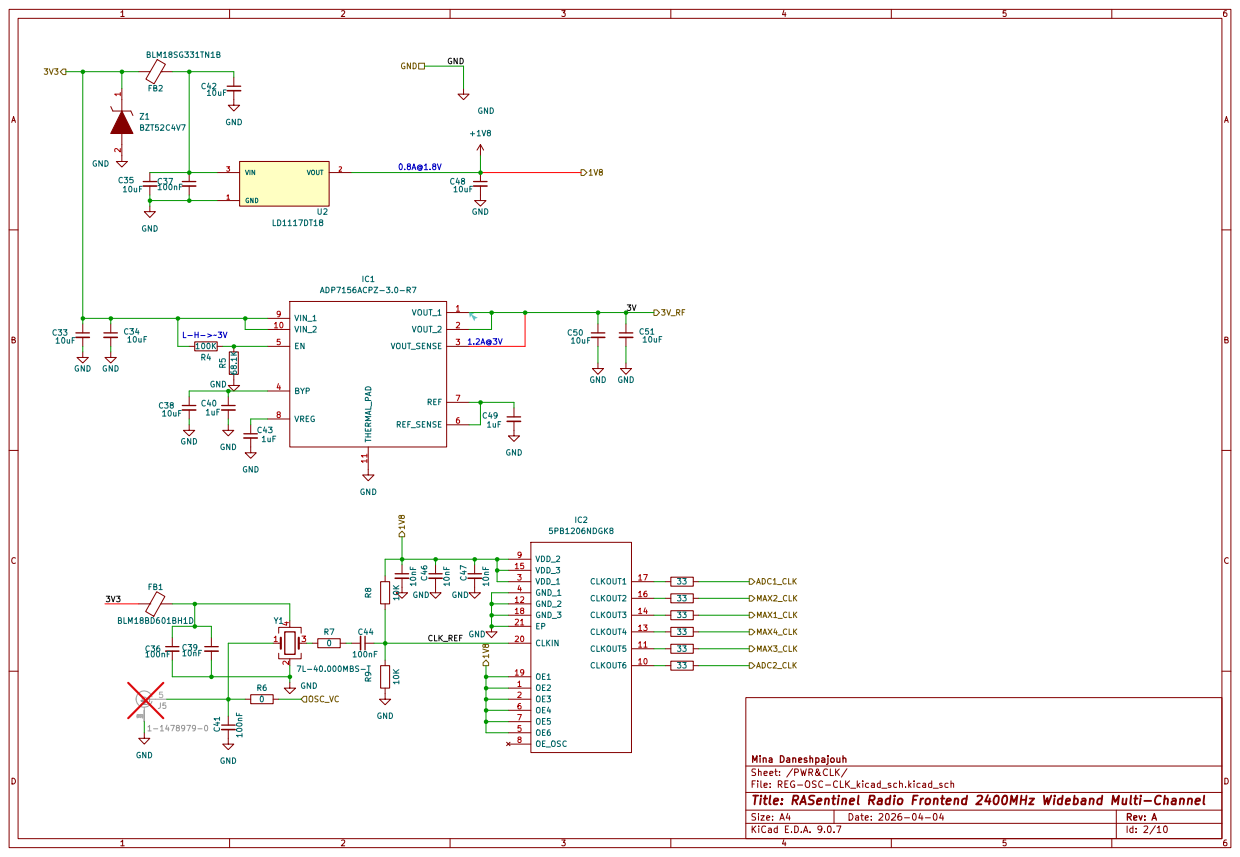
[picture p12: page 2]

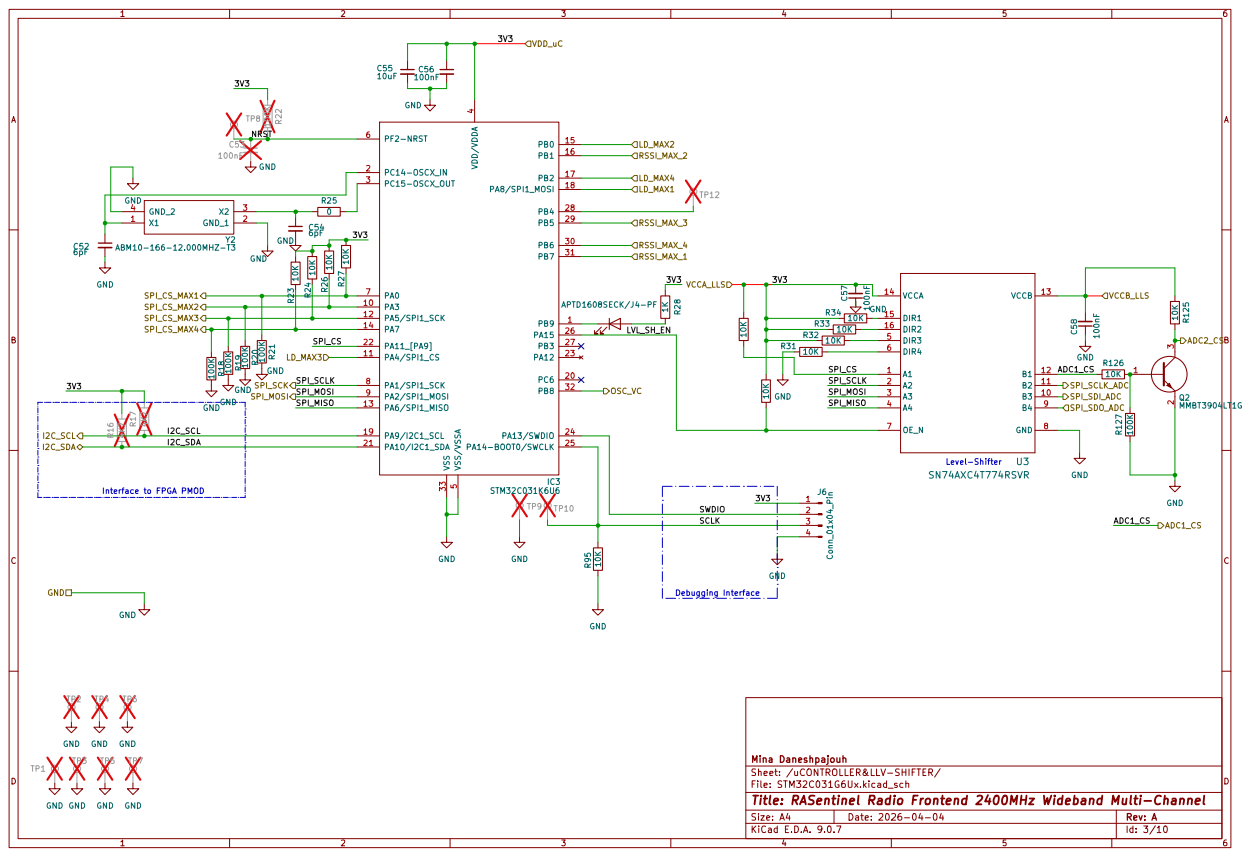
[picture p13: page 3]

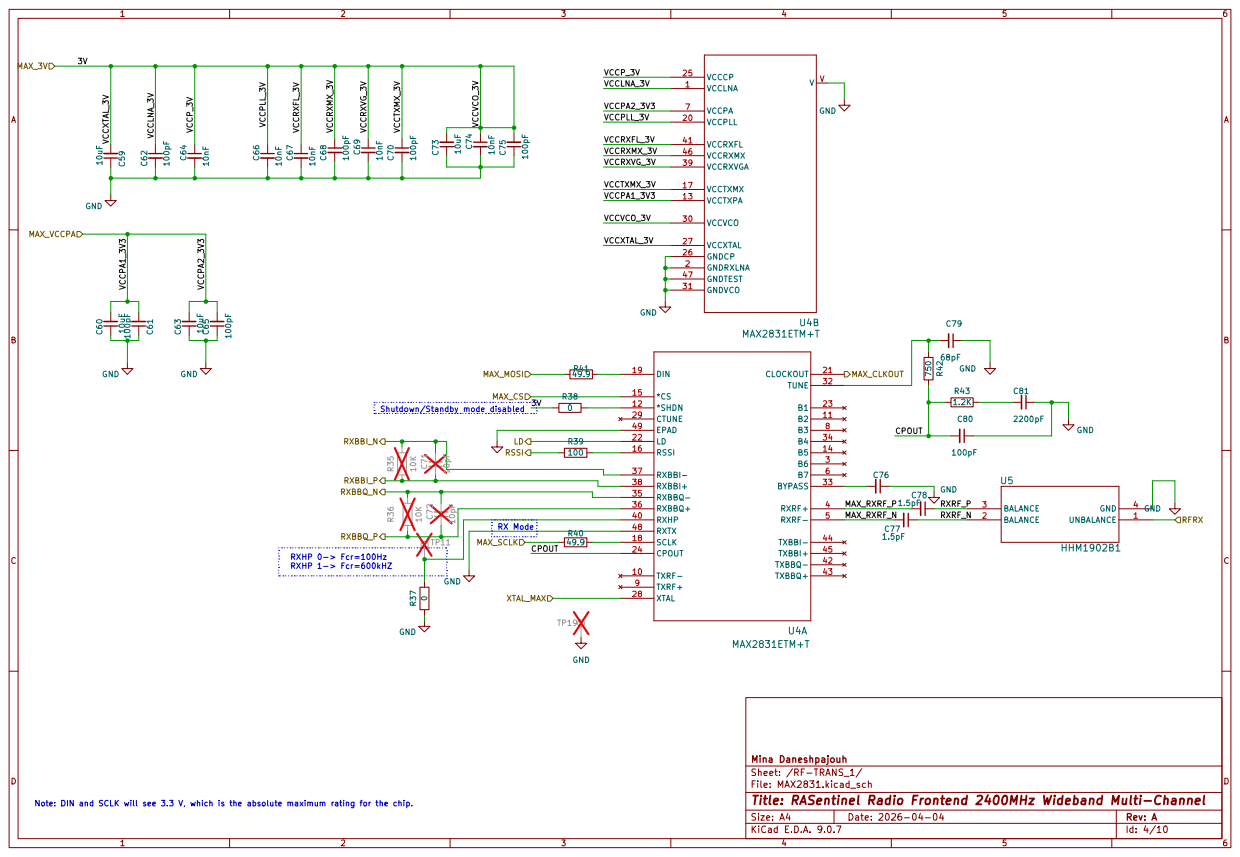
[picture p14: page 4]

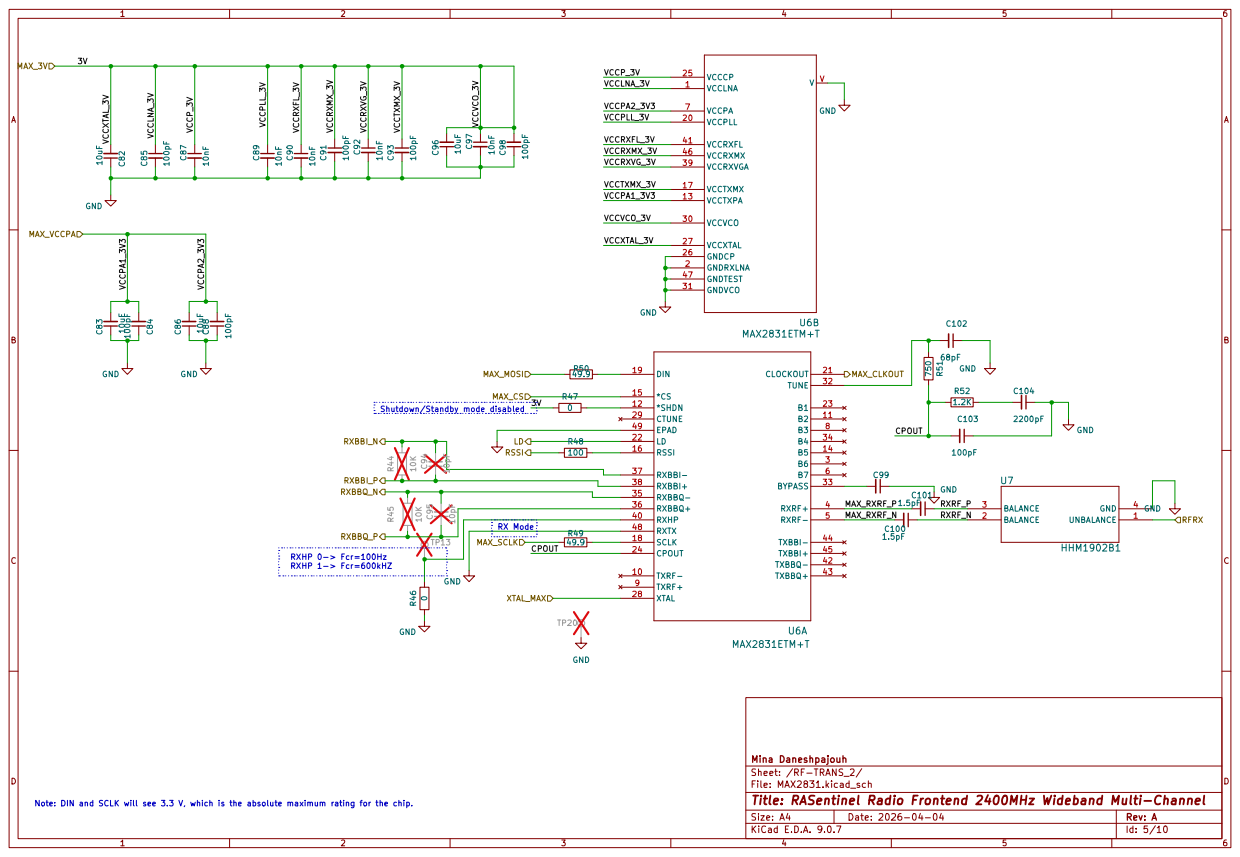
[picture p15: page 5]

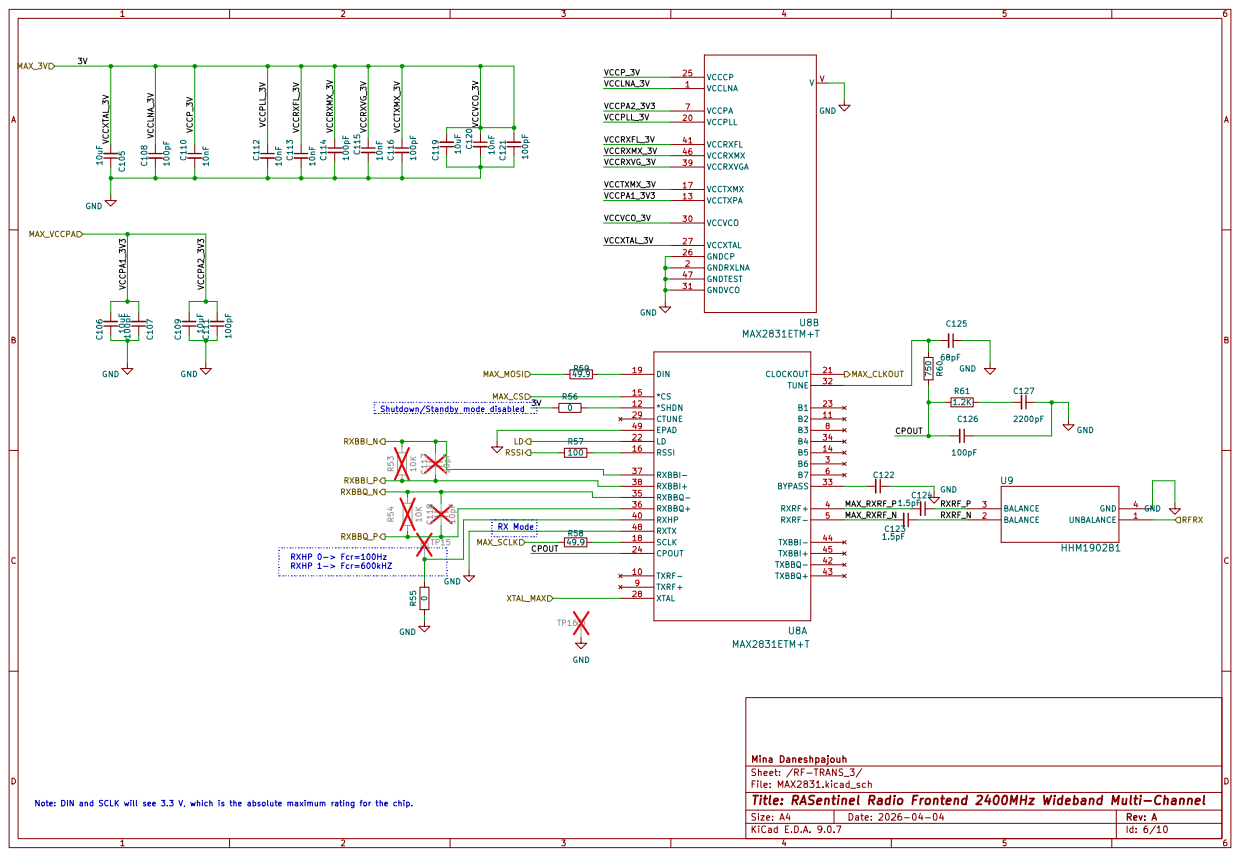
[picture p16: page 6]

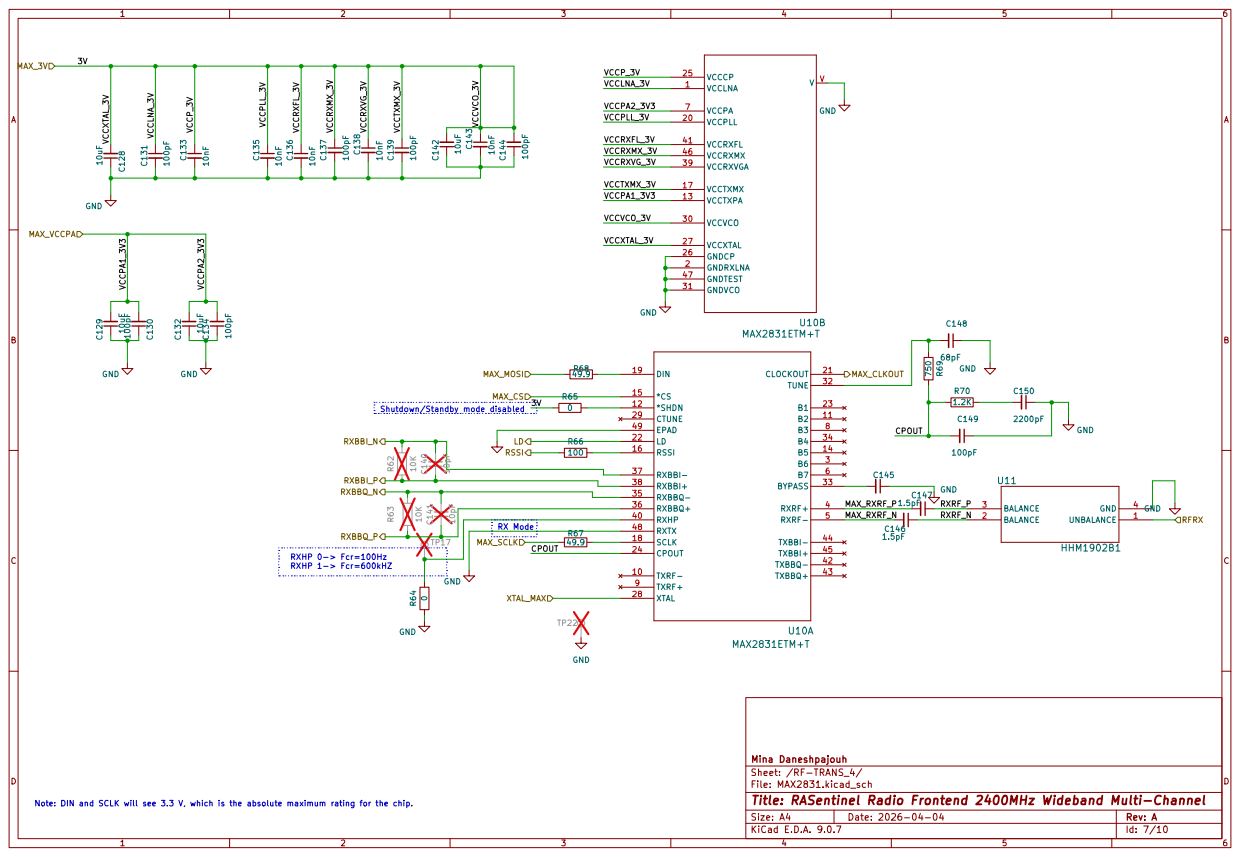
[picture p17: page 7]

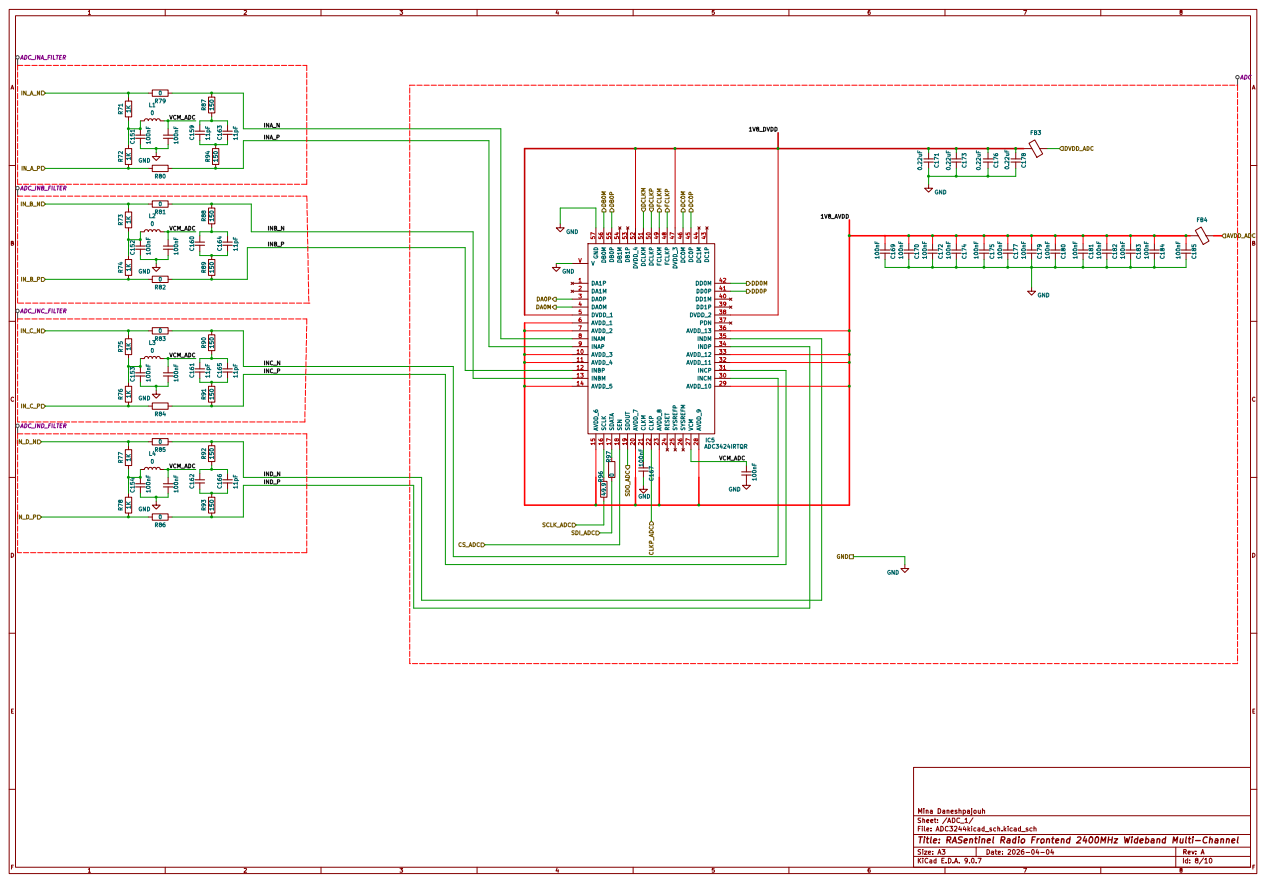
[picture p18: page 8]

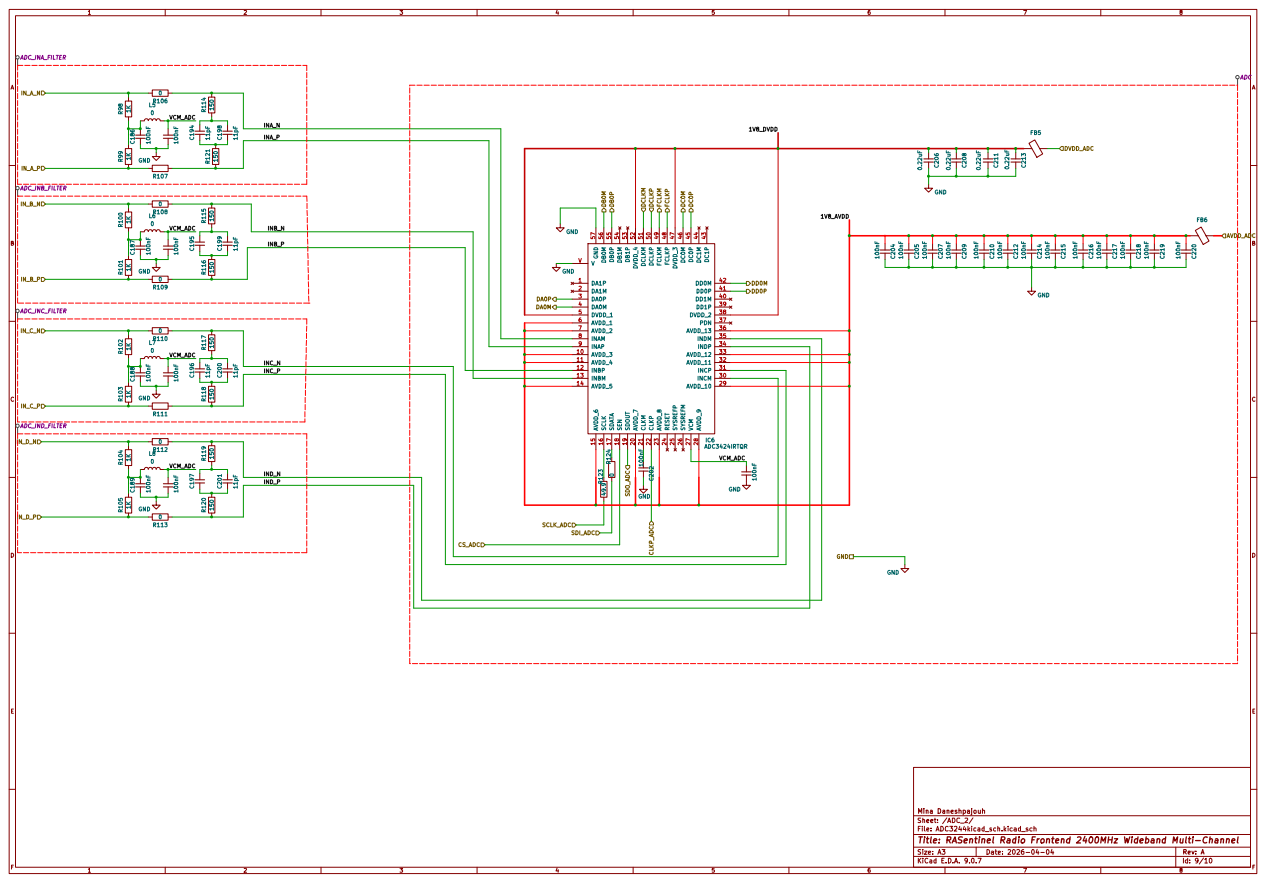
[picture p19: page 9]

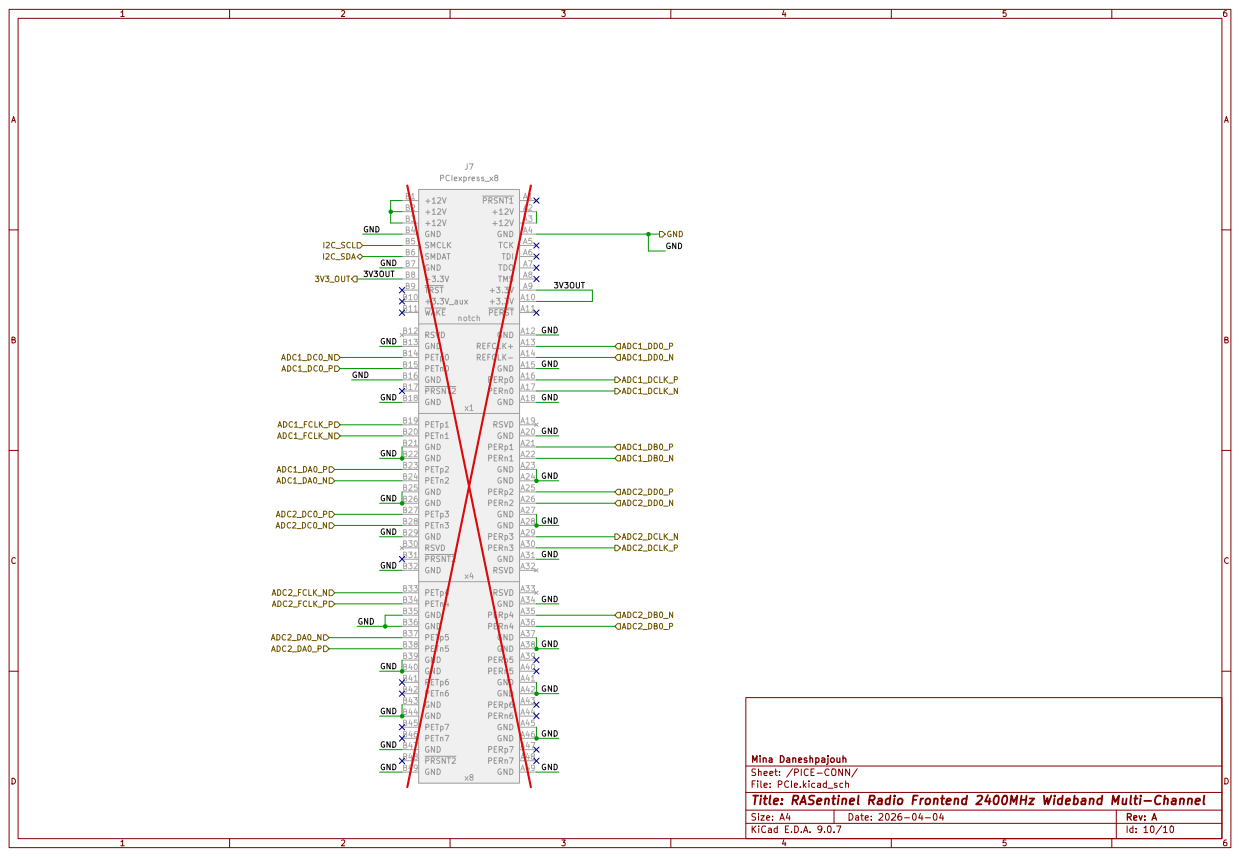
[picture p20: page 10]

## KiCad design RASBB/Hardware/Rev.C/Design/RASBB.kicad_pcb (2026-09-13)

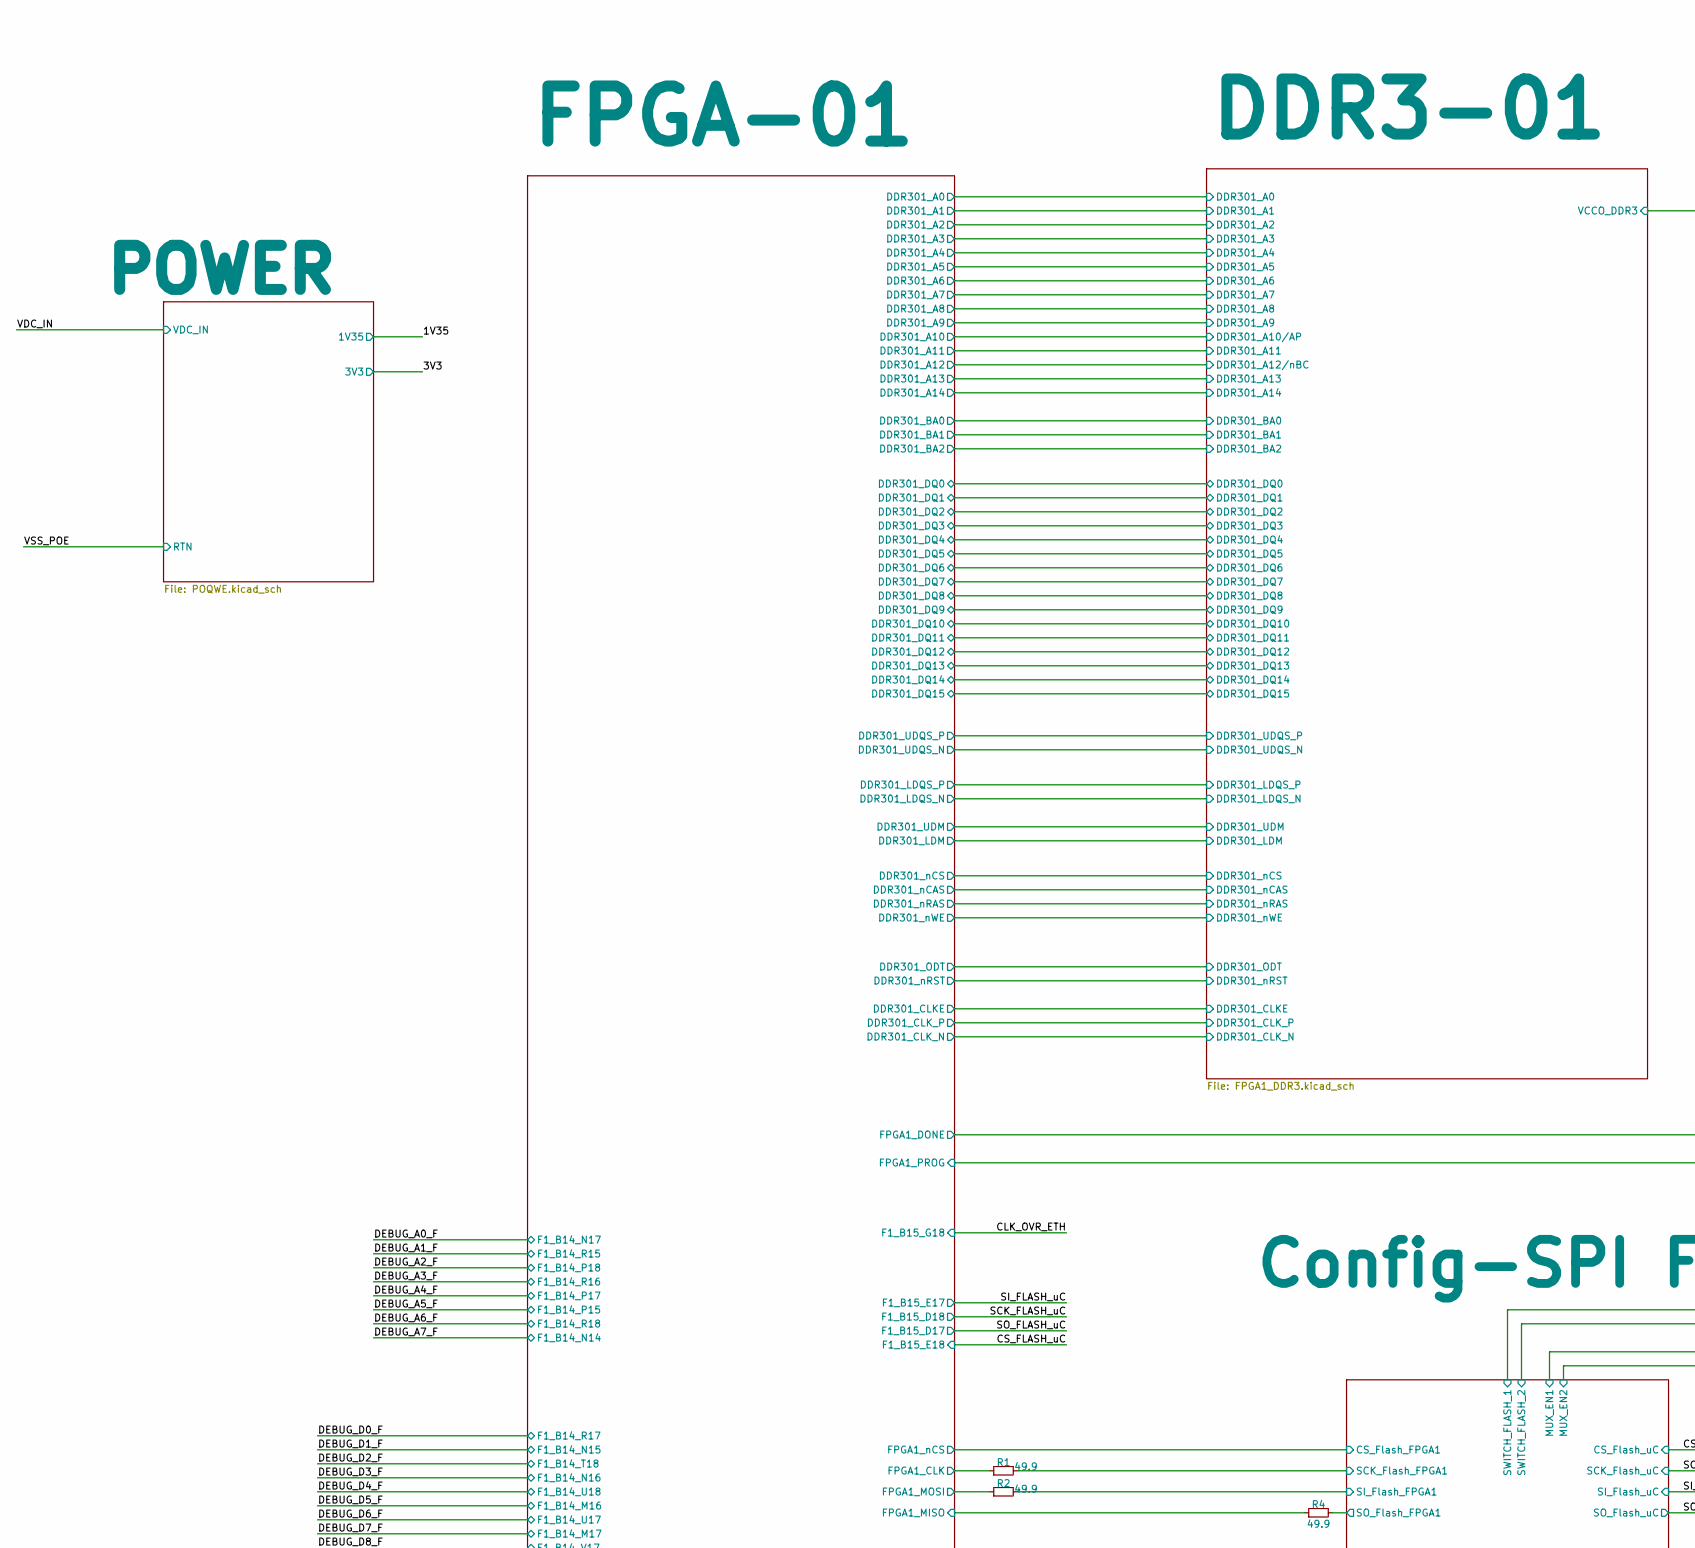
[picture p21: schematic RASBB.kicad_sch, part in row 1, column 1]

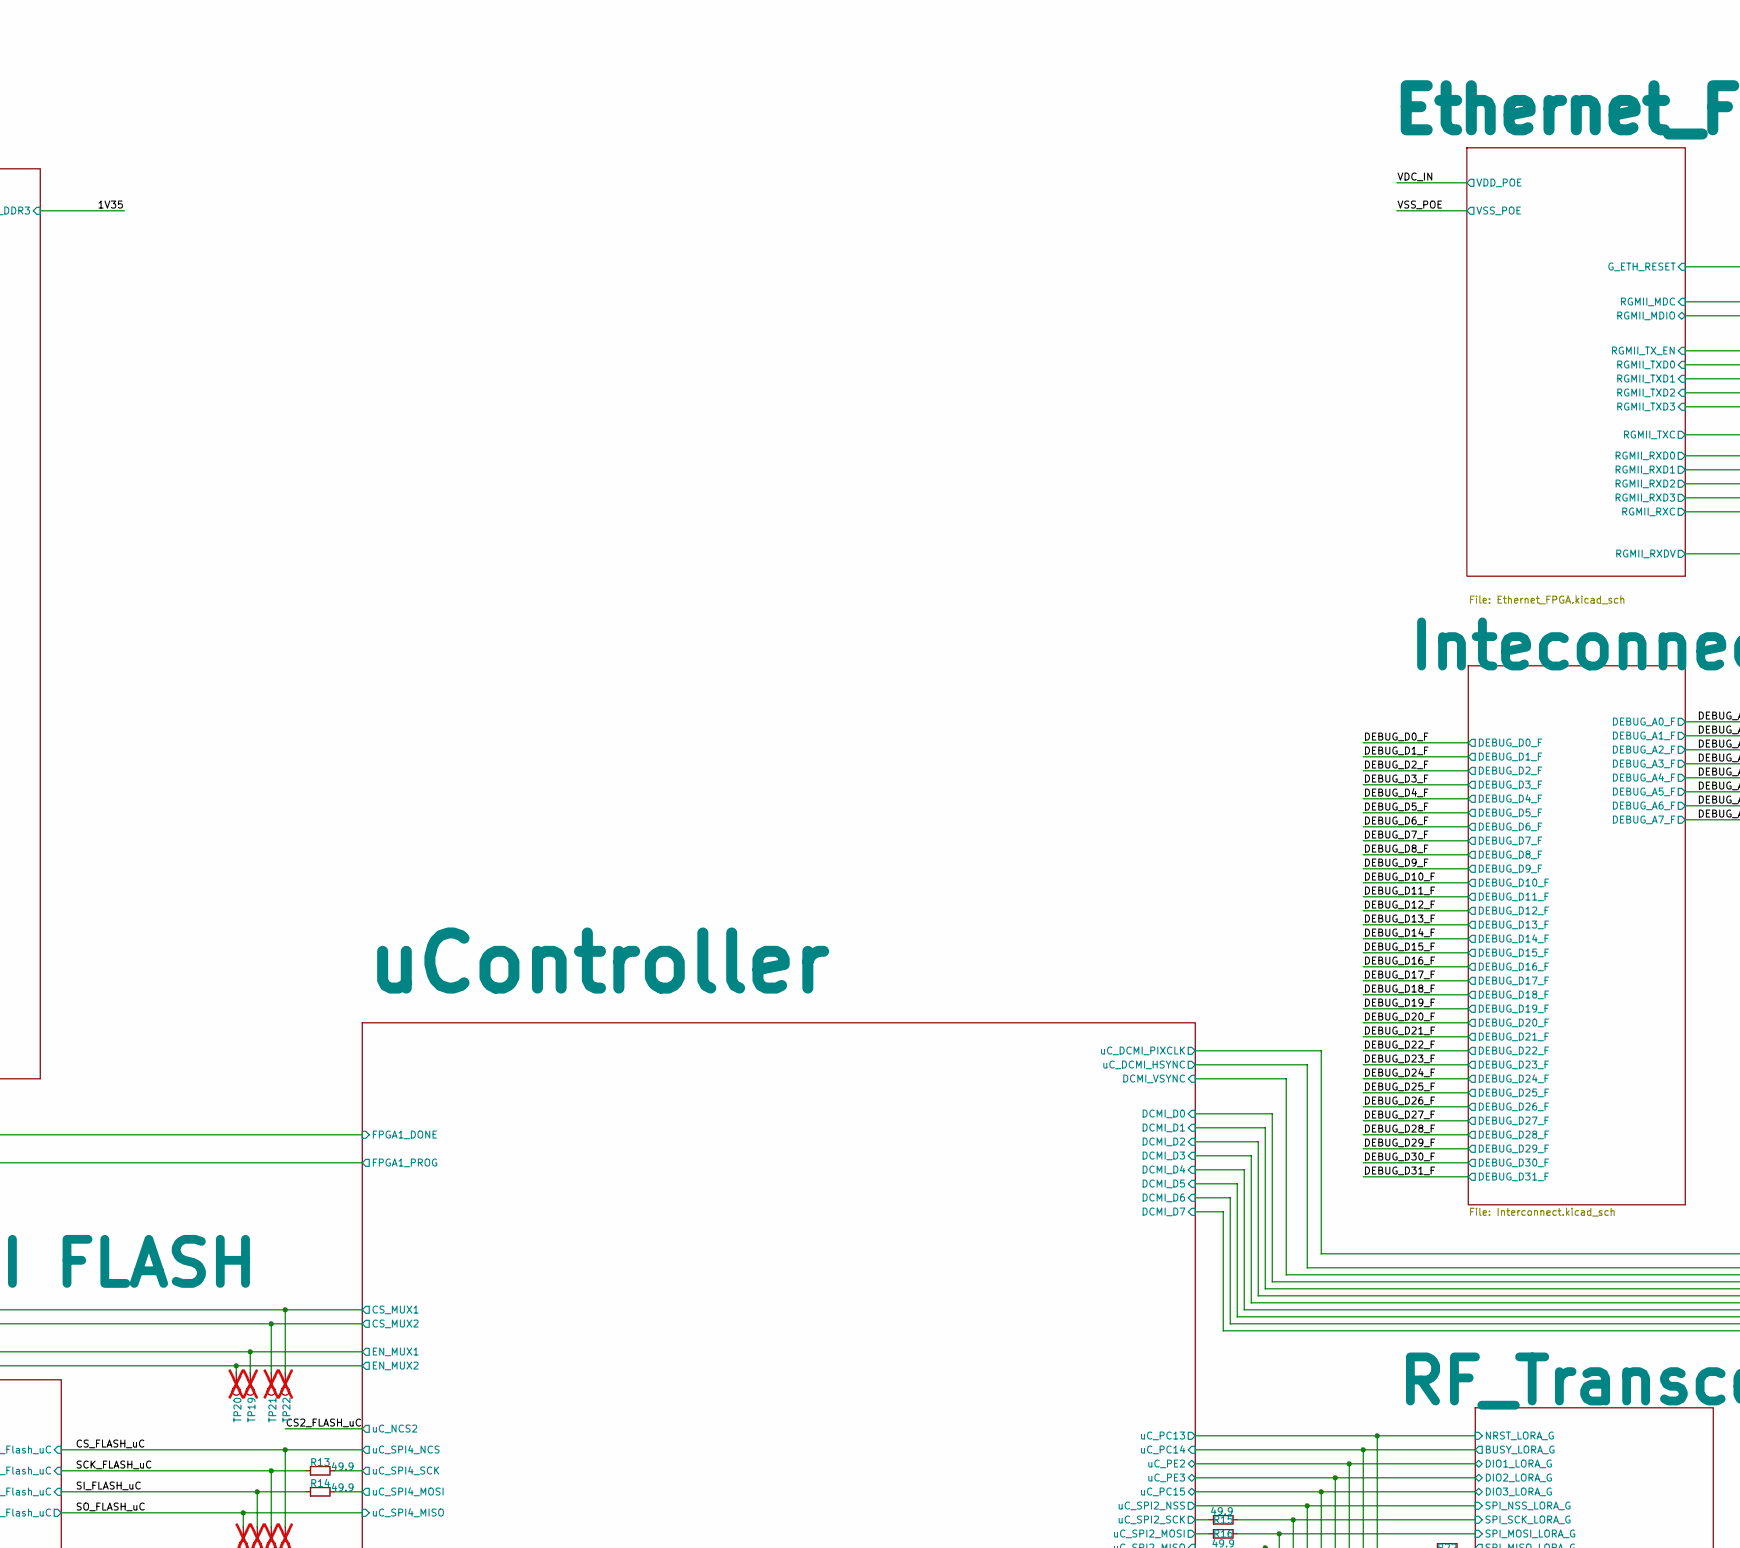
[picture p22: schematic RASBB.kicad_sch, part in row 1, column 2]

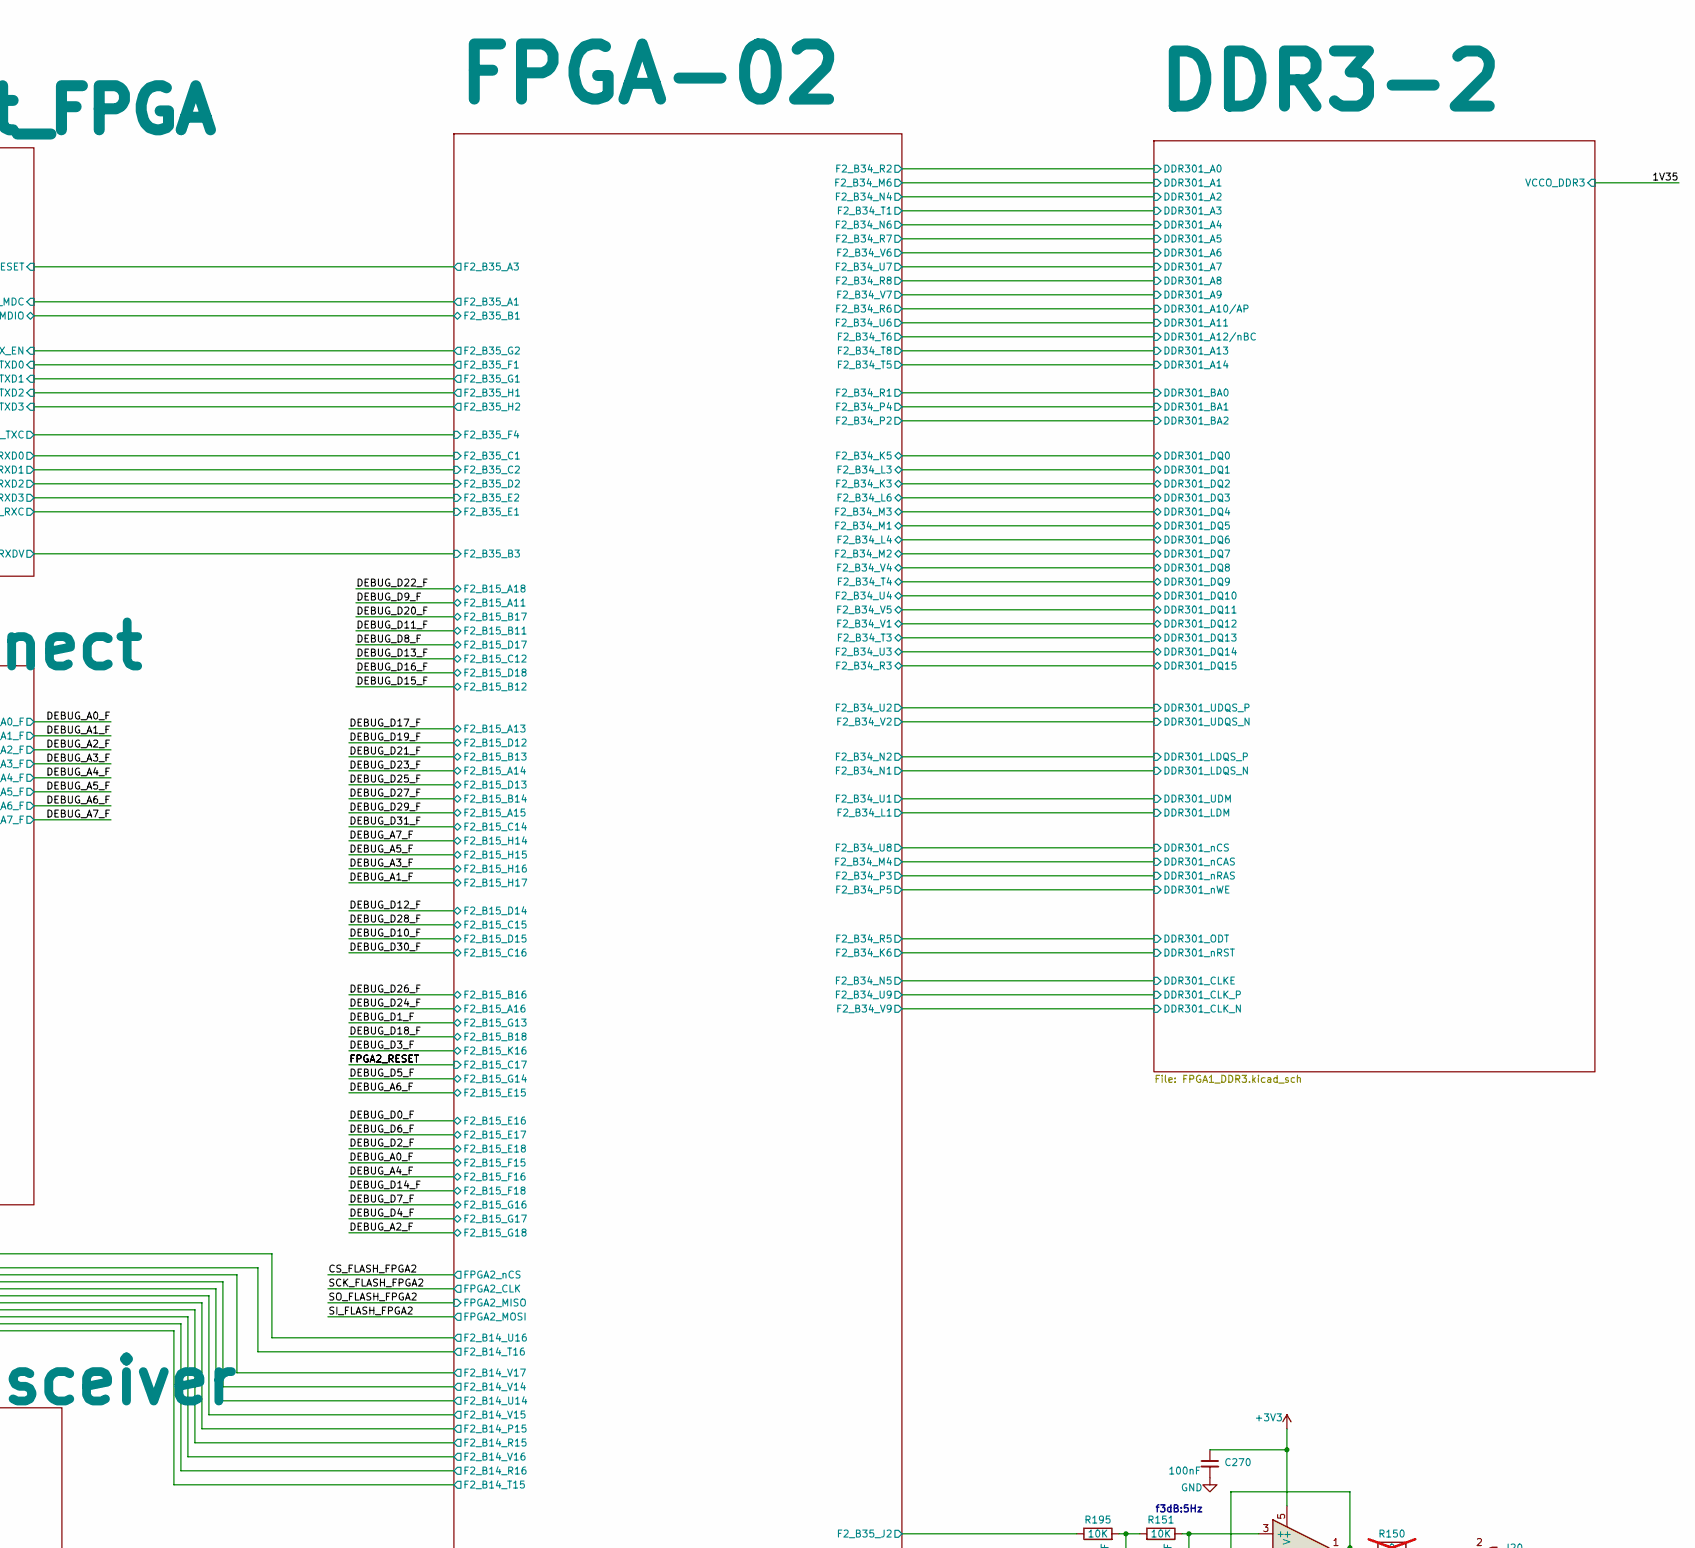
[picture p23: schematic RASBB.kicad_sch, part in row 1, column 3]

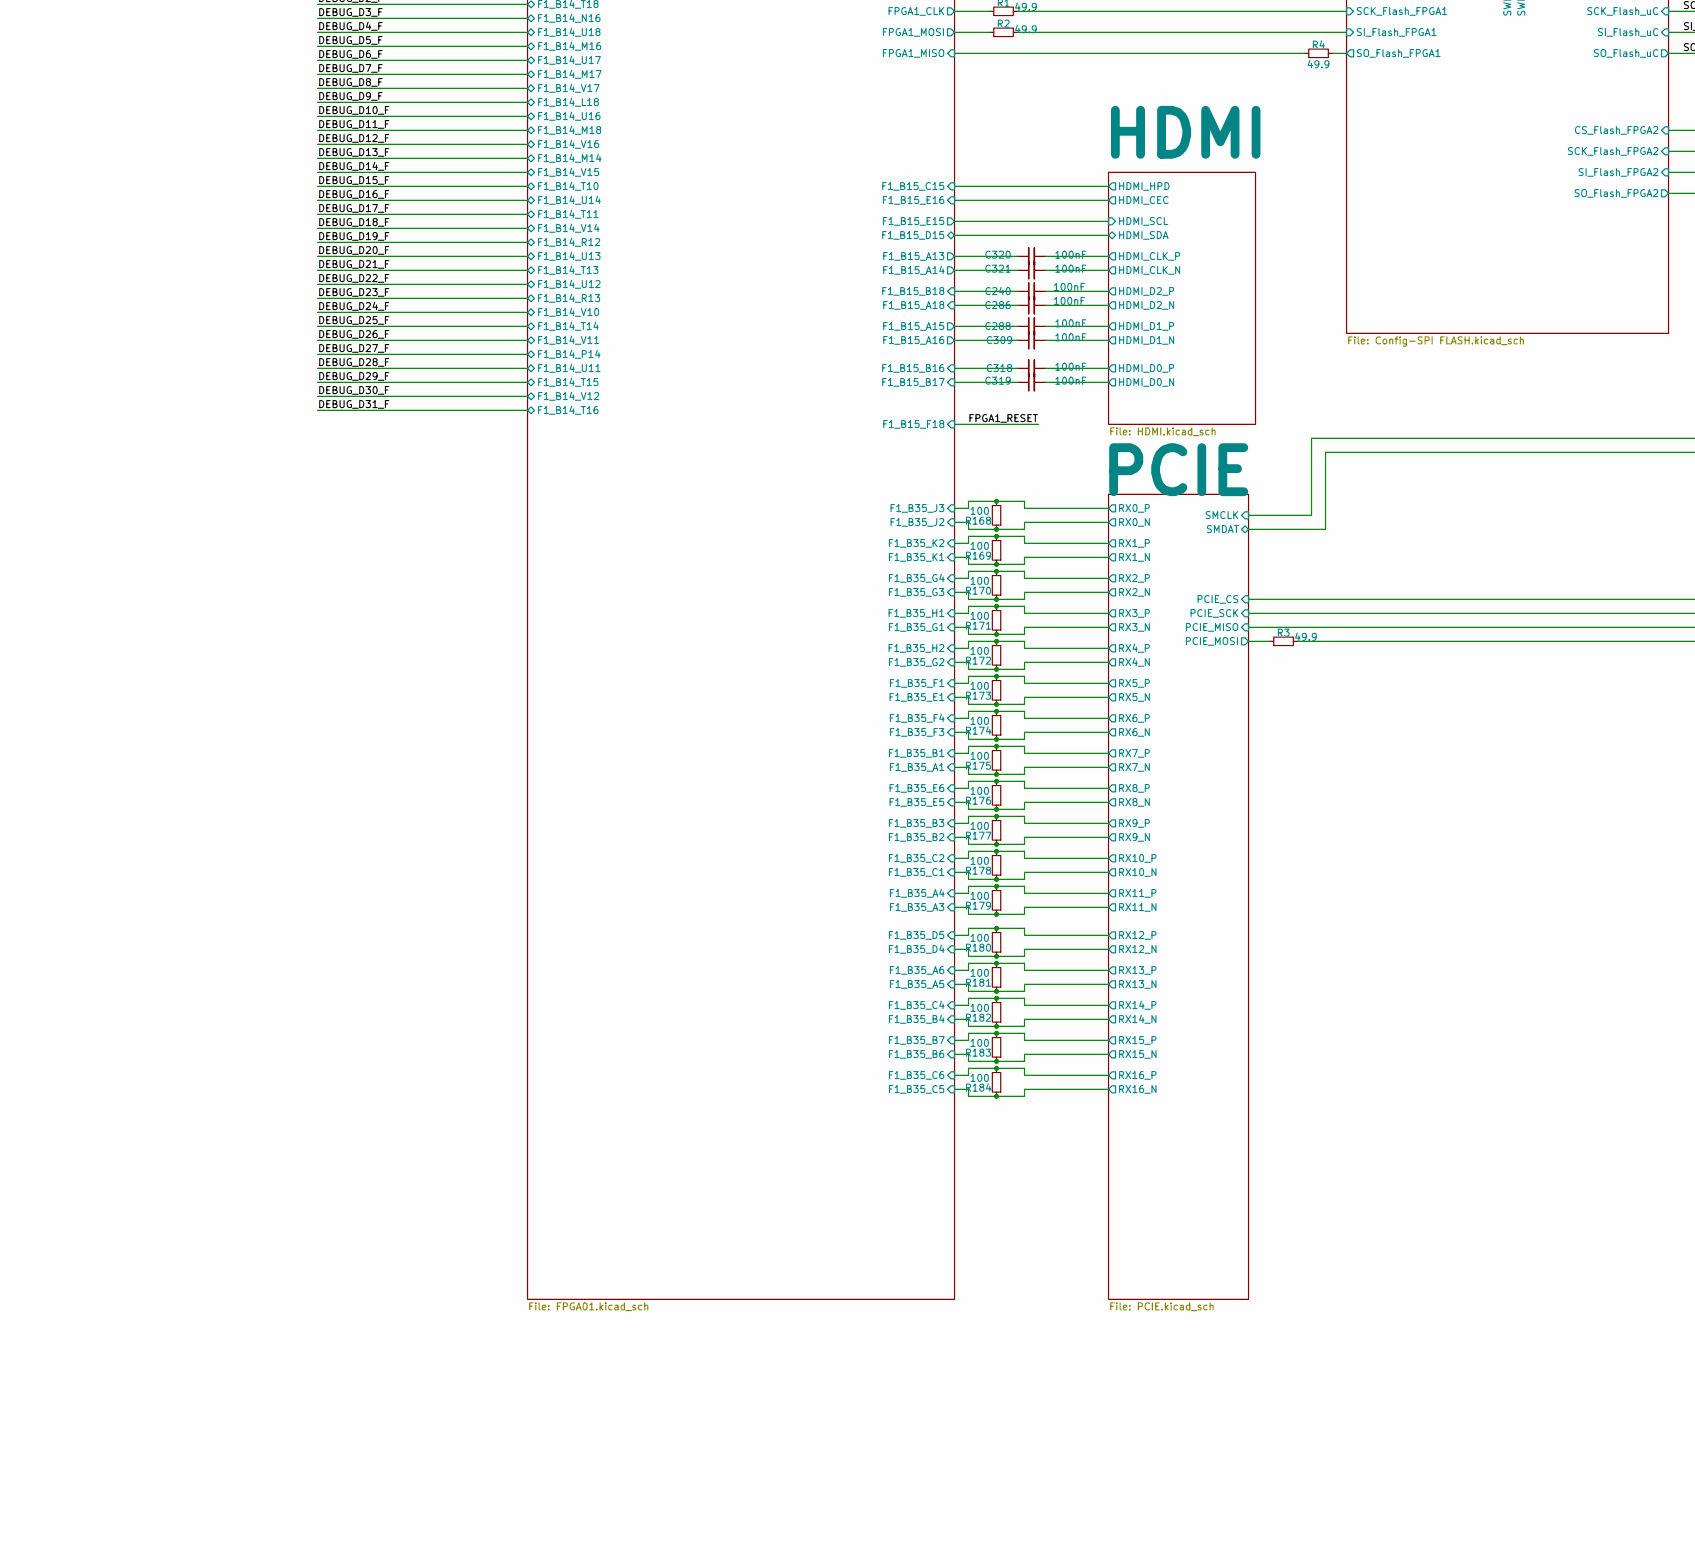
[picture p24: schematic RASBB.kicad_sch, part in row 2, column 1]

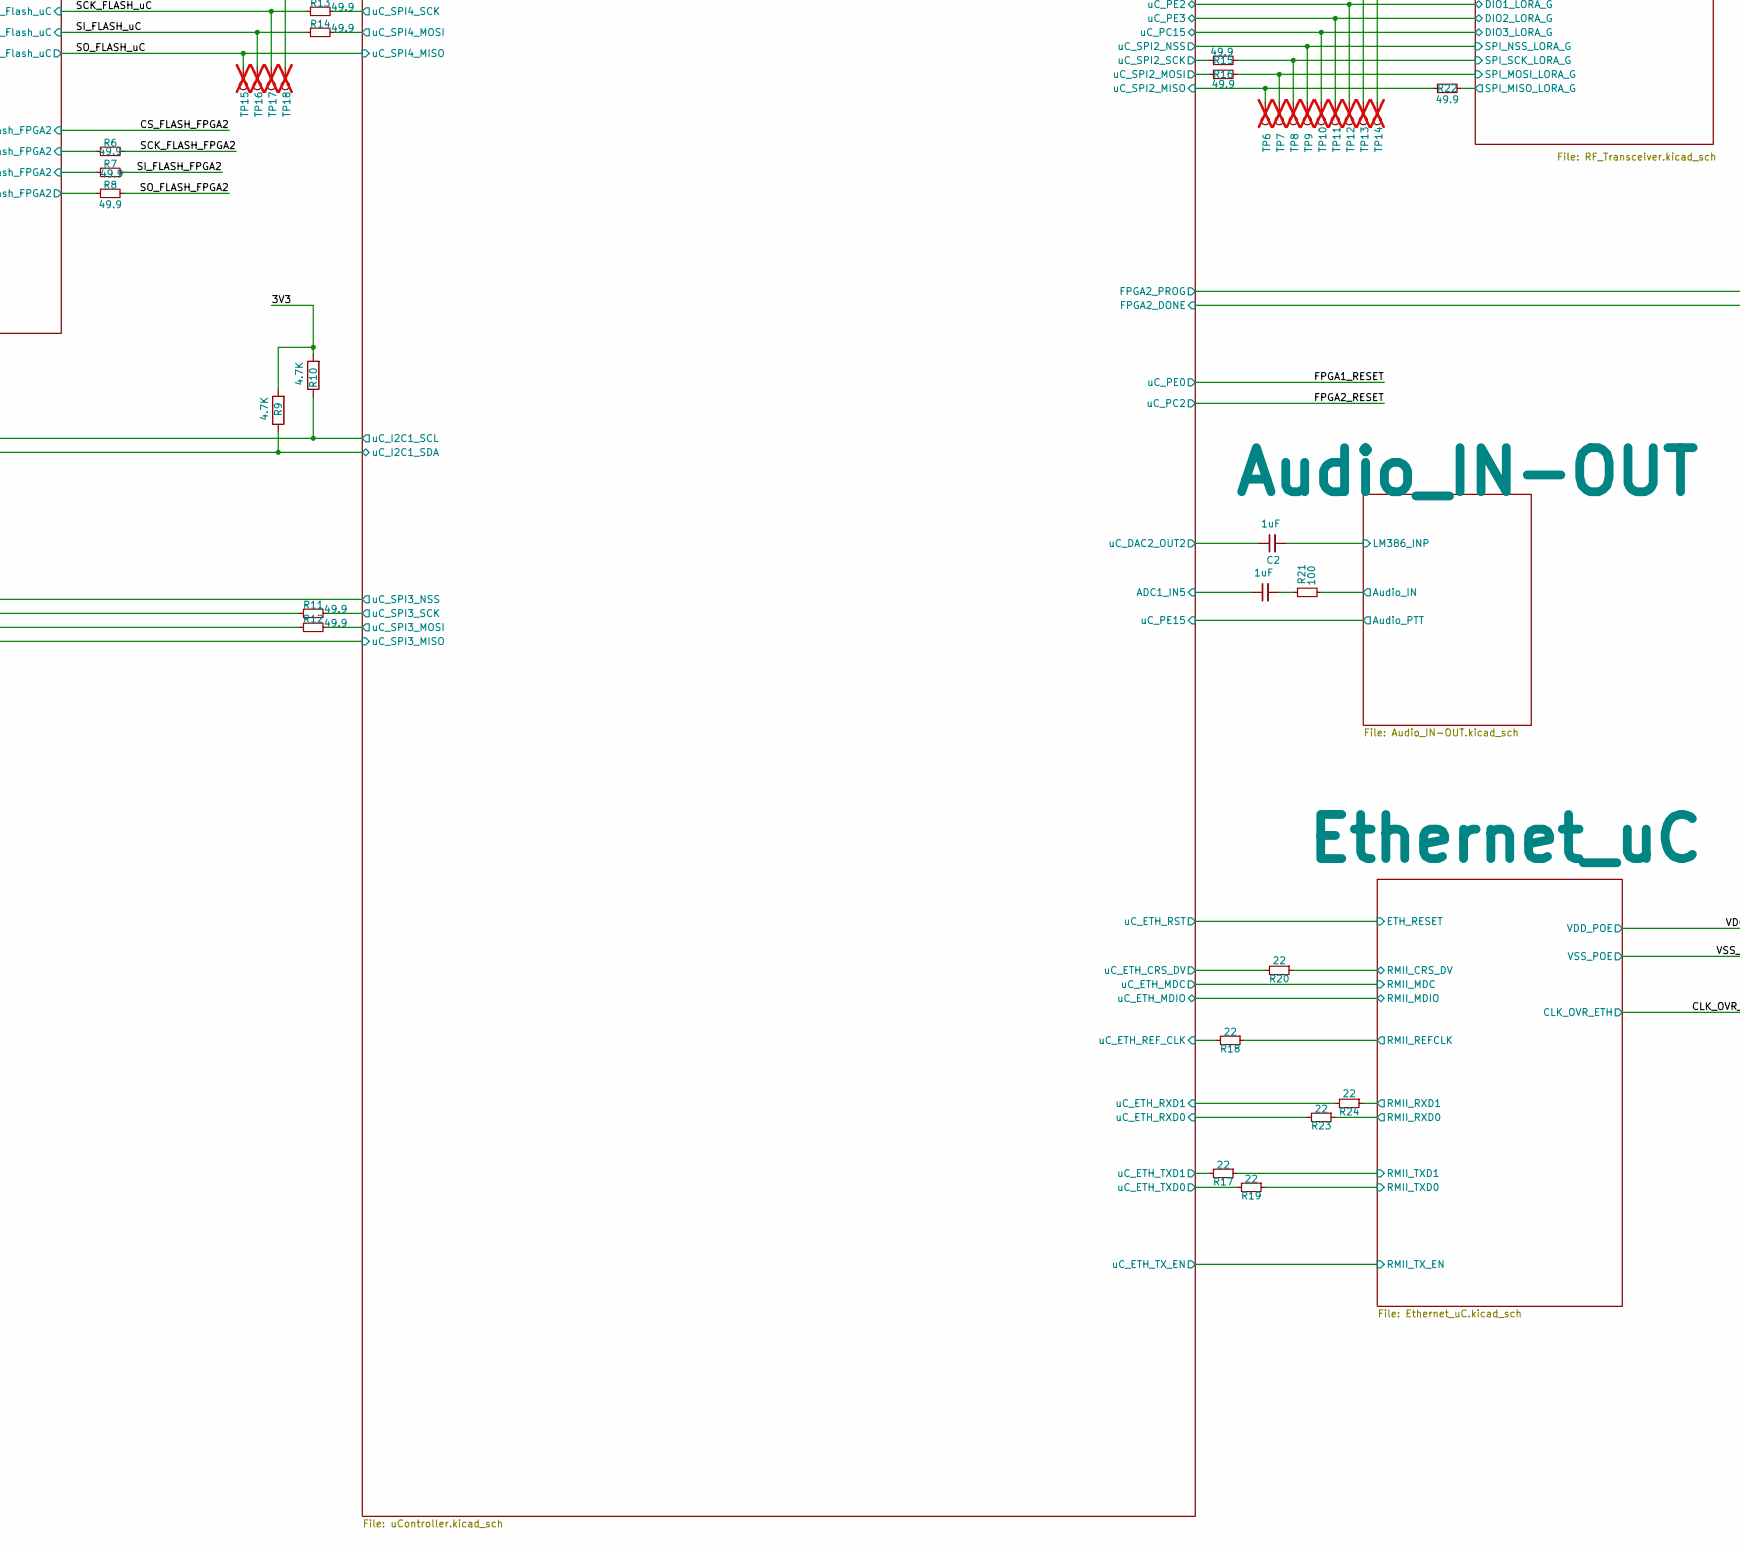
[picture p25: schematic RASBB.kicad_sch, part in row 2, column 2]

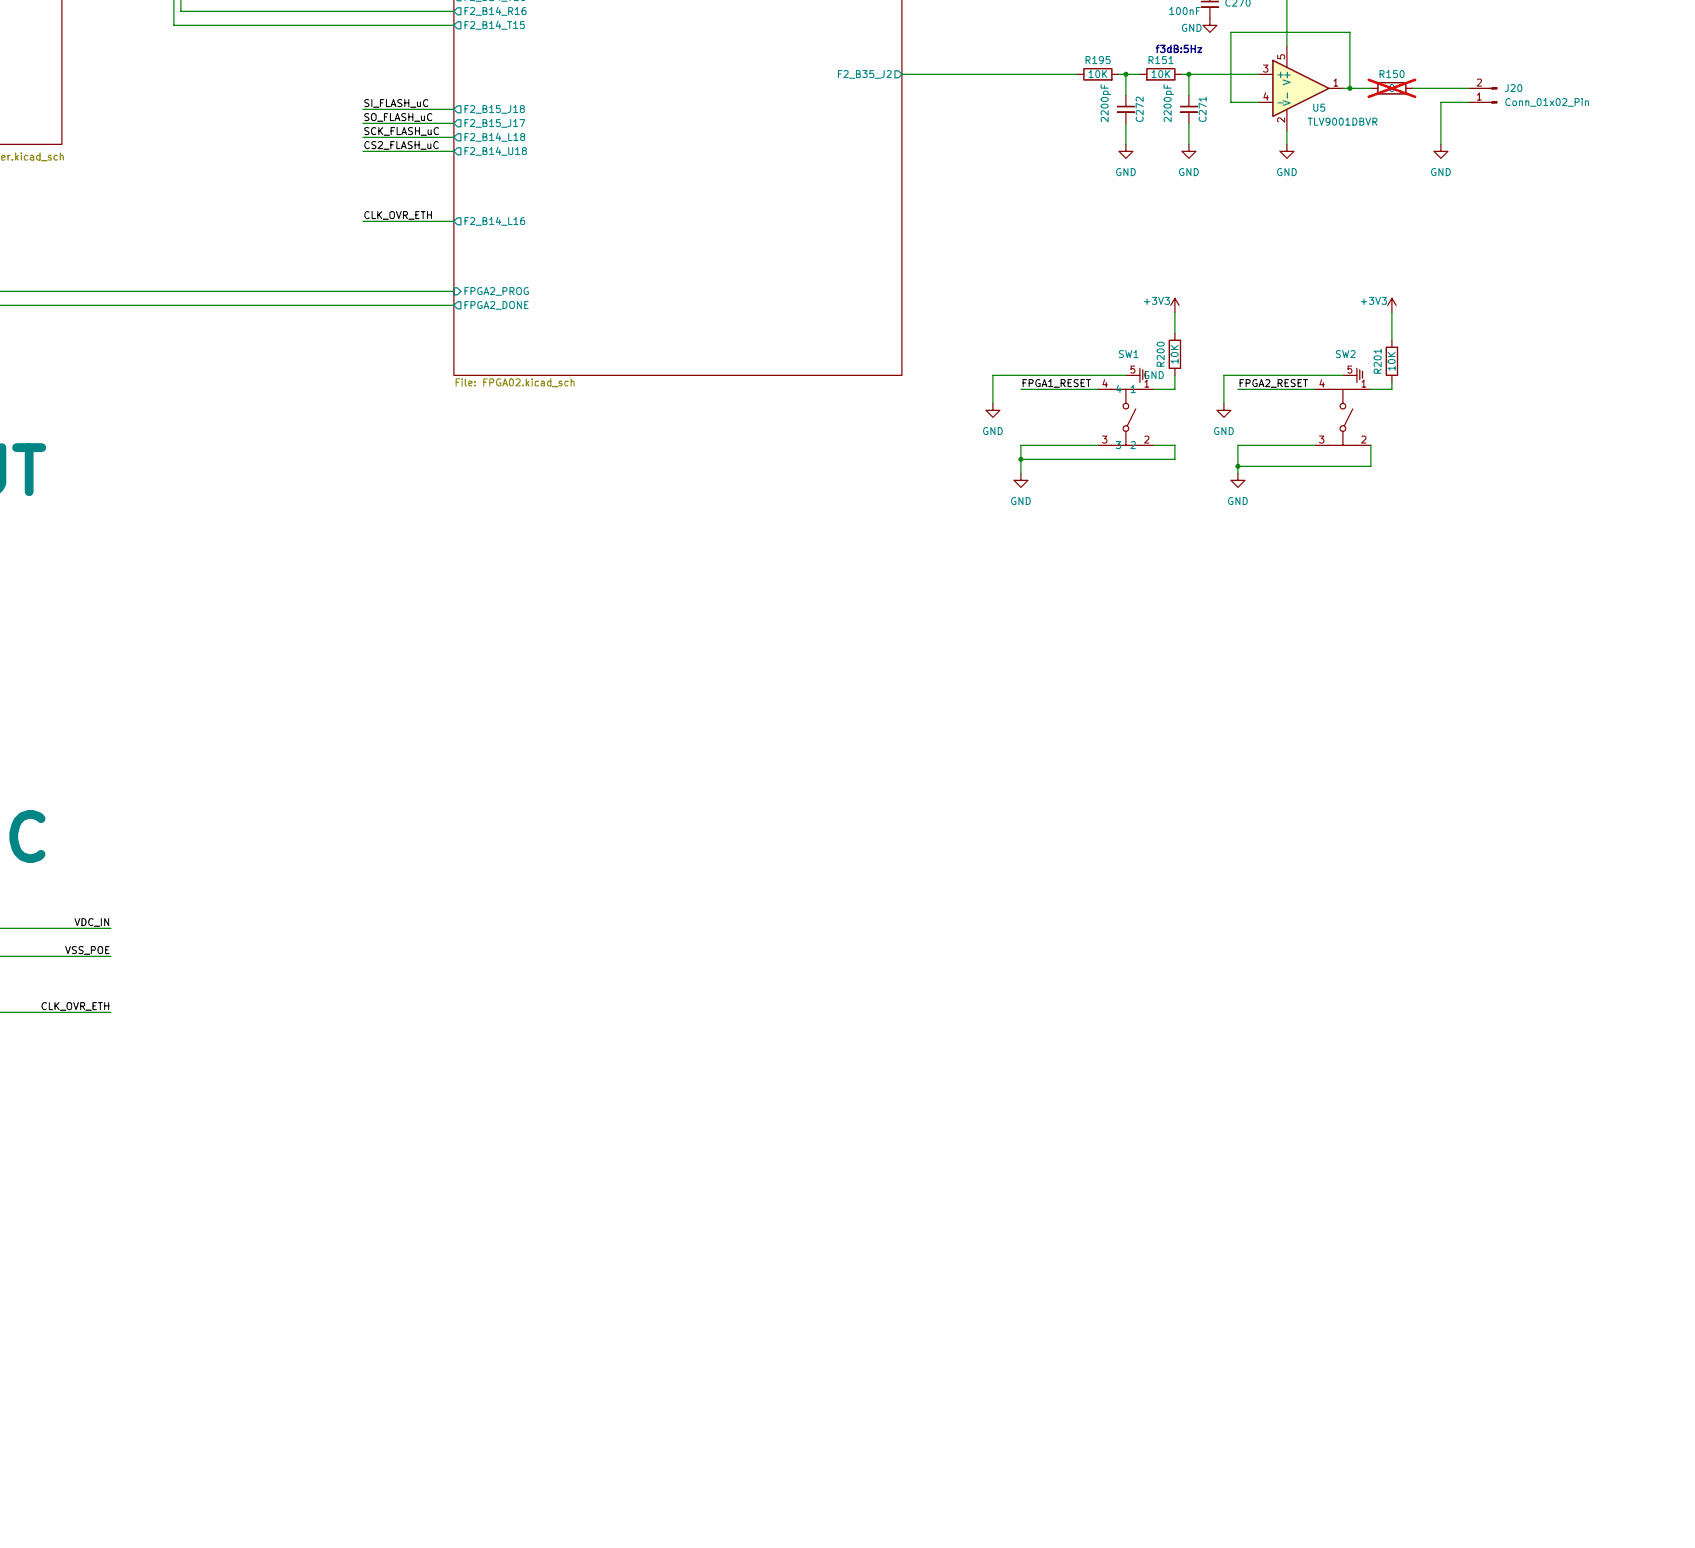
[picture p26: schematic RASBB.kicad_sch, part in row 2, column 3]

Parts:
C1, C2: 1uF; C_0402_1005Metric; Mfr. Part # 0402X105M160CT; LCSC Part # C3889771
C240, C286, C288, C309, C318, C319, C320, C321: 100nF; C_0402_1005Metric; Mfr. Part # 0402B104K500CT; LCSC Part # C152814
C270: 100nF; C_0402_1005Metric; Manufacturer_Part_Number GRM155R71A104KA01D; LCSC Part # C152814
C271: 2200pF; C_0402_1005Metric; Manufacturer_Part_Number GRM1555C1H222JA01D
C272: 2200pF; C_0402_1005Metric; Manufacturer_Part_Number GRM1555C1H222JA01D; LCSC Part # C1531
J20: Conn_01x02_Pin; PinHeader_1x02_P2.54mm_Vertical; Mfr. Part # PZ254V-11-02P; LCSC Part # C492401
R1, R2, R3, R4, R6, R7, R8, R11, R12, R13, R14, R15, R16, R22: 49.9; R_0402_1005Metric; Mfr. Part # RMCF0402FT49R9; LCSC Part # C4229190
R9, R10: 4.7K; R_0402_1005Metric; Mfr. Part # WR04X4701FTL; LCSC Part # C163826
R17, R18, R19, R20, R23, R24: 22; R_0402_1005Metric; Mfr. Part # WR04X22R0FTL; LCSC Part # C163821
R21: 100; R_0402_1005Metric; Mfr. Part # WR04X1000FTL; LCSC Part # C163808
R150: 0; R_0603_1608Metric; Manufacturer_Part_Number RC0603JR-070RL; not fitted
R151: 10K; R_0603_1608Metric; Manufacturer_Part_Number RC0603FR-0710KL
R168, R169, R170, R171, R172, R173, R174, R175, R176, R177, R178, R179, R180, R181, R182, R183, R184: 100; R_0402_1005Metric; Mfr. Part # WR02X1000FTL; LCSC Part # C367410
R195, R200, R201: 10K; R_0603_1608Metric; Manufacturer_Part_Number RC0603FR-0710KL; LCSC Part # C25804
SW1, SW2: 435451019820; Part Number 435451019820
TP6, TP7, TP8, TP9, TP10, TP11, TP12, TP13, TP14, TP15, TP16, TP17, TP18, TP19, TP20, TP21, TP22: TestPoint; TestPoint_Pad_D1.0mm; not fitted
U5: TLV9001DBVR; SOT-23-5; Manufacturer_Part_Number TLV9001DBVR

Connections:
+3V3: C270.1, R9.2, R10.2, R200.2, R201.2, U5.5 (V+); also elsewhere on the board
/Audio_IN-OUT/Audio_IN: R21.2; also elsewhere on the board
/Audio_IN-OUT/LM386_INP: C2.2; also elsewhere on the board
/CS_FLASH_uC: TP18.1 (1_1); also elsewhere on the board
/Config-SPI FLASH/MUX_EN1: TP19.1 (1_1); also elsewhere on the board
/Config-SPI FLASH/MUX_EN2: TP20.1 (1_1); also elsewhere on the board
/Config-SPI FLASH/SCK_Flash_FPGA1: R1.2; also elsewhere on the board
/Config-SPI FLASH/SCK_Flash_FPGA2: R6.1; also elsewhere on the board
/Config-SPI FLASH/SI_Flash_FPGA1: R2.2; also elsewhere on the board
/Config-SPI FLASH/SI_Flash_FPGA2: R7.1; also elsewhere on the board
/Config-SPI FLASH/SO_Flash_FPGA1: R4.2; also elsewhere on the board
/Config-SPI FLASH/SO_Flash_FPGA2: R8.1; also elsewhere on the board
/Config-SPI FLASH/SWITCH_FLASH_1: TP22.1 (1_1); also elsewhere on the board
/Config-SPI FLASH/SWITCH_FLASH_2: TP21.1 (1_1); also elsewhere on the board
/Ethernet_uC/RMII_CRS_DV: R20.1; also elsewhere on the board
/Ethernet_uC/RMII_REFCLK: R18.1; also elsewhere on the board
/Ethernet_uC/RMII_RXD0: R23.1; also elsewhere on the board
/Ethernet_uC/RMII_RXD1: R24.1; also elsewhere on the board
/Ethernet_uC/RMII_TXD0: R19.1; also elsewhere on the board
/Ethernet_uC/RMII_TXD1: R17.1; also elsewhere on the board
/FPGA1_RESET: SW1.4; also elsewhere on the board
/FPGA2_RESET: SW2.4; also elsewhere on the board
/FPGA-01/F1_B15_A13: C320.1; also elsewhere on the board
/FPGA-01/F1_B15_A14: C321.1; also elsewhere on the board
/FPGA-01/F1_B15_A15: C288.1; also elsewhere on the board
/FPGA-01/F1_B15_A16: C309.1; also elsewhere on the board
/FPGA-01/F1_B15_A18: C286.1; also elsewhere on the board
/FPGA-01/F1_B15_B16: C318.1; also elsewhere on the board
/FPGA-01/F1_B15_B17: C319.1; also elsewhere on the board
/FPGA-01/F1_B15_B18: C240.1; also elsewhere on the board
/FPGA-01/FPGA1_CLK: R1.1; also elsewhere on the board
/FPGA-01/FPGA1_MISO: R4.1; also elsewhere on the board
/FPGA-01/FPGA1_MOSI: R2.1; also elsewhere on the board
/FPGA-02/F2_B35_J2: R195.1; also elsewhere on the board
/HDMI/HDMI_CLK_N: C321.2; also elsewhere on the board
/HDMI/HDMI_CLK_P: C320.2; also elsewhere on the board
/HDMI/HDMI_D0_N: C319.2; also elsewhere on the board
/HDMI/HDMI_D0_P: C318.2; also elsewhere on the board
/HDMI/HDMI_D1_N: C309.2; also elsewhere on the board
/HDMI/HDMI_D1_P: C288.2; also elsewhere on the board
/HDMI/HDMI_D2_N: C286.2; also elsewhere on the board
/HDMI/HDMI_D2_P: C240.2; also elsewhere on the board
/PCIE/PCIE_MISO: R12.1; also elsewhere on the board
/PCIE/PCIE_MOSI: R3.1; also elsewhere on the board
/PCIE/PCIE_SCK: R11.1; also elsewhere on the board
/PCIE/RX0_N: R168.1; also elsewhere on the board
/PCIE/RX0_P: R168.2; also elsewhere on the board
/PCIE/RX1_N: R169.1; also elsewhere on the board
/PCIE/RX1_P: R169.2; also elsewhere on the board
/PCIE/RX2_N: R170.1; also elsewhere on the board
/PCIE/RX2_P: R170.2; also elsewhere on the board
/PCIE/RX3_N: R171.1; also elsewhere on the board
/PCIE/RX3_P: R171.2; also elsewhere on the board
/PCIE/RX4_N: R172.1; also elsewhere on the board
/PCIE/RX4_P: R172.2; also elsewhere on the board
/PCIE/RX5_N: R173.1; also elsewhere on the board
/PCIE/RX5_P: R173.2; also elsewhere on the board
/PCIE/RX6_N: R174.1; also elsewhere on the board
/PCIE/RX6_P: R174.2; also elsewhere on the board
/PCIE/RX7_N: R175.1; also elsewhere on the board
/PCIE/RX7_P: R175.2; also elsewhere on the board
/PCIE/RX8_N: R176.1; also elsewhere on the board
/PCIE/RX8_P: R176.2; also elsewhere on the board
/PCIE/RX9_N: R177.1; also elsewhere on the board
/PCIE/RX9_P: R177.2; also elsewhere on the board
/PCIE/RX10_N: R178.1; also elsewhere on the board
/PCIE/RX10_P: R178.2; also elsewhere on the board
/PCIE/RX11_N: R179.1; also elsewhere on the board
/PCIE/RX11_P: R179.2; also elsewhere on the board
/PCIE/RX12_N: R180.1; also elsewhere on the board
/PCIE/RX12_P: R180.2; also elsewhere on the board
/PCIE/RX13_N: R181.1; also elsewhere on the board
/PCIE/RX13_P: R181.2; also elsewhere on the board
/PCIE/RX14_N: R182.1; also elsewhere on the board
/PCIE/RX14_P: R182.2; also elsewhere on the board
/PCIE/RX15_N: R183.1; also elsewhere on the board
/PCIE/RX15_P: R183.2; also elsewhere on the board
/PCIE/RX16_N: R184.1; also elsewhere on the board
/PCIE/RX16_P: R184.2; also elsewhere on the board
/PCIE/SMCLK: R10.1; also elsewhere on the board
/PCIE/SMDAT: R9.1; also elsewhere on the board
/RF_Transceiver/BUSY_LORA_G: TP13.1 (1_1); also elsewhere on the board
/RF_Transceiver/DIO1_LORA_G: TP12.1 (1_1); also elsewhere on the board
/RF_Transceiver/DIO2_LORA_G: TP11.1 (1_1); also elsewhere on the board
/RF_Transceiver/DIO3_LORA_G: TP10.1 (1_1); also elsewhere on the board
/RF_Transceiver/NRST_LORA_G: TP14.1 (1_1); also elsewhere on the board
/RF_Transceiver/SPI_MISO_LORA_G: R22.2; also elsewhere on the board
/RF_Transceiver/SPI_MOSI_LORA_G: R16.2, TP7.1 (1_1); also elsewhere on the board
/RF_Transceiver/SPI_NSS_LORA_G: TP9.1 (1_1); also elsewhere on the board
/RF_Transceiver/SPI_SCK_LORA_G: R15.2, TP8.1 (1_1); also elsewhere on the board
/SCK_FLASH_FPGA2: R6.2; also elsewhere on the board
/SCK_FLASH_uC: R13.1, TP17.1 (1_1); also elsewhere on the board
/SI_FLASH_FPGA2: R7.2; also elsewhere on the board
/SI_FLASH_uC: R14.1, TP16.1 (1_1); also elsewhere on the board
/SO_FLASH_FPGA2: R8.2; also elsewhere on the board
/SO_FLASH_uC: TP15.1 (1_1); also elsewhere on the board
/uController/ADC1_IN5: C1.1; also elsewhere on the board
/uController/uC_DAC2_OUT2: C2.1; also elsewhere on the board
/uController/uC_ETH_CRS_DV: R20.2; also elsewhere on the board
/uController/uC_ETH_REF_CLK: R18.2; also elsewhere on the board
/uController/uC_ETH_RXD0: R23.2; also elsewhere on the board
/uController/uC_ETH_RXD1: R24.2; also elsewhere on the board
/uController/uC_ETH_TXD0: R19.2; also elsewhere on the board
/uController/uC_ETH_TXD1: R17.2; also elsewhere on the board
/uController/uC_SPI2_MISO: R22.1, TP6.1 (1_1); also elsewhere on the board
/uController/uC_SPI2_MOSI: R16.1; also elsewhere on the board
/uController/uC_SPI2_SCK: R15.1; also elsewhere on the board
/uController/uC_SPI3_MISO: R3.2; also elsewhere on the board
/uController/uC_SPI3_MOSI: R12.2; also elsewhere on the board
/uController/uC_SPI3_SCK: R11.2; also elsewhere on the board
/uController/uC_SPI4_MOSI: R14.2; also elsewhere on the board
/uController/uC_SPI4_SCK: R13.2; also elsewhere on the board
GND: C270.2, C271.2, C272.2, J20.1, SW1.2, SW1.3, SW1.5 (GND), SW2.2, SW2.3, SW2.5 (GND), U5.2 (V-); also elsewhere on the board
unnamed: C1.2, R21.1
unnamed: C272.1, R151.2, R195.2
unnamed: J20.2, R150.1
unnamed: R200.1, SW1.1
unnamed: R201.1, SW2.1
unnamed: C271.1, R151.1, U5.3 (+)
unnamed: R150.2, U5.1, U5.4 (-)

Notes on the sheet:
f3dB:5Hz

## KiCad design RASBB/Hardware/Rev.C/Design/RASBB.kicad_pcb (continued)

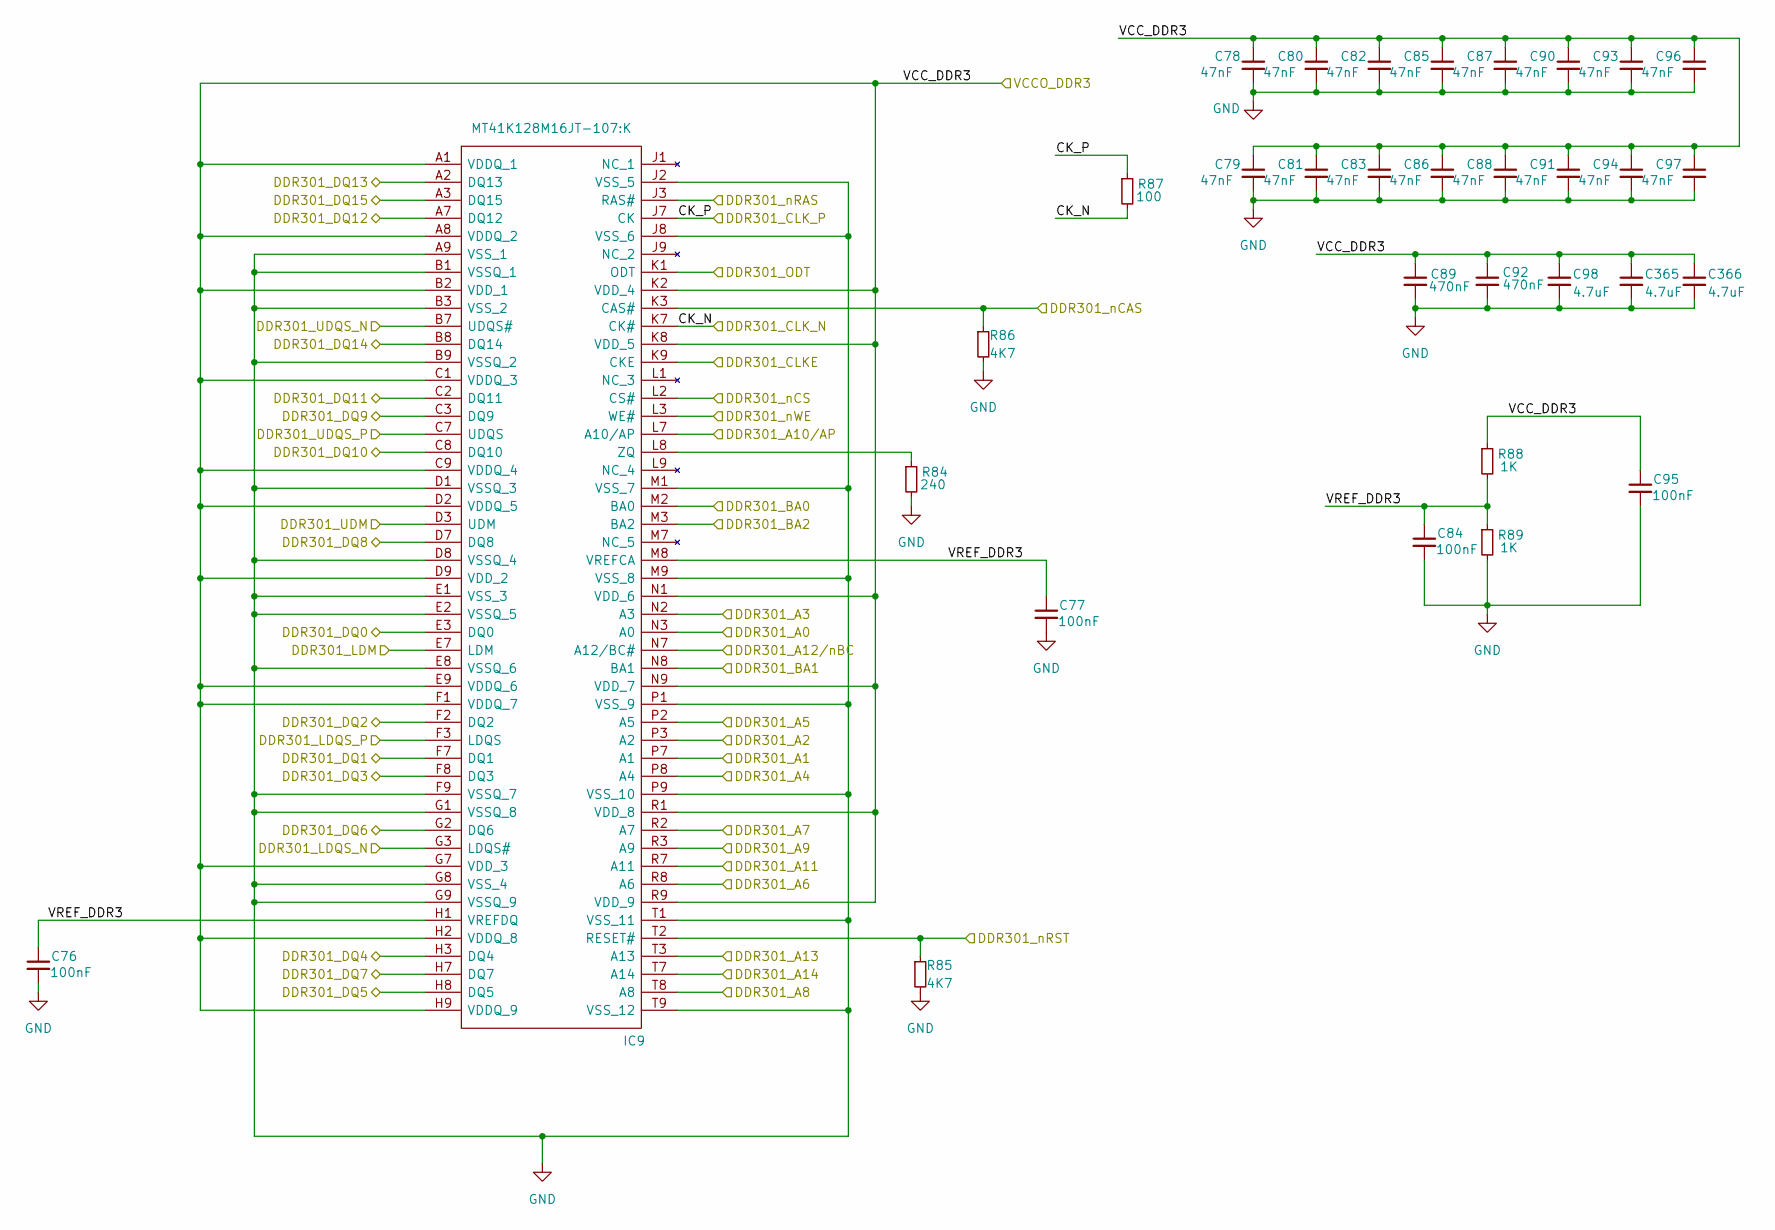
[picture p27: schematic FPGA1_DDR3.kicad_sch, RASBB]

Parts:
C76, C77, C84, C95: 100nF; C_0402_1005Metric; Mfr. Part # 0402B104K500CT; LCSC Part # C152814
C78, C79, C80, C81, C82, C83, C85, C86, C87, C88, C90, C91, C93, C94, C96, C97: 47nF; C_0402_1005Metric; Mfr. Part # C0402C473J8RAC7867; LCSC Part # C2178375
C89, C92: 470nF; C_0402_1005Metric; Mfr. Part # GRT155R71A474KE01D; LCSC Part # C471404
C98, C365, C366: 4.7uF; C_0603_1608Metric; Mfr. Part # GMK107BBJ475KA-T; LCSC Part # C7281848
IC9: MT41K128M16JT-107:K; BGA96C80P9X16_800X1400X120; Mfr. Part # MT41K128M16JT-107:K; LCSC Part # C2841151
R84: 240; R_0402_1005Metric; Mfr. Part # RT0402BRE07240RL; LCSC Part # C728568
R85, R86: 4K7; R_0402_1005Metric; Mfr. Part # RC0402FR-074K7L; LCSC Part # C105871
R87: 100; R_0402_1005Metric; Mfr. Part # WR04X1000FTL; LCSC Part # C163808
R88, R89: 1K; R_0402_1005Metric; Mfr. Part # MR04X1001FTL; LCSC Part # C327796

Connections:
+1V35: C78.1, C79.1, C80.1, C81.1, C82.1, C83.1, C85.1, C86.1, C87.1, C88.1, C89.1, C90.1, C91.1, C92.1, C93.1, C94.1, C95.1, C96.1, C97.1, C98.1, C365.1, C366.1, IC9.A1 (VDDQ_1), IC9.A8 (VDDQ_2), IC9.B2 (VDD_1), IC9.C1 (VDDQ_3), IC9.C9 (VDDQ_4), IC9.D2 (VDDQ_5), IC9.D9 (VDD_2), IC9.E9 (VDDQ_6), IC9.F1 (VDDQ_7), IC9.G7 (VDD_3), IC9.H2 (VDDQ_8), IC9.H9 (VDDQ_9), IC9.K2 (VDD_4), IC9.K8 (VDD_5), IC9.N1 (VDD_6), IC9.N9 (VDD_7), IC9.R1 (VDD_8), IC9.R9 (VDD_9), R88.1; also elsewhere on the board
/DDR3-01/CK_N: IC9.K7 (CK#), R87.2; also elsewhere on the board
/DDR3-01/CK_P: IC9.J7 (CK), R87.1; also elsewhere on the board
/DDR3-01/DDR301_A0: IC9.N3 (A0); also elsewhere on the board
/DDR3-01/DDR301_A1: IC9.P7 (A1); also elsewhere on the board
/DDR3-01/DDR301_A2: IC9.P3 (A2); also elsewhere on the board
/DDR3-01/DDR301_A3: IC9.N2 (A3); also elsewhere on the board
/DDR3-01/DDR301_A4: IC9.P8 (A4); also elsewhere on the board
/DDR3-01/DDR301_A5: IC9.P2 (A5); also elsewhere on the board
/DDR3-01/DDR301_A6: IC9.R8 (A6); also elsewhere on the board
/DDR3-01/DDR301_A7: IC9.R2 (A7); also elsewhere on the board
/DDR3-01/DDR301_A8: IC9.T8 (A8); also elsewhere on the board
/DDR3-01/DDR301_A9: IC9.R3 (A9); also elsewhere on the board
/DDR3-01/DDR301_A10/AP: IC9.L7 (A10/AP); also elsewhere on the board
/DDR3-01/DDR301_A11: IC9.R7 (A11); also elsewhere on the board
/DDR3-01/DDR301_A12/nBC: IC9.N7 (A12/BC#); also elsewhere on the board
/DDR3-01/DDR301_A13: IC9.T3 (A13); also elsewhere on the board
/DDR3-01/DDR301_A14: IC9.T7 (A14); also elsewhere on the board
/DDR3-01/DDR301_BA0: IC9.M2 (BA0); also elsewhere on the board
/DDR3-01/DDR301_BA1: IC9.N8 (BA1); also elsewhere on the board
/DDR3-01/DDR301_BA2: IC9.M3 (BA2); also elsewhere on the board
/DDR3-01/DDR301_CLKE: IC9.K9 (CKE); also elsewhere on the board
/DDR3-01/DDR301_DQ0: IC9.E3 (DQ0); also elsewhere on the board
/DDR3-01/DDR301_DQ1: IC9.F7 (DQ1); also elsewhere on the board
/DDR3-01/DDR301_DQ2: IC9.F2 (DQ2); also elsewhere on the board
/DDR3-01/DDR301_DQ3: IC9.F8 (DQ3); also elsewhere on the board
/DDR3-01/DDR301_DQ4: IC9.H3 (DQ4); also elsewhere on the board
/DDR3-01/DDR301_DQ5: IC9.H8 (DQ5); also elsewhere on the board
/DDR3-01/DDR301_DQ6: IC9.G2 (DQ6); also elsewhere on the board
/DDR3-01/DDR301_DQ7: IC9.H7 (DQ7); also elsewhere on the board
/DDR3-01/DDR301_DQ8: IC9.D7 (DQ8); also elsewhere on the board
/DDR3-01/DDR301_DQ9: IC9.C3 (DQ9); also elsewhere on the board
/DDR3-01/DDR301_DQ10: IC9.C8 (DQ10); also elsewhere on the board
/DDR3-01/DDR301_DQ11: IC9.C2 (DQ11); also elsewhere on the board
/DDR3-01/DDR301_DQ12: IC9.A7 (DQ12); also elsewhere on the board
/DDR3-01/DDR301_DQ13: IC9.A2 (DQ13); also elsewhere on the board
/DDR3-01/DDR301_DQ14: IC9.B8 (DQ14); also elsewhere on the board
/DDR3-01/DDR301_DQ15: IC9.A3 (DQ15); also elsewhere on the board
/DDR3-01/DDR301_LDM: IC9.E7 (LDM); also elsewhere on the board
/DDR3-01/DDR301_LDQS_N: IC9.G3 (LDQS#); also elsewhere on the board
/DDR3-01/DDR301_LDQS_P: IC9.F3 (LDQS); also elsewhere on the board
/DDR3-01/DDR301_ODT: IC9.K1 (ODT); also elsewhere on the board
/DDR3-01/DDR301_UDM: IC9.D3 (UDM); also elsewhere on the board
/DDR3-01/DDR301_UDQS_N: IC9.B7 (UDQS#); also elsewhere on the board
/DDR3-01/DDR301_UDQS_P: IC9.C7 (UDQS); also elsewhere on the board
/DDR3-01/DDR301_nCAS: IC9.K3 (CAS#), R86.1; also elsewhere on the board
/DDR3-01/DDR301_nCS: IC9.L2 (CS#); also elsewhere on the board
/DDR3-01/DDR301_nRAS: IC9.J3 (RAS#); also elsewhere on the board
/DDR3-01/DDR301_nRST: IC9.T2 (RESET#), R85.1; also elsewhere on the board
/DDR3-01/DDR301_nWE: IC9.L3 (WE#); also elsewhere on the board
/DDR3-01/VREF_DDR3: C76.1, C77.1, C84.1, IC9.H1 (VREFDQ), IC9.M8 (VREFCA), R88.2, R89.1
GND: C76.2, C77.2, C78.2, C79.2, C80.2, C81.2, C82.2, C83.2, C84.2, C85.2, C86.2, C87.2, C88.2, C89.2, C90.2, C91.2, C92.2, C93.2, C94.2, C95.2, C96.2, C97.2, C98.2, C365.2, C366.2, IC9.A9 (VSS_1), IC9.B1 (VSSQ_1), IC9.B3 (VSS_2), IC9.B9 (VSSQ_2), IC9.D1 (VSSQ_3), IC9.D8 (VSSQ_4), IC9.E1 (VSS_3), IC9.E2 (VSSQ_5), IC9.E8 (VSSQ_6), IC9.F9 (VSSQ_7), IC9.G1 (VSSQ_8), IC9.G8 (VSS_4), IC9.G9 (VSSQ_9), IC9.J2 (VSS_5), IC9.J8 (VSS_6), IC9.M1 (VSS_7), IC9.M9 (VSS_8), IC9.P1 (VSS_9), IC9.P9 (VSS_10), IC9.T1 (VSS_11), IC9.T9 (VSS_12), R84.2, R85.2, R86.2, R89.2; also elsewhere on the board
unnamed: IC9.L8 (ZQ), R84.1

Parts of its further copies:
C99, C100, C107, C118: 100nF; C_0402_1005Metric; Mfr. Part # 0402B104K500CT; LCSC Part # C152814
C101, C102, C103, C104, C105, C106, C108, C109, C110, C111, C113, C114, C116, C117, C119, C120: 47nF; C_0402_1005Metric; Mfr. Part # C0402C473J8RAC7867; LCSC Part # C2178375
C112, C238: 470nF; C_0402_1005Metric; Mfr. Part # GRT155R71A474KE01D; LCSC Part # C471404
C115, C121, C186: 4.7uF; C_0603_1608Metric; Mfr. Part # GMK107BBJ475KA-T; LCSC Part # C7281848
IC10: MT41K128M16JT-107:K; BGA96C80P9X16_800X1400X120; Mfr. Part # MT41K128M16JT-107:K; LCSC Part # C2841151
R90: 240; R_0402_1005Metric; Mfr. Part # RT0402BRE07240RL; LCSC Part # C728568
R91, R92: 4K7; R_0402_1005Metric; Mfr. Part # RC0402FR-074K7L; LCSC Part # C105871
R93: 100; R_0402_1005Metric; Mfr. Part # WR04X1000FTL; LCSC Part # C163808
R94, R95: 1K; R_0402_1005Metric; Mfr. Part # MR04X1001FTL; LCSC Part # C327796

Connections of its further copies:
+1V35: C101.1, C102.1, C103.1, C104.1, C105.1, C106.1, C108.1, C109.1, C110.1, C111.1, C112.1, C113.1, C114.1, C115.1, C116.1, C117.1, C118.1, C119.1, C120.1, C121.1, C186.1, C238.1, IC10.A1 (VDDQ_1), IC10.A8 (VDDQ_2), IC10.B2 (VDD_1), IC10.C1 (VDDQ_3), IC10.C9 (VDDQ_4), IC10.D2 (VDDQ_5), IC10.D9 (VDD_2), IC10.E9 (VDDQ_6), IC10.F1 (VDDQ_7), IC10.G7 (VDD_3), IC10.H2 (VDDQ_8), IC10.H9 (VDDQ_9), IC10.K2 (VDD_4), IC10.K8 (VDD_5), IC10.N1 (VDD_6), IC10.N9 (VDD_7), IC10.R1 (VDD_8), IC10.R9 (VDD_9), R94.1; also elsewhere on the board
/DDR3-2/CK_N: IC10.K7 (CK#), R93.2; also elsewhere on the board
/DDR3-2/CK_P: IC10.J7 (CK), R93.1; also elsewhere on the board
/DDR3-2/DDR301_A0: IC10.N3 (A0); also elsewhere on the board
/DDR3-2/DDR301_A1: IC10.P7 (A1); also elsewhere on the board
/DDR3-2/DDR301_A2: IC10.P3 (A2); also elsewhere on the board
/DDR3-2/DDR301_A3: IC10.N2 (A3); also elsewhere on the board
/DDR3-2/DDR301_A4: IC10.P8 (A4); also elsewhere on the board
/DDR3-2/DDR301_A5: IC10.P2 (A5); also elsewhere on the board
/DDR3-2/DDR301_A6: IC10.R8 (A6); also elsewhere on the board
/DDR3-2/DDR301_A7: IC10.R2 (A7); also elsewhere on the board
/DDR3-2/DDR301_A8: IC10.T8 (A8); also elsewhere on the board
/DDR3-2/DDR301_A9: IC10.R3 (A9); also elsewhere on the board
/DDR3-2/DDR301_A10/AP: IC10.L7 (A10/AP); also elsewhere on the board
/DDR3-2/DDR301_A11: IC10.R7 (A11); also elsewhere on the board
/DDR3-2/DDR301_A12/nBC: IC10.N7 (A12/BC#); also elsewhere on the board
/DDR3-2/DDR301_A13: IC10.T3 (A13); also elsewhere on the board
/DDR3-2/DDR301_A14: IC10.T7 (A14); also elsewhere on the board
/DDR3-2/DDR301_BA0: IC10.M2 (BA0); also elsewhere on the board
/DDR3-2/DDR301_BA1: IC10.N8 (BA1); also elsewhere on the board
/DDR3-2/DDR301_BA2: IC10.M3 (BA2); also elsewhere on the board
/DDR3-2/DDR301_CLKE: IC10.K9 (CKE); also elsewhere on the board
/DDR3-2/DDR301_DQ0: IC10.E3 (DQ0); also elsewhere on the board
/DDR3-2/DDR301_DQ1: IC10.F7 (DQ1); also elsewhere on the board
/DDR3-2/DDR301_DQ2: IC10.F2 (DQ2); also elsewhere on the board
/DDR3-2/DDR301_DQ3: IC10.F8 (DQ3); also elsewhere on the board
/DDR3-2/DDR301_DQ4: IC10.H3 (DQ4); also elsewhere on the board
/DDR3-2/DDR301_DQ5: IC10.H8 (DQ5); also elsewhere on the board
/DDR3-2/DDR301_DQ6: IC10.G2 (DQ6); also elsewhere on the board
/DDR3-2/DDR301_DQ7: IC10.H7 (DQ7); also elsewhere on the board
/DDR3-2/DDR301_DQ8: IC10.D7 (DQ8); also elsewhere on the board
/DDR3-2/DDR301_DQ9: IC10.C3 (DQ9); also elsewhere on the board
/DDR3-2/DDR301_DQ10: IC10.C8 (DQ10); also elsewhere on the board
/DDR3-2/DDR301_DQ11: IC10.C2 (DQ11); also elsewhere on the board
/DDR3-2/DDR301_DQ12: IC10.A7 (DQ12); also elsewhere on the board
/DDR3-2/DDR301_DQ13: IC10.A2 (DQ13); also elsewhere on the board
/DDR3-2/DDR301_DQ14: IC10.B8 (DQ14); also elsewhere on the board
/DDR3-2/DDR301_DQ15: IC10.A3 (DQ15); also elsewhere on the board
/DDR3-2/DDR301_LDM: IC10.E7 (LDM); also elsewhere on the board
/DDR3-2/DDR301_LDQS_N: IC10.G3 (LDQS#); also elsewhere on the board
/DDR3-2/DDR301_LDQS_P: IC10.F3 (LDQS); also elsewhere on the board
/DDR3-2/DDR301_ODT: IC10.K1 (ODT); also elsewhere on the board
/DDR3-2/DDR301_UDM: IC10.D3 (UDM); also elsewhere on the board
/DDR3-2/DDR301_UDQS_N: IC10.B7 (UDQS#); also elsewhere on the board
/DDR3-2/DDR301_UDQS_P: IC10.C7 (UDQS); also elsewhere on the board
/DDR3-2/DDR301_nCAS: IC10.K3 (CAS#), R92.1; also elsewhere on the board
/DDR3-2/DDR301_nCS: IC10.L2 (CS#); also elsewhere on the board
/DDR3-2/DDR301_nRAS: IC10.J3 (RAS#); also elsewhere on the board
/DDR3-2/DDR301_nRST: IC10.T2 (RESET#), R91.1; also elsewhere on the board
/DDR3-2/DDR301_nWE: IC10.L3 (WE#); also elsewhere on the board
/DDR3-2/VREF_DDR3: C99.1, C100.1, C107.1, IC10.H1 (VREFDQ), IC10.M8 (VREFCA), R94.2, R95.1
GND: C99.2, C100.2, C101.2, C102.2, C103.2, C104.2, C105.2, C106.2, C107.2, C108.2, C109.2, C110.2, C111.2, C112.2, C113.2, C114.2, C115.2, C116.2, C117.2, C118.2, C119.2, C120.2, C121.2, C186.2, C238.2, IC10.A9 (VSS_1), IC10.B1 (VSSQ_1), IC10.B3 (VSS_2), IC10.B9 (VSSQ_2), IC10.D1 (VSSQ_3), IC10.D8 (VSSQ_4), IC10.E1 (VSS_3), IC10.E2 (VSSQ_5), IC10.E8 (VSSQ_6), IC10.F9 (VSSQ_7), IC10.G1 (VSSQ_8), IC10.G8 (VSS_4), IC10.G9 (VSSQ_9), IC10.J2 (VSS_5), IC10.J8 (VSS_6), IC10.M1 (VSS_7), IC10.M9 (VSS_8), IC10.P1 (VSS_9), IC10.P9 (VSS_10), IC10.T1 (VSS_11), IC10.T9 (VSS_12), R90.2, R91.2, R92.2, R95.2; also elsewhere on the board
unnamed: IC10.L8 (ZQ), R90.1

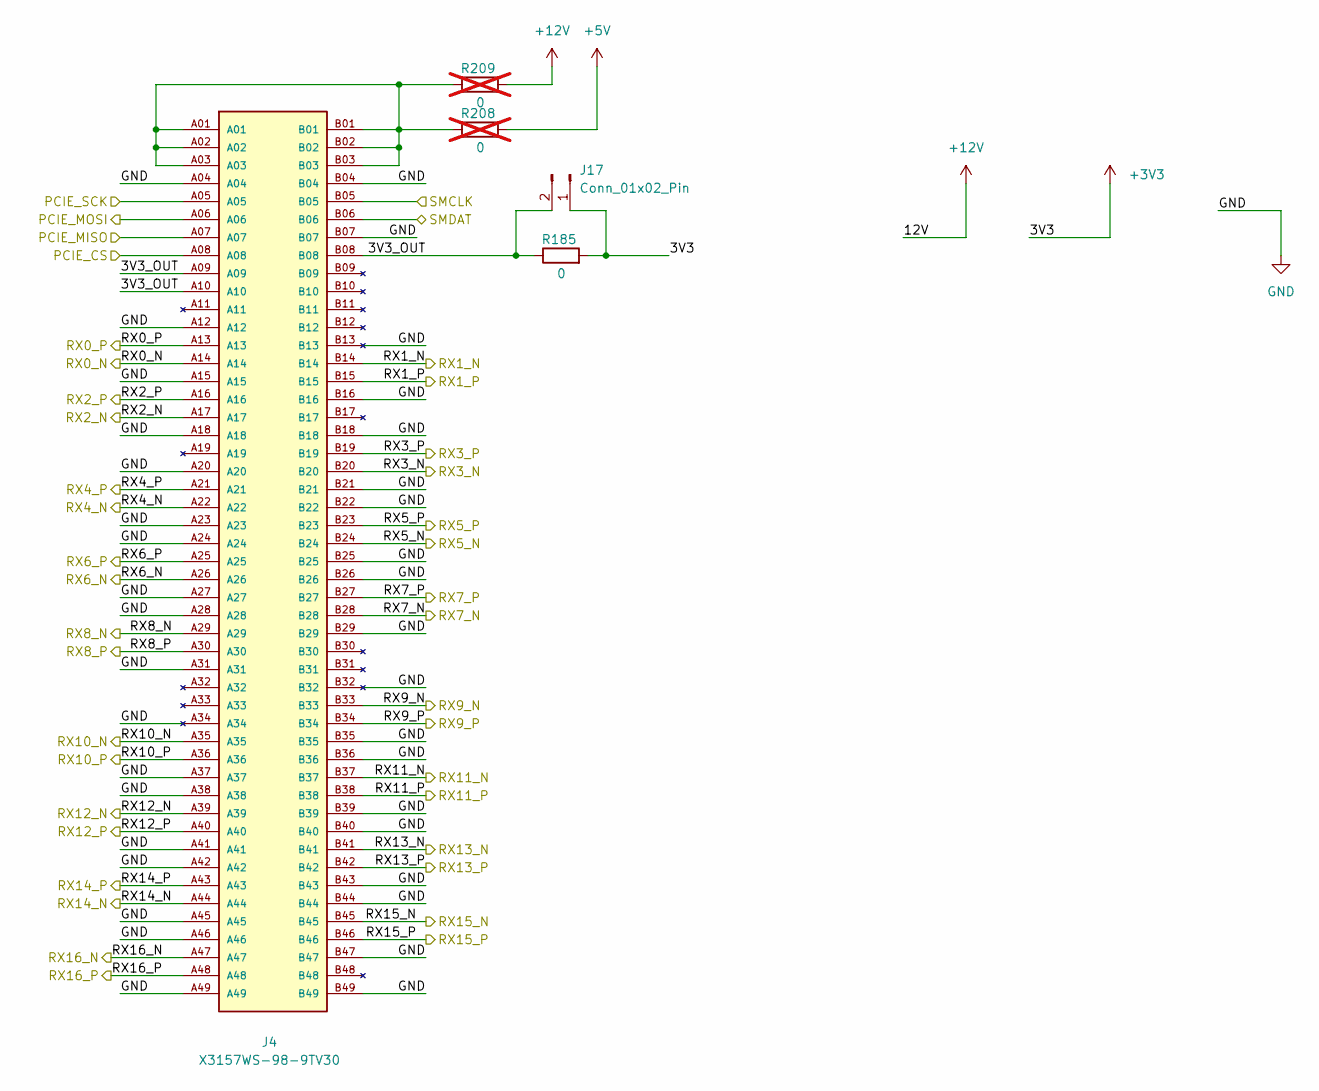
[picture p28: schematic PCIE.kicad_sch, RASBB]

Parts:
J4: X3157WS-98-9TV30; SAMTEC_PCIE-098-02-X-D-EMS3; Mfr. Part # X3157WS-98-9TV30; LCSC Part # C5711253
J17: Conn_01x02_Pin; PinHeader_1x02_P2.54mm_Vertical; Mfr. Part # PZ254V-11-02P; LCSC Part # C492401
R185: 0; R_1206_3216Metric; Mfr. Part # 1206W4F0000T5E; LCSC Part # C17888
R208, R209: 0; R_1206_3216Metric; Mfr. Part # 1206W4F0000T5E; LCSC Part # C17888; not fitted

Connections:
+3V3: J17.1, R185.2; also elsewhere on the board
+5V: R208.2; also elsewhere on the board
/PCIE/3V3_OUT: J4.A09, J4.A10, J4.B08, J17.2, R185.1
/PCIE/PCIE_CS: J4.A08; also elsewhere on the board
/PCIE/PCIE_MISO: J4.A07; also elsewhere on the board
/PCIE/PCIE_MOSI: J4.A06; also elsewhere on the board
/PCIE/PCIE_SCK: J4.A05; also elsewhere on the board
/PCIE/RX0_N: J4.A14; also elsewhere on the board
/PCIE/RX0_P: J4.A13; also elsewhere on the board
/PCIE/RX1_N: J4.B14; also elsewhere on the board
/PCIE/RX1_P: J4.B15; also elsewhere on the board
/PCIE/RX2_N: J4.A17; also elsewhere on the board
/PCIE/RX2_P: J4.A16; also elsewhere on the board
/PCIE/RX3_N: J4.B20; also elsewhere on the board
/PCIE/RX3_P: J4.B19; also elsewhere on the board
/PCIE/RX4_N: J4.A22; also elsewhere on the board
/PCIE/RX4_P: J4.A21; also elsewhere on the board
/PCIE/RX5_N: J4.B24; also elsewhere on the board
/PCIE/RX5_P: J4.B23; also elsewhere on the board
/PCIE/RX6_N: J4.A26; also elsewhere on the board
/PCIE/RX6_P: J4.A25; also elsewhere on the board
/PCIE/RX7_N: J4.B28; also elsewhere on the board
/PCIE/RX7_P: J4.B27; also elsewhere on the board
/PCIE/RX8_N: J4.A29; also elsewhere on the board
/PCIE/RX8_P: J4.A30; also elsewhere on the board
/PCIE/RX9_N: J4.B33; also elsewhere on the board
/PCIE/RX9_P: J4.B34; also elsewhere on the board
/PCIE/RX10_N: J4.A35; also elsewhere on the board
/PCIE/RX10_P: J4.A36; also elsewhere on the board
/PCIE/RX11_N: J4.B37; also elsewhere on the board
/PCIE/RX11_P: J4.B38; also elsewhere on the board
/PCIE/RX12_N: J4.A39; also elsewhere on the board
/PCIE/RX12_P: J4.A40; also elsewhere on the board
/PCIE/RX13_N: J4.B41; also elsewhere on the board
/PCIE/RX13_P: J4.B42; also elsewhere on the board
/PCIE/RX14_N: J4.A44; also elsewhere on the board
/PCIE/RX14_P: J4.A43; also elsewhere on the board
/PCIE/RX15_N: J4.B45; also elsewhere on the board
/PCIE/RX15_P: J4.B46; also elsewhere on the board
/PCIE/RX16_N: J4.A47; also elsewhere on the board
/PCIE/RX16_P: J4.A48; also elsewhere on the board
/PCIE/SMCLK: J4.B05; also elsewhere on the board
/PCIE/SMDAT: J4.B06; also elsewhere on the board
GND: J4.A04, J4.A12, J4.A15, J4.A18, J4.A20, J4.A23, J4.A24, J4.A27, J4.A28, J4.A31, J4.A34, J4.A37, J4.A38, J4.A41, J4.A42, J4.A45, J4.A46, J4.A49, J4.B04, J4.B07, J4.B13, J4.B16, J4.B18, J4.B21, J4.B22, J4.B25, J4.B26, J4.B29, J4.B32, J4.B35, J4.B36, J4.B39, J4.B40, J4.B43, J4.B44, J4.B47, J4.B49; also elsewhere on the board
unnamed: J4.A01, J4.A02, J4.A03, J4.B01, J4.B02, J4.B03, R208.1, R209.1

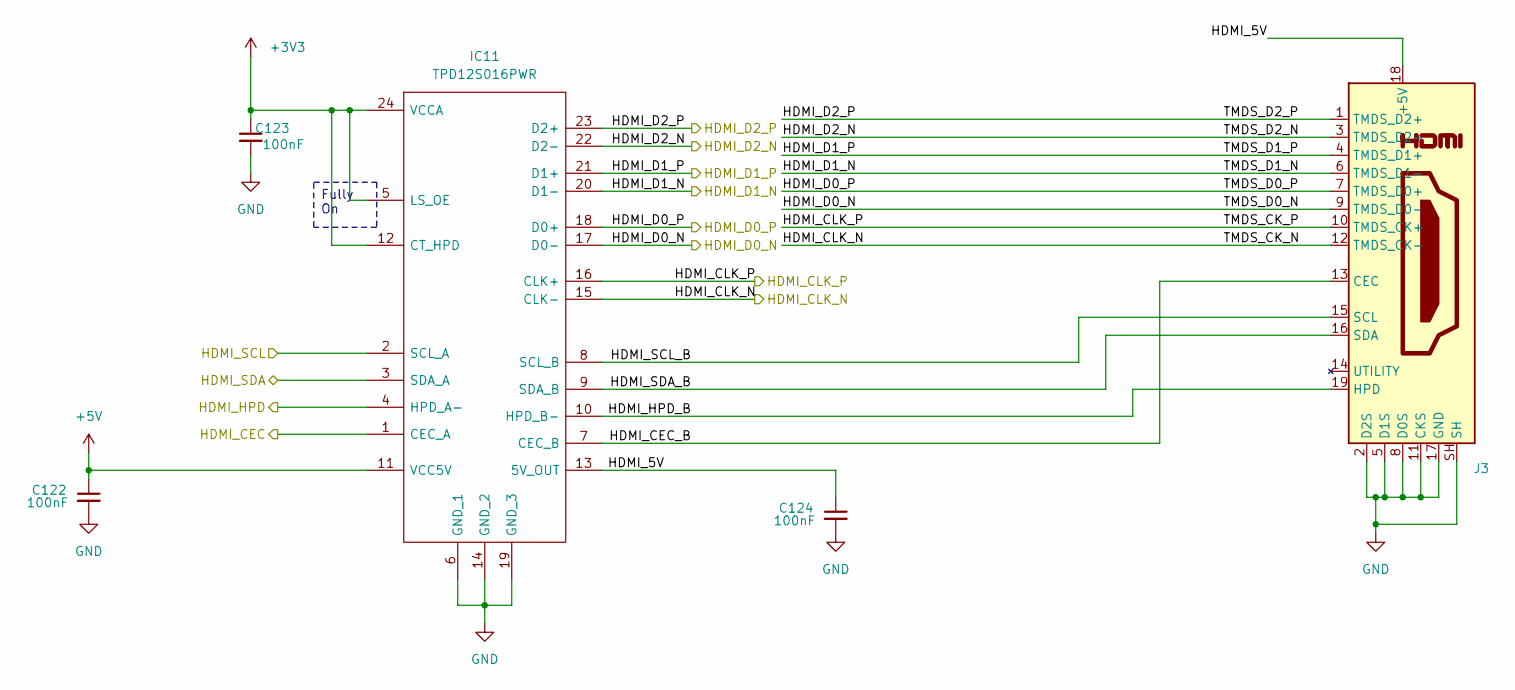
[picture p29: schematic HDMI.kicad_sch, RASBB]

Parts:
C122, C123, C124: 100nF; C_0402_1005Metric; Mfr. Part # 0402B104K500CT; LCSC Part # C152814
IC11: TPD12S016PWR; SOP65P640X120-24N; Mfr. Part # TPD12S016PWR; LCSC Part # C201665
J3: HDMI-001A; Mfr. Part # HDMI-001A; LCSC Part # C41347845

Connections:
+3V3: C123.1, IC11.5 (LS_OE), IC11.12 (CT_HPD), IC11.24 (VCCA); also elsewhere on the board
+5V: C122.1, IC11.11 (VCC5V); also elsewhere on the board
/FPGA-01/F1_B15_C15: IC11.4 (HPD_A-); also elsewhere on the board
/FPGA-01/F1_B15_D15: IC11.3 (SDA_A); also elsewhere on the board
/FPGA-01/F1_B15_E15: IC11.2 (SCL_A); also elsewhere on the board
/FPGA-01/F1_B15_E16: IC11.1 (CEC_A); also elsewhere on the board
/HDMI/HDMI_5V: C124.1, IC11.13 (5V_OUT), J3.18 (+5V)
/HDMI/HDMI_CEC_B: IC11.7 (CEC_B), J3.13 (CEC)
/HDMI/HDMI_CLK_N: IC11.15 (CLK-), J3.12 (TMDS_CK-); also elsewhere on the board
/HDMI/HDMI_CLK_P: IC11.16 (CLK+), J3.10 (TMDS_CK+); also elsewhere on the board
/HDMI/HDMI_D0_N: IC11.17 (D0-), J3.9 (TMDS_D0-); also elsewhere on the board
/HDMI/HDMI_D0_P: IC11.18 (D0+), J3.7 (TMDS_D0+); also elsewhere on the board
/HDMI/HDMI_D1_N: IC11.20 (D1-), J3.6 (TMDS_D1-); also elsewhere on the board
/HDMI/HDMI_D1_P: IC11.21 (D1+), J3.4 (TMDS_D1+); also elsewhere on the board
/HDMI/HDMI_D2_N: IC11.22 (D2-), J3.3 (TMDS_D2-); also elsewhere on the board
/HDMI/HDMI_D2_P: IC11.23 (D2+), J3.1 (TMDS_D2+); also elsewhere on the board
/HDMI/HDMI_HPD_B: IC11.10 (HPD_B-), J3.19 (HPD)
/HDMI/HDMI_SCL_B: IC11.8 (SCL_B), J3.15 (SCL)
/HDMI/HDMI_SDA_B: IC11.9 (SDA_B), J3.16 (SDA)
GND: C122.2, C123.2, C124.2, IC11.6 (GND_1), IC11.14 (GND_2), IC11.19 (GND_3), J3.2 (D2S), J3.5 (D1S), J3.8 (D0S), J3.11 (CKS), J3.17 (GND), J3.SH; also elsewhere on the board

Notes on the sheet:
Fully On

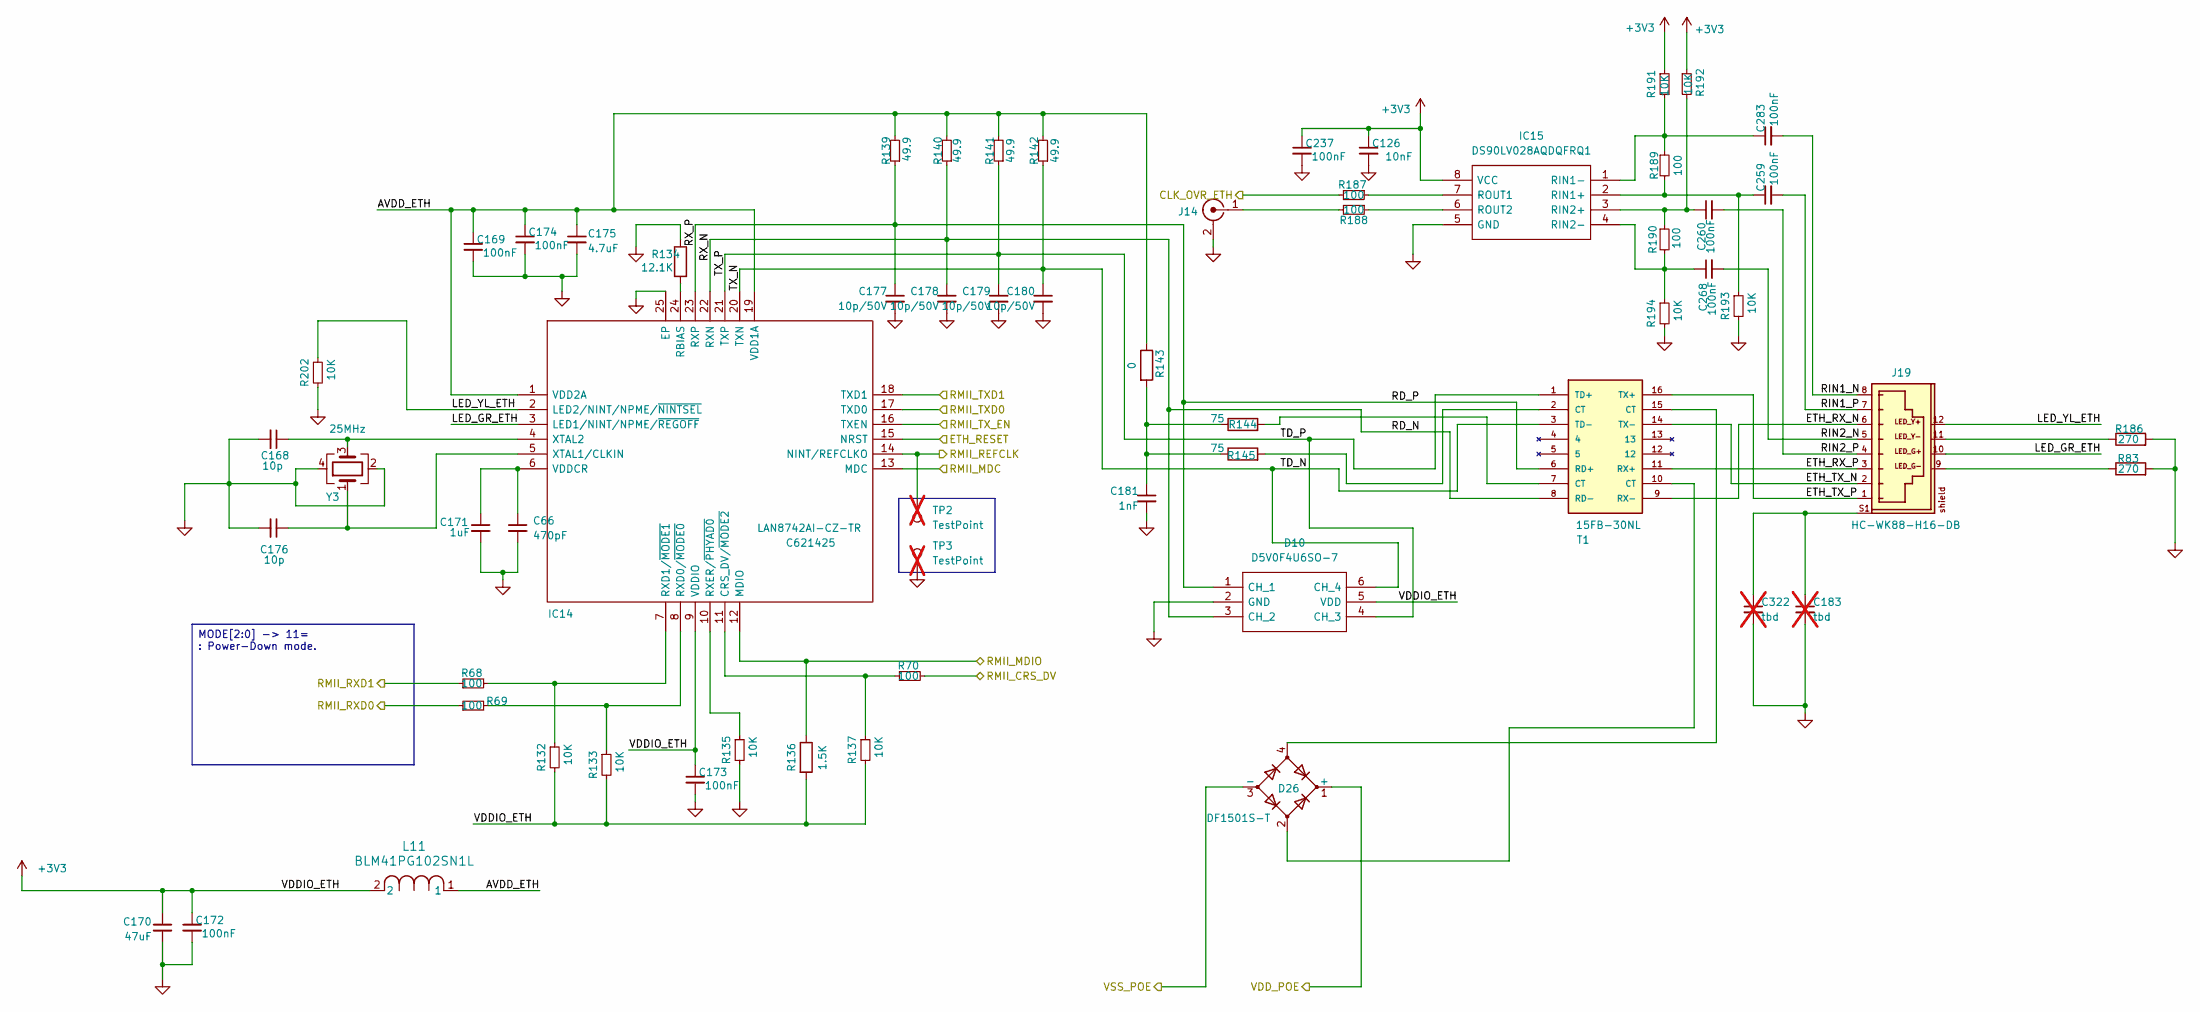
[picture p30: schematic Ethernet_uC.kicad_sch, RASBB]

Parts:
C66: 470pF; C_0402_1005Metric; Mfr. Part # CC0402JRNPO7BN471; LCSC Part # C526993
C126: 10nF; C_0402_1005Metric; Mfr. Part # 0402B103K500CT; LCSC Part # C301927
C168, C176: 10p; C_0402_1005Metric; Mfr. Part # 0402N100J500CT; LCSC Part # C301961
C169, C172, C173, C174, C237, C259, C260, C268, C283: 100nF; C_0402_1005Metric; Mfr. Part # 0402B104K500CT; LCSC Part # C152814
C170: 47uF; C_0805_2012Metric; Mfr. Part # GRM21BR61A476ME15L; LCSC Part # C124129
C171: 1uF; C_0402_1005Metric; Mfr. Part # 0402X105M160CT; LCSC Part # C3889771
C175: 4.7uF; C_0603_1608Metric; Mfr. Part # GMK107BBJ475KA-T; LCSC Part # C7281848
C177, C178, C179, C180: 10p/50V; C_0603_1608Metric; Mfr. Part # 0603N100J500CT; LCSC Part # C152928
C181: 1nF; C_1206_3216Metric; Mfr. Part # 1206B102K202CT; LCSC Part # C303946
C183, C322: tbd; C_1206_3216Metric; not fitted
D10: D5V0F4U6SO-7; SOT95P285X140-6N; Mfr. Part # D5V0F4U6SO-7; LCSC Part # C445539
D26: DF1501S-T; DF1501ST; Mfr. Part # DF1501S-T; LCSC Part # C155338
IC14: LAN8742AI-CZ-TR; QFN50P400X400X100-25N-D; Mfr. Part # LAN8742AI-CZ-TR; LCSC Part # C621425
IC15: DS90LV028AQDQFRQ1; SON50P200X200X80-8N; Mouser Part Number 595-S90LV028AQDQFRQ1
J14: 636101112001; J_Wurth_WR-UMRF_636101112001; Part Number 636101112001
J19: HC-WK88-H16-DB; Mfr. Part # HC-WK88-H16-DB; LCSC Part # C7501824
L11: BLM41PG102SN1L; IND_BLM41_1806_MUR-M; Mfr. Part # BLM41PG102SN1L; LCSC Part # C88999
R68, R69, R70, R187, R188, R189, R190: 100; R_0402_1005Metric; Mfr. Part # WR04X1000FTL; LCSC Part # C163808
R83, R186: 270; R_0402_1005Metric; Mfr. Part # SR04X271JTL; LCSC Part # C880838
R132, R133, R135, R137, R191, R192, R193, R194, R202: 10K; R_0402_1005Metric; Mfr. Part # WR04X1002FTL; LCSC Part # C163810
R134: 12.1K; R_0402_1005Metric; Mfr. Part # WR04X1212FTL; LCSC Part # C168199
R136: 1.5K; R_0402_1005Metric; Mfr. Part # WR04X152JTL; LCSC Part # C384376
R139, R140, R141, R142: 49.9; R_0402_1005Metric; Mfr. Part # RMCF0402FT49R9; LCSC Part # C4229190
R143: 0; R_0603_1608Metric; Mfr. Part # RCS06030000Z0EC; LCSC Part # C2094997
R144, R145: 75; R_0603_1608Metric; Mfr. Part # ESR03EZPF75R0; LCSC Part # C2074227
T1: 15FB-30NL; SOIC127P940X597-16N; Mfr. Part # 15FB-30NL; LCSC Part # C2987675
TP2, TP3: TestPoint; TestPoint_Pad_D1.0mm; not fitted
Y3: 25MHz; Crystal_SMD_3225-4Pin_3.2x2.5mm; Mfr. Part # XL2EL89CSI-111YLC-25M; LCSC Part # C5280577

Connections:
+3V3: C126.1, C170.1, C172.1, C173.1, C237.1, D10.5 (VDD), IC14.9 (VDDIO), IC15.8 (VCC), L11.2, R132.2, R133.2, R136.2, R137.2, R191.1, R192.1; also elsewhere on the board
/CLK_OVR_ETH: R187.2; also elsewhere on the board
/Ethernet_uC/AVDD_ETH: C169.1, C174.1, C175.1, IC14.1 (VDD2A), IC14.19 (VDD1A), L11.1, R139.2, R140.2, R141.2, R142.2, R143.1
/Ethernet_uC/ETH_RESET: IC14.15 (NRST); also elsewhere on the board
/Ethernet_uC/ETH_RX_N: J19.6, T1.9 (RX-)
/Ethernet_uC/ETH_RX_P: J19.3, T1.11 (RX+)
/Ethernet_uC/ETH_TX_N: J19.2, T1.14 (TX-)
/Ethernet_uC/ETH_TX_P: J19.1, T1.16 (TX+)
/Ethernet_uC/LED_GR_ETH: IC14.3 (LED1/NINT/NPME/~REGOFF), J19.10
/Ethernet_uC/LED_YL_ETH: IC14.2 (LED2/NINT/NPME/~NINTSEL), J19.12, R202.1
/Ethernet_uC/RD_N: C178.1, D10.3 (CH_2), IC14.22 (RXN), R140.1, T1.8 (RD-)
/Ethernet_uC/RD_P: C177.1, D10.1 (CH_1), IC14.23 (RXP), R139.1, T1.6 (RD+)
/Ethernet_uC/RIN1_N: C283.2, J19.8
/Ethernet_uC/RIN1_P: C259.2, J19.7
/Ethernet_uC/RIN2_N: C268.2, J19.5
/Ethernet_uC/RIN2_P: C260.2, J19.4
/Ethernet_uC/RMII_CRS_DV: R70.2; also elsewhere on the board
/Ethernet_uC/RMII_MDC: IC14.13 (MDC); also elsewhere on the board
/Ethernet_uC/RMII_MDIO: IC14.12 (MDIO), R136.1; also elsewhere on the board
/Ethernet_uC/RMII_REFCLK: IC14.14 (NINT/REFCLKO), TP2.1 (1_1); also elsewhere on the board
/Ethernet_uC/RMII_RXD0: R69.1; also elsewhere on the board
/Ethernet_uC/RMII_RXD1: R68.1; also elsewhere on the board
/Ethernet_uC/RMII_TXD0: IC14.17 (TXD0); also elsewhere on the board
/Ethernet_uC/RMII_TXD1: IC14.18 (TXD1); also elsewhere on the board
/Ethernet_uC/RMII_TX_EN: IC14.16 (TXEN); also elsewhere on the board
/Ethernet_uC/TD_N: C180.1, D10.6 (CH_4), IC14.20 (TXN), R142.1, T1.3 (TD-)
/Ethernet_uC/TD_P: C179.1, D10.4 (CH_3), IC14.21 (TXP), R141.1, T1.1 (TD+)
/VDC_IN: D26.1 (+); also elsewhere on the board
/VSS_POE: D26.3 (-); also elsewhere on the board
GND: C66.2, C126.2, C168.2, C169.2, C170.2, C171.2, C172.2, C173.2, C174.2, C175.2, C176.2, C177.2, C178.2, C179.2, C180.2, C181.2, C183.2, C237.2, C322.2, D10.2 (GND), IC14.25 (EP), IC15.5 (GND), J14.2 (Ext), R83.2, R134.1, R135.2, R186.2, R193.2, R194.2, R202.2, TP3.1 (1_1), Y3.2, Y3.4; also elsewhere on the board
unnamed: C181.1, R143.2, R144.1, R145.1
unnamed: C183.1, C322.1, J19.S1, J19.S2
unnamed: D26.2, T1.10 (CT)
unnamed: D26.4, T1.15 (CT)
unnamed: IC14.11 (CRS_DV/~MODE2), R70.1, R137.1
unnamed: IC14.24 (RBIAS), R134.2
unnamed: IC14.8 (RXD0/~MODE0), R69.2, R133.1
unnamed: IC14.7 (RXD1/~MODE1), R68.2, R132.1
unnamed: IC14.10 (RXER/~PHYAD0), R135.1
unnamed: C66.1, C171.1, IC14.6 (VDDCR)
unnamed: C176.1, IC14.5 (XTAL1/CLKIN), Y3.1
unnamed: C168.1, IC14.4 (XTAL2), Y3.3
unnamed: C259.1, IC15.2 (RIN1+), R189.2, R193.1
unnamed: C283.1, IC15.1 (RIN1-), R189.1, R191.2
unnamed: C260.1, IC15.3 (RIN2+), R190.1, R192.2
unnamed: C268.1, IC15.4 (RIN2-), R190.2, R194.1
unnamed: IC15.7 (ROUT1), R187.1
unnamed: IC15.6 (ROUT2), R188.1
unnamed: J14.1 (In), R188.2
unnamed: J19.9, R83.1
unnamed: J19.11, R186.1
unnamed: R144.2, T1.7 (CT)
unnamed: R145.2, T1.2 (CT)

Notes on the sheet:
MODE[2:0] -> 11= : Power-Down mode.

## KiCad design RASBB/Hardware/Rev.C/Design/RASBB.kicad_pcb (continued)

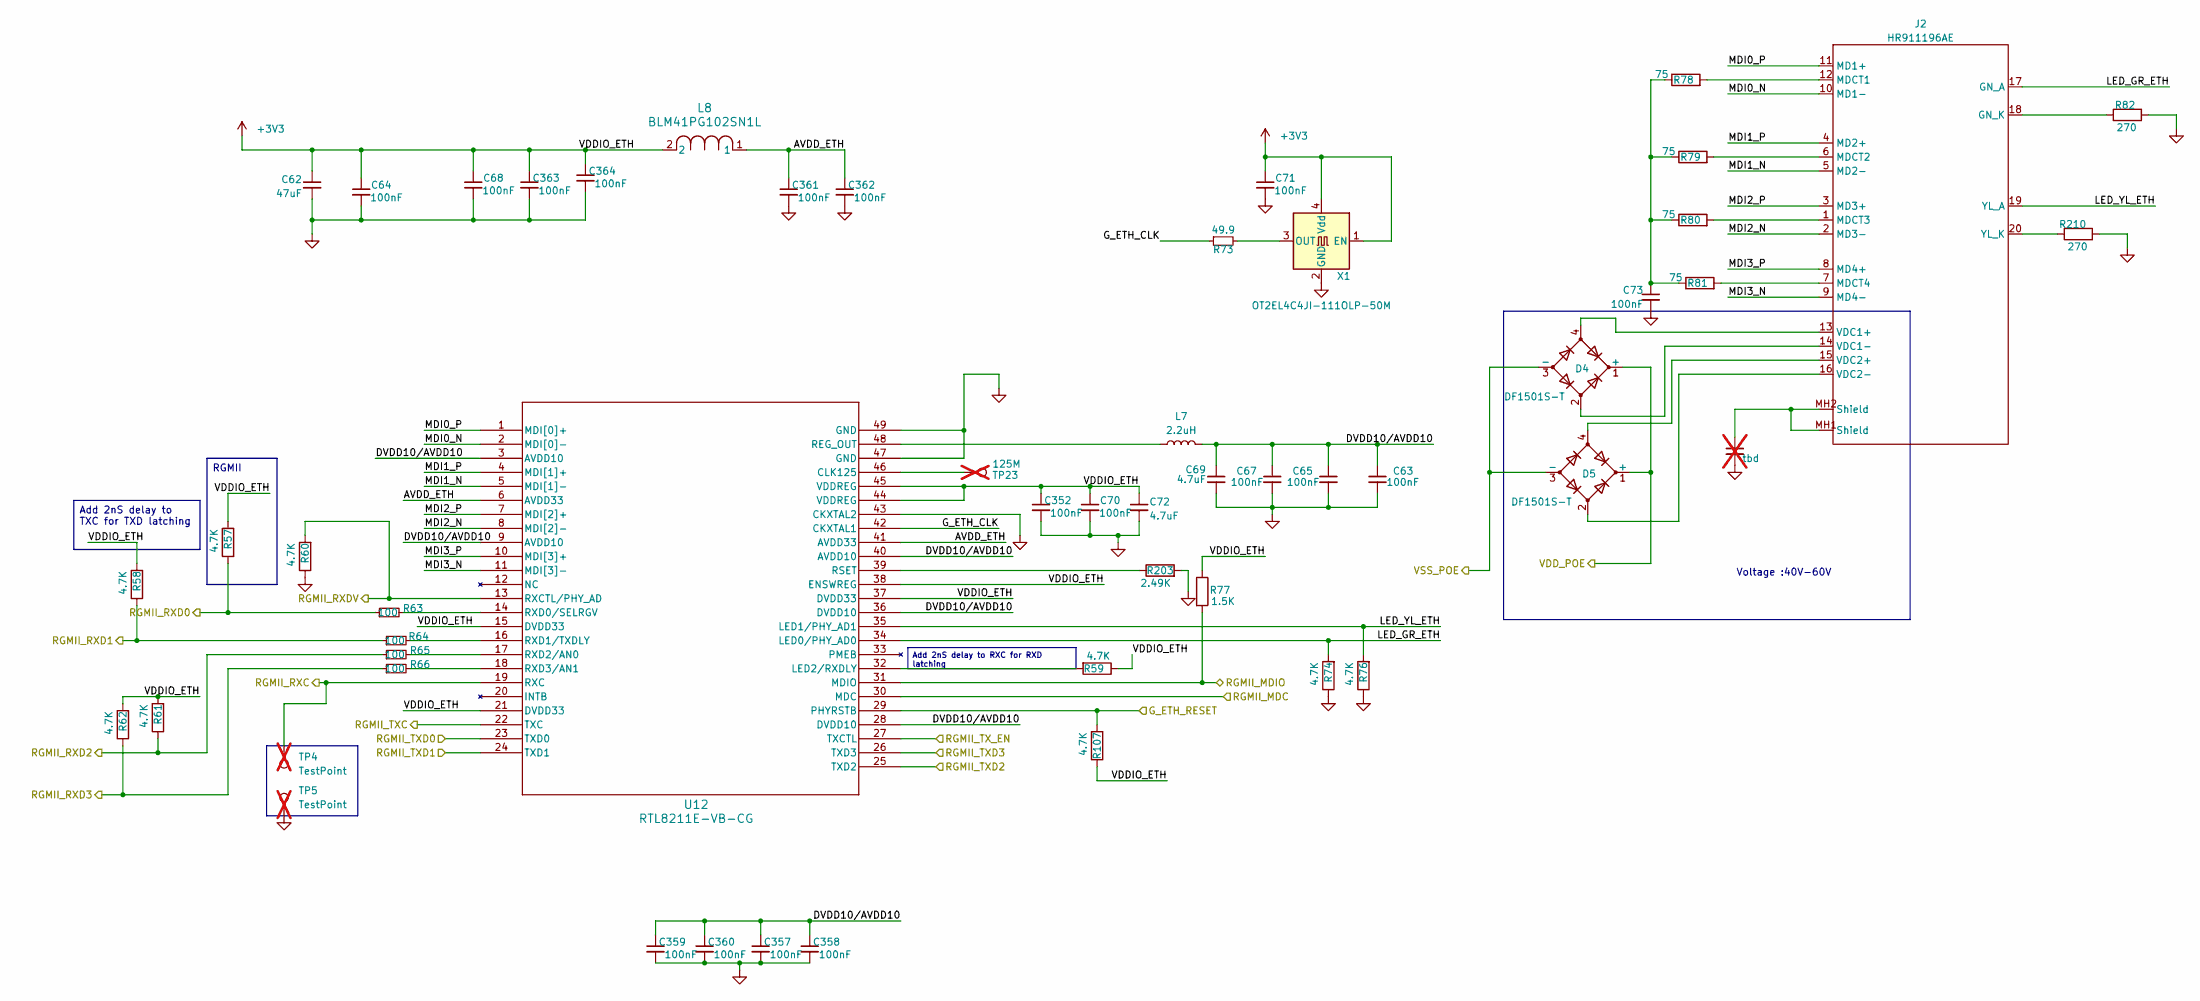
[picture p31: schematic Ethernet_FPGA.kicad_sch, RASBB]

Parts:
C62: 47uF; C_0805_2012Metric; Mfr. Part # GRM21BR61A476ME15L; LCSC Part # C124129
C63, C64, C65, C67, C68, C70, C71, C352, C357, C358, C359, C360, C361, C362, C363, C364: 100nF; C_0402_1005Metric; Mfr. Part # 0402B104K500CT; LCSC Part # C152814
C69, C72: 4.7uF; C_0402_1005Metric; Mfr. Part # GRM155R61A475KEAAD; LCSC Part # C77004
C73: 100nF; C_2220_5750Metric; Mfr. Part # FV55X104K202EGG; LCSC Part # C5290327
C74: tbd; C_1206_3216Metric; not fitted
D4, D5: DF1501S-T; DF1501ST; Mfr. Part # DF1501S-T; LCSC Part # C155338
J2: HR911196AE; JK00229NL; Mfr. Part # HR911196AE; LCSC Part # C5149194
L7: 2.2uH; L_1206_3216Metric; Mfr. Part # MGFL3216F2R2MT-LF; LCSC Part # C486337
L8: BLM41PG102SN1L; IND_BLM41_1806_MUR-M; Mfr. Part # BLM41PG102SN1L; LCSC Part # C88999
R57, R58, R59, R60, R61, R62, R74, R76, R107: 4.7K; R_0402_1005Metric; Mfr. Part # WR04X4701FTL; LCSC Part # C163826
R63, R64, R65, R66: 100; R_0402_1005Metric; Mfr. Part # WR04X1000FTL; LCSC Part # C163808
R73: 49.9; R_0402_1005Metric; Mfr. Part # RMCF0402FT49R9; LCSC Part # C4229190
R77: 1.5K; R_0402_1005Metric; Mfr. Part # WR04X152JTL; LCSC Part # C384376
R78, R79, R80, R81: 75; R_0603_1608Metric; Mfr. Part # ESR03EZPF75R0; LCSC Part # C2074227
R82, R210: 270; R_0402_1005Metric; Mfr. Part # SR04X271JTL; LCSC Part # C880838
R203: 2.49K; R_0402_1005Metric; Mfr. Part # RC0402FR-072K49L; LCSC Part # C114768
TP4, TP5: TestPoint; TestPoint_Pad_D1.0mm; not fitted
TP23: 125M; TestPoint_Pad_D1.0mm; not fitted
U12: RTL8211E-VB-CG; QFN48_6X6X0P85_RTK; Mfr. Part # RTL8211E-VB-CG; LCSC Part # C90735
X1: OT2EL4C4JI-111OLP-50M; Oscillator_SMD_Abracon_ASE-4Pin_3.2x2.5mm; Mfr. Part # OT2EL4C4JI-111OLP-50M; LCSC Part # C5203552

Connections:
+3V3: C62.1, C64.1, C68.1, C70.1, C71.1, C72.1, C352.1, C363.1, C364.1, L8.2, R57.2, R58.2, R59.1, R61.2, R62.2, R77.1, R107.1, U12.15 (DVDD33), U12.21 (DVDD33), U12.37 (DVDD33), U12.38 (ENSWREG), U12.44 (VDDREG), U12.45 (VDDREG), X1.1 (EN), X1.4 (Vdd); also elsewhere on the board
/Ethernet_FPGA/AVDD_ETH: C361.1, C362.1, L8.1, U12.6 (AVDD33), U12.41 (AVDD33)
/Ethernet_FPGA/DVDD10/AVDD10: C63.1, C65.1, C67.1, C69.1, C357.1, C358.1, C359.1, C360.1, L7.1, U12.3 (AVDD10), U12.9 (AVDD10), U12.28 (DVDD10), U12.36 (DVDD10), U12.40 (AVDD10)
/Ethernet_FPGA/G_ETH_CLK: R73.1, U12.42 (CKXTAL1)
/Ethernet_FPGA/G_ETH_RESET: R107.2, U12.29 (PHYRSTB); also elsewhere on the board
/Ethernet_FPGA/LED_GR_ETH: J2.17 (GN_A), R74.2, U12.34 (LED0/PHY_AD0)
/Ethernet_FPGA/LED_YL_ETH: J2.19 (YL_A), R76.2, U12.35 (LED1/PHY_AD1)
/Ethernet_FPGA/MDI0_N: J2.10 (MD1-), U12.2 (MDI[0]-)
/Ethernet_FPGA/MDI0_P: J2.11 (MD1+), U12.1 (MDI[0]+)
/Ethernet_FPGA/MDI1_N: J2.5 (MD2-), U12.5 (MDI[1]-)
/Ethernet_FPGA/MDI1_P: J2.4 (MD2+), U12.4 (MDI[1]+)
/Ethernet_FPGA/MDI2_N: J2.2 (MD3-), U12.8 (MDI[2]-)
/Ethernet_FPGA/MDI2_P: J2.3 (MD3+), U12.7 (MDI[2]+)
/Ethernet_FPGA/MDI3_N: J2.9 (MD4-), U12.11 (MDI[3]-)
/Ethernet_FPGA/MDI3_P: J2.8 (MD4+), U12.10 (MDI[3]+)
/Ethernet_FPGA/RGMII_MDC: U12.30 (MDC); also elsewhere on the board
/Ethernet_FPGA/RGMII_MDIO: R77.2, U12.31 (MDIO); also elsewhere on the board
/Ethernet_FPGA/RGMII_RXC: TP4.1 (1_1), U12.19 (RXC); also elsewhere on the board
/Ethernet_FPGA/RGMII_RXD0: R57.1, R63.1; also elsewhere on the board
/Ethernet_FPGA/RGMII_RXD1: R58.1, R64.1; also elsewhere on the board
/Ethernet_FPGA/RGMII_RXD2: R61.1, R65.1; also elsewhere on the board
/Ethernet_FPGA/RGMII_RXD3: R62.1, R66.1; also elsewhere on the board
/Ethernet_FPGA/RGMII_RXDV: R60.2, U12.13 (RXCTL/PHY_AD); also elsewhere on the board
/Ethernet_FPGA/RGMII_TXC: U12.22 (TXC); also elsewhere on the board
/Ethernet_FPGA/RGMII_TXD0: U12.23 (TXD0); also elsewhere on the board
/Ethernet_FPGA/RGMII_TXD1: U12.24 (TXD1); also elsewhere on the board
/Ethernet_FPGA/RGMII_TXD2: U12.25 (TXD2); also elsewhere on the board
/Ethernet_FPGA/RGMII_TXD3: U12.26 (TXD3); also elsewhere on the board
/Ethernet_FPGA/RGMII_TX_EN: U12.27 (TXCTL); also elsewhere on the board
/VDC_IN: D4.1 (+), D5.1 (+); also elsewhere on the board
/VSS_POE: D4.3 (-), D5.3 (-); also elsewhere on the board
GND: C62.2, C63.2, C64.2, C65.2, C67.2, C68.2, C69.2, C70.2, C71.2, C72.2, C73.2, C74.2, C352.2, C357.2, C358.2, C359.2, C360.2, C361.2, C362.2, C363.2, C364.2, R60.1, R74.1, R76.1, R82.2, R203.2, R210.2, TP5.1 (1_1), U12.43 (CKXTAL2), U12.47 (GND), U12.49 (GND), X1.2 (GND); also elsewhere on the board
unnamed: C73.1, R78.1, R79.1, R80.1, R81.1
unnamed: C74.1, J2.MH1 (Shield), J2.MH2 (Shield)
unnamed: J2.18 (GN_K), R82.1
unnamed: J2.12 (MDCT1), R78.2
unnamed: J2.6 (MDCT2), R79.2
unnamed: J2.1 (MDCT3), R80.2
unnamed: J2.7 (MDCT4), R81.2
unnamed: D4.4, J2.13 (VDC1+)
unnamed: D4.2, J2.14 (VDC1-)
unnamed: D5.4, J2.15 (VDC2+)
unnamed: D5.2, J2.16 (VDC2-)
unnamed: J2.20 (YL_K), R210.1
unnamed: TP23.1 (1_1), U12.46 (CLK125)
unnamed: R59.2, U12.32 (LED2/RXDLY)
unnamed: L7.2, U12.48 (REG_OUT)
unnamed: R203.1, U12.39 (RSET)
unnamed: R63.2, U12.14 (RXD0/SELRGV)
unnamed: R64.2, U12.16 (RXD1/TXDLY)
unnamed: R65.2, U12.17 (RXD2/AN0)
unnamed: R66.2, U12.18 (RXD3/AN1)
unnamed: R73.2, X1.3 (OUT)

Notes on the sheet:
Voltage :40V-60V
Add 2nS delay to TXC for TXD latching
RGMII
Add 2nS delay to RXC for RXD latching

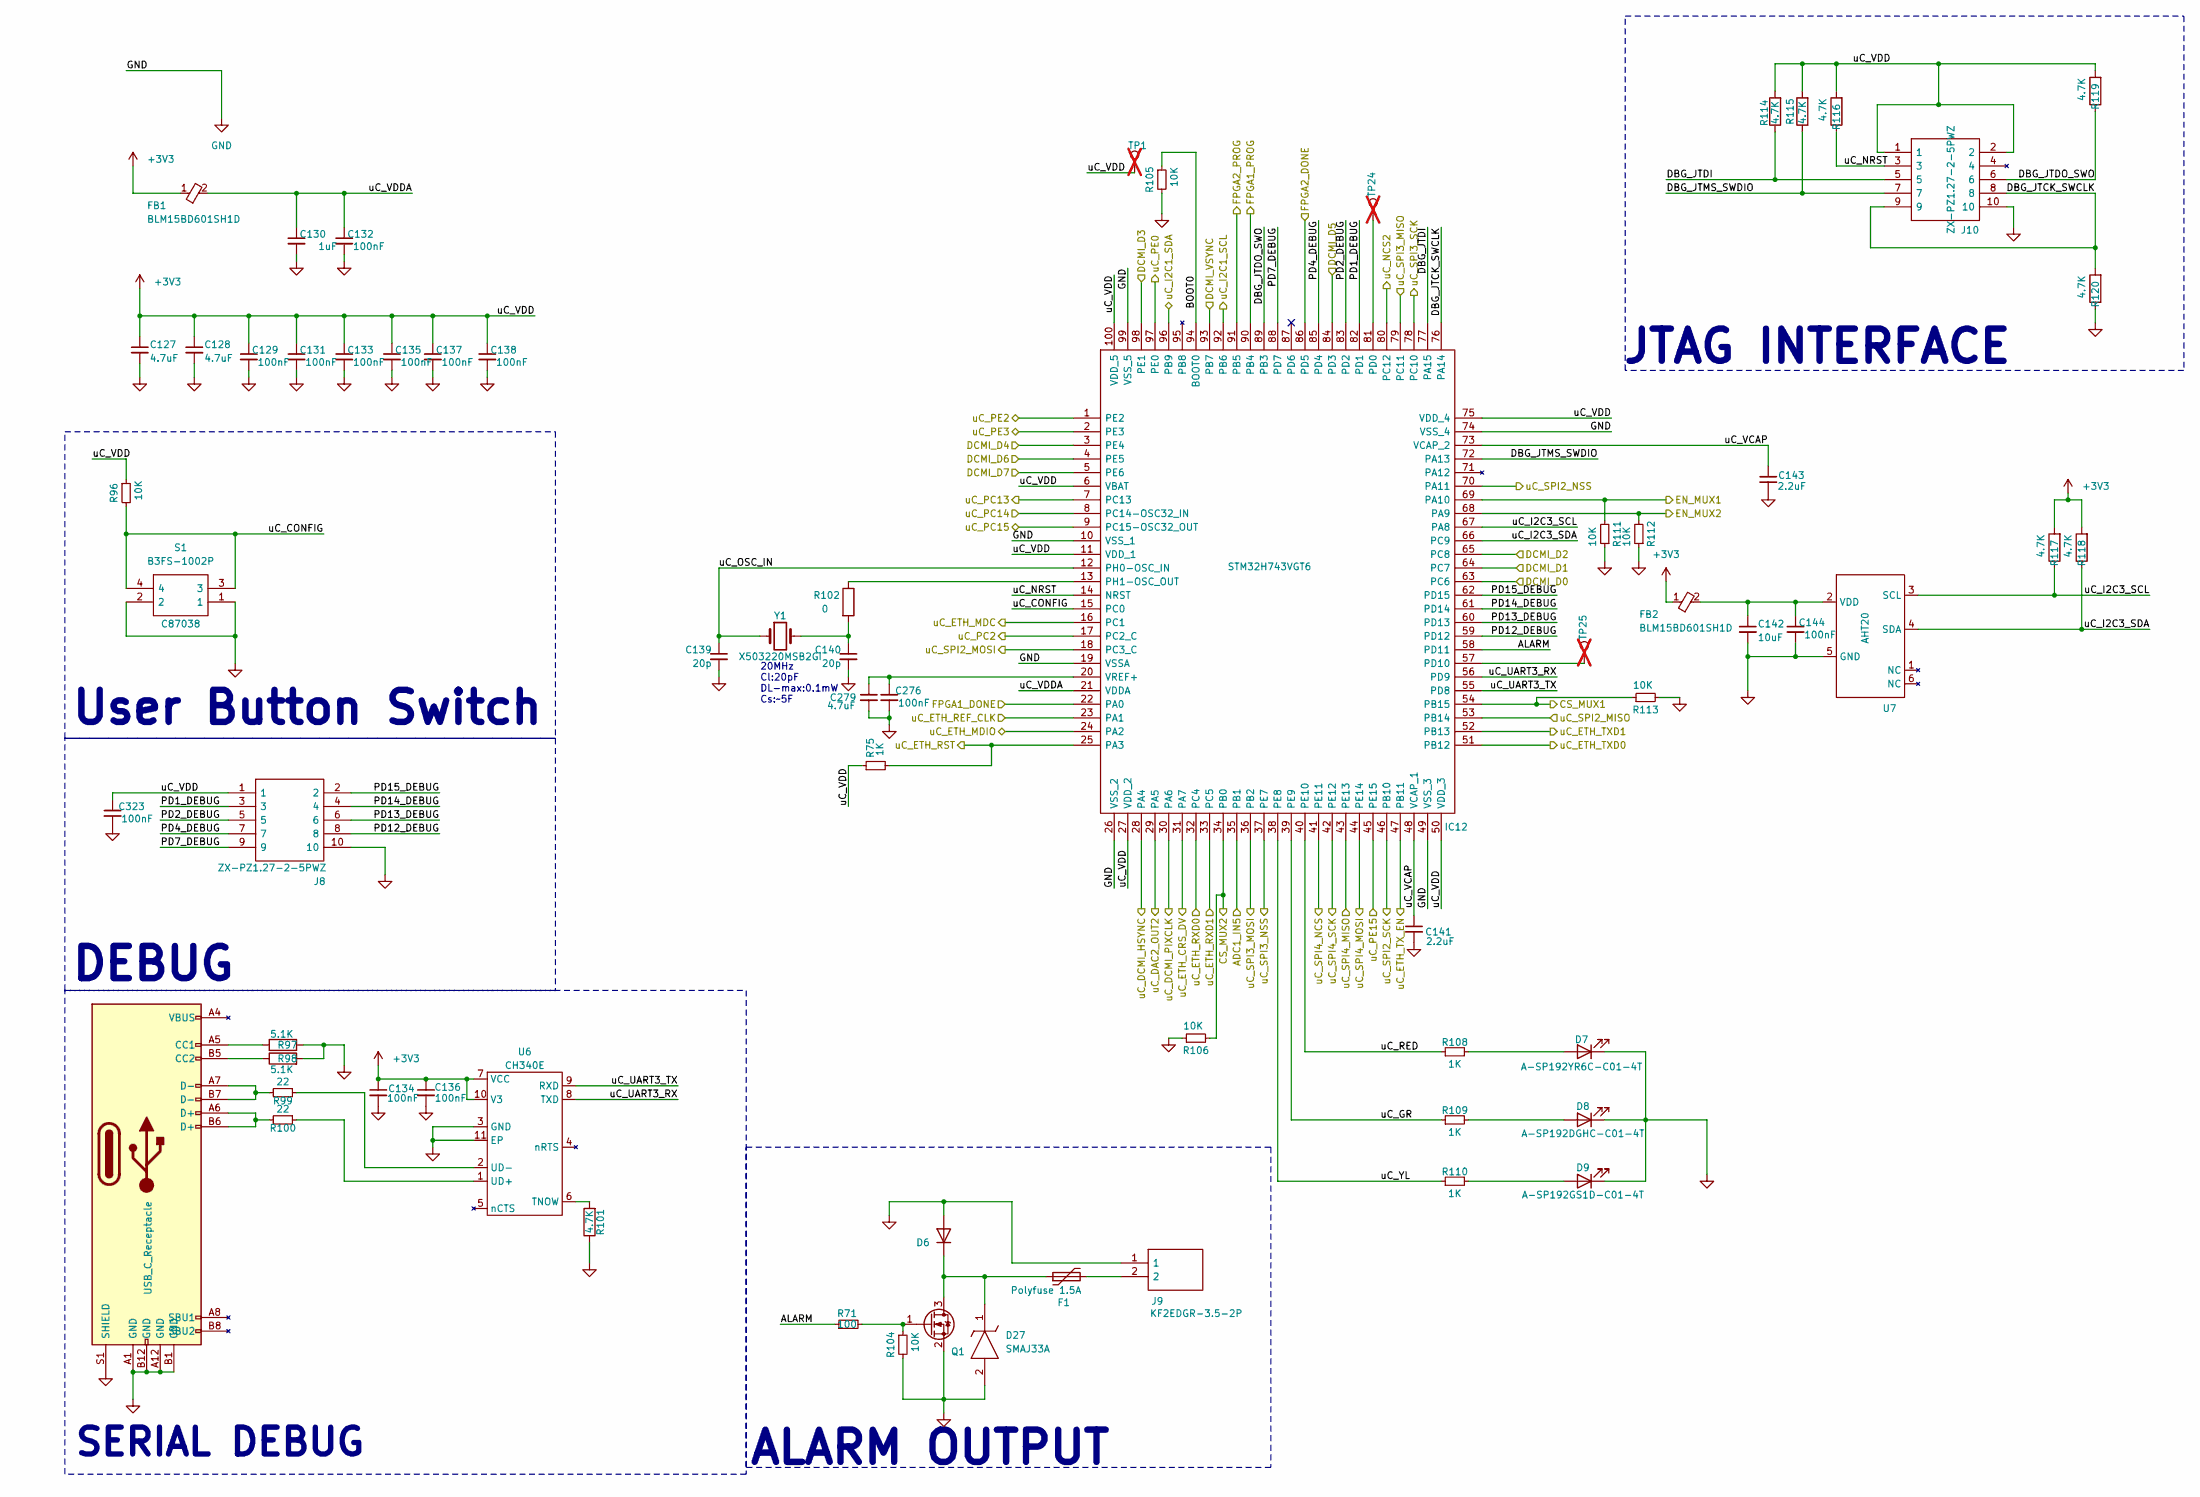
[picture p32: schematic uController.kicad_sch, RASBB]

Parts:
C127, C128, C279: 4.7uF; C_0603_1608Metric; Mfr. Part # GMK107BBJ475KA-T; LCSC Part # C7281848
C129, C131, C132, C133, C134, C135, C136, C137, C138, C144, C276, C323: 100nF; C_0402_1005Metric; Mfr. Part # 0402B104K500CT; LCSC Part # C152814
C130: 1uF; C_0402_1005Metric; Mfr. Part # 0402X105M160CT; LCSC Part # C3889771
C139, C140: 20p; C_0402_1005Metric; Mfr. Part # 0402N200J500CT; LCSC Part # C123468
C141, C143: 2.2uF; C_0402_1005Metric; Mfr. Part # 0402X225M160CT; LCSC Part # C3905586
C142: 10uF; C_0402_1005Metric; Mfr. Part # 0402X106M100CT; LCSC Part # C2992625
D6: S210_R1_00001; D_SMB; Mfr. Part # S210_R1_00001; LCSC Part # C391676
D7: A-SP192YR6C-C01-4T; LED_0603_1608Metric; Mfr. Part # A-SP192YR6C-C01-4T; LCSC Part # C5355433
D8: A-SP192DGHC-C01-4T; LED_0603_1608Metric; Mfr. Part # A-SP192DGHC-C01-4T; LCSC Part # C19171301
D9: A-SP192GS1D-C01-4T; LED_0603_1608Metric; Mfr. Part # A-SP192GS1D-C01-4T; LCSC Part # C5355434
D27: SMAJ33A; DIOM5026X229N; Mouser Part Number 576-SMAJ33A
F1: Polyfuse 1.5A; BSMD1812; Mfr. Part # BSMD1812-150-33V; LCSC Part # C883154
FB1, FB2: BLM15BD601SH1D; NFZ15SG152SN10B; Mfr. Part # BLM15BD601SH1D; LCSC Part # C710334
IC12: STM32H743VGT6; QFP50P1600X1600X160-100N; Mfr. Part # STM32H743VGT6; LCSC Part # C730183
J7: USB_C_Receptacle; USB_C_Receptacle_Palconn_UTC16-G; Mfr. Part # TYPE-C 16PIN 2MD(073); LCSC Part # C2765186
J8, J10: ZX-PZ1.27-2-5PWZ; PinHeader_2x05_P1.27mm_Vertical_SMD; Mfr. Part # ZX-PZ1.27-2-5PWZ; LCSC Part # C41370773
J9: KF2EDGR-3.5-2P; SHDRRA2W80P0X350_1X2_1050X920X750P; Mfr. Part # KF2EDGR-3.5-2P; LCSC Part # C441171
Q1: DMN6075S; SOT-23; Mfr. Part # DMN6075S; LCSC Part # C5122015
R71: 100; R_0402_1005Metric; Mfr. Part # WR04X1000FTL; LCSC Part # C163808
R75, R108, R109, R110: 1K; R_0402_1005Metric; Mfr. Part # MR04X1001FTL; LCSC Part # C327796
R96, R104, R105, R106, R111, R112, R113: 10K; R_0402_1005Metric; Mfr. Part # WR04X1002FTL; LCSC Part # C163810
R97, R98: 5.1K; R_0402_1005Metric; Mfr. Part # WR04X512JTL; LCSC Part # C384321
R99, R100: 22; R_0402_1005Metric; Mfr. Part # WR04X22R0FTL; LCSC Part # C163821
R101, R114, R115, R116, R117, R118, R119, R120: 4.7K; R_0402_1005Metric; Mfr. Part # WR04X4701FTL; LCSC Part # C163826
R102: 0; R_0402_1005Metric; Mfr. Part # MR04X000PTL; LCSC Part # C396825
S1: B3FS-1002P; B3FS-1000P; Mfr. Part # B3FS-1002P; LCSC Part # C87038
TP1, TP24, TP25: TestPoint; TestPoint_Pad_D1.0mm; not fitted
U6: CH340E; MSOP-10-1EP_3x3mm_P0.5mm_EP1.68x1.88mm; Mfr. Part # CH340E; LCSC Part # C99652
U7: AHT20; Mfr. Part # AHT20; LCSC Part # C2757850
Y1: X503220MSB2GI; Mfr. Part # X503220MSB2GI; LCSC Part # C112566

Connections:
+3V3: C127.1, C128.1, C129.1, C131.1, C133.1, C134.1, C135.1, C136.1, C137.1, C138.1, C323.1, FB1.1, FB2.1, IC12.6 (VBAT), IC12.11 (VDD_1), IC12.27 (VDD_2), IC12.50 (VDD_3), IC12.75 (VDD_4), IC12.100 (VDD_5), J8.1, J10.1, J10.2, R75.1, R96.1, R114.2, R115.2, R116.2, R117.2, R118.2, R119.2, TP1.1 (1_1), U6.7 (VCC), U6.10 (V3); also elsewhere on the board
/Audio_IN-OUT/Audio_PTT: IC12.45 (PE15); also elsewhere on the board
/CS2_FLASH_uC: IC12.80 (PC12); also elsewhere on the board
/CS_FLASH_uC: IC12.41 (PE11); also elsewhere on the board
/Config-SPI FLASH/MUX_EN1: IC12.69 (PA10), R111.2; also elsewhere on the board
/Config-SPI FLASH/MUX_EN2: IC12.68 (PA9), R112.2; also elsewhere on the board
/Config-SPI FLASH/SWITCH_FLASH_1: IC12.54 (PB15), R113.1; also elsewhere on the board
/Config-SPI FLASH/SWITCH_FLASH_2: IC12.34 (PB0), R106.2; also elsewhere on the board
/Ethernet_uC/ETH_RESET: IC12.25 (PA3), R75.2; also elsewhere on the board
/Ethernet_uC/RMII_MDC: IC12.16 (PC1); also elsewhere on the board
/Ethernet_uC/RMII_MDIO: IC12.24 (PA2); also elsewhere on the board
/Ethernet_uC/RMII_TX_EN: IC12.47 (PB11); also elsewhere on the board
/FPGA1_RESET: IC12.97 (PE0); also elsewhere on the board
/FPGA2_RESET: IC12.17 (PC2_C); also elsewhere on the board
/FPGA-01/BANK0/FPGA1_DONE: IC12.22 (PA0); also elsewhere on the board
/FPGA-01/FPGA1_PROG: IC12.90 (PB4); also elsewhere on the board
/FPGA-02/BANK0/FPGA2_DONE: IC12.86 (PD5); also elsewhere on the board
/FPGA-02/F2_B14_P15: IC12.98 (PE1); also elsewhere on the board
/FPGA-02/F2_B14_R15: IC12.3 (PE4); also elsewhere on the board
/FPGA-02/F2_B14_R16: IC12.4 (PE5); also elsewhere on the board
/FPGA-02/F2_B14_T15: IC12.5 (PE6); also elsewhere on the board
/FPGA-02/F2_B14_T16: IC12.28 (PA4); also elsewhere on the board
/FPGA-02/F2_B14_U14: IC12.64 (PC7); also elsewhere on the board
/FPGA-02/F2_B14_U16: IC12.30 (PA6); also elsewhere on the board
/FPGA-02/F2_B14_V14: IC12.63 (PC6); also elsewhere on the board
/FPGA-02/F2_B14_V15: IC12.65 (PC8); also elsewhere on the board
/FPGA-02/F2_B14_V16: IC12.84 (PD3); also elsewhere on the board
/FPGA-02/F2_B14_V17: IC12.93 (PB7); also elsewhere on the board
/FPGA-02/FPGA2_PROG: IC12.91 (PB5); also elsewhere on the board
/PCIE/PCIE_CS: IC12.37 (PE7); also elsewhere on the board
/PCIE/SMCLK: IC12.92 (PB6); also elsewhere on the board
/PCIE/SMDAT: IC12.96 (PB9); also elsewhere on the board
/RF_Transceiver/BUSY_LORA_G: IC12.8 (PC14-OSC32_IN); also elsewhere on the board
/RF_Transceiver/DIO1_LORA_G: IC12.1 (PE2); also elsewhere on the board
/RF_Transceiver/DIO2_LORA_G: IC12.2 (PE3); also elsewhere on the board
/RF_Transceiver/DIO3_LORA_G: IC12.9 (PC15-OSC32_OUT); also elsewhere on the board
/RF_Transceiver/NRST_LORA_G: IC12.7 (PC13); also elsewhere on the board
/RF_Transceiver/SPI_NSS_LORA_G: IC12.70 (PA11); also elsewhere on the board
/SO_FLASH_uC: IC12.43 (PE13); also elsewhere on the board
/uController/ADC1_IN5: IC12.35 (PB1); also elsewhere on the board
/uController/ALARM: IC12.58 (PD11), R71.1
/uController/BOOT0: IC12.94 (BOOT0), R105.1
/uController/DBG_JTCK_SWCLK: IC12.76 (PA14), J10.8, J10.9, R120.2
/uController/DBG_JTDI: IC12.77 (PA15), J10.5, R114.1
/uController/DBG_JTDO_SWO: IC12.89 (PB3), J10.6, R119.1
/uController/DBG_JTMS_SWDIO: IC12.72 (PA13), J10.7, R115.1
/uController/PD1_DEBUG: IC12.82 (PD1), J8.3
/uController/PD2_DEBUG: IC12.83 (PD2), J8.5
/uController/PD4_DEBUG: IC12.85 (PD4), J8.7
/uController/PD7_DEBUG: IC12.88 (PD7), J8.9
/uController/PD12_DEBUG: IC12.59 (PD12), J8.8
/uController/PD13_DEBUG: IC12.60 (PD13), J8.6
/uController/PD14_DEBUG: IC12.61 (PD14), J8.4
/uController/PD15_DEBUG: IC12.62 (PD15), J8.2
/uController/uC_CONFIG: IC12.15 (PC0), R96.2, S1.3, S1.4
/uController/uC_DAC2_OUT2: IC12.29 (PA5); also elsewhere on the board
/uController/uC_ETH_CRS_DV: IC12.31 (PA7); also elsewhere on the board
/uController/uC_ETH_REF_CLK: IC12.23 (PA1); also elsewhere on the board
/uController/uC_ETH_RXD0: IC12.32 (PC4); also elsewhere on the board
/uController/uC_ETH_RXD1: IC12.33 (PC5); also elsewhere on the board
/uController/uC_ETH_TXD0: IC12.51 (PB12); also elsewhere on the board
/uController/uC_ETH_TXD1: IC12.52 (PB13); also elsewhere on the board
/uController/uC_GR: IC12.39 (PE9), R109.1
/uController/uC_I2C3_SCL: IC12.67 (PA8), R117.1, U7.3 (SCL)
/uController/uC_I2C3_SDA: IC12.66 (PC9), R118.1, U7.4 (SDA)
/uController/uC_NRST: IC12.14 (NRST), J10.3, R116.1
/uController/uC_OSC_IN: C139.1, IC12.12 (PH0-OSC_IN), Y1.1
/uController/uC_RED: IC12.40 (PE10), R108.1
/uController/uC_SPI2_MISO: IC12.53 (PB14); also elsewhere on the board
/uController/uC_SPI2_MOSI: IC12.18 (PC3_C); also elsewhere on the board
/uController/uC_SPI2_SCK: IC12.46 (PB10); also elsewhere on the board
/uController/uC_SPI3_MISO: IC12.79 (PC11); also elsewhere on the board
/uController/uC_SPI3_MOSI: IC12.36 (PB2); also elsewhere on the board
/uController/uC_SPI3_SCK: IC12.78 (PC10); also elsewhere on the board
/uController/uC_SPI4_MOSI: IC12.44 (PE14); also elsewhere on the board
/uController/uC_SPI4_SCK: IC12.42 (PE12); also elsewhere on the board
/uController/uC_UART3_RX: IC12.56 (PD9), U6.8 (TXD)
/uController/uC_UART3_TX: IC12.55 (PD8), U6.9 (RXD)
/uController/uC_VCAP: C141.1, C143.1, IC12.48 (VCAP_1), IC12.73 (VCAP_2)
/uController/uC_VDDA: C130.1, C132.1, FB1.2, IC12.21 (VDDA)
/uController/uC_YL: IC12.38 (PE8), R110.1
GND: C127.2, C128.2, C129.2, C130.2, C131.2, C132.2, C133.2, C134.2, C135.2, C136.2, C137.2, C138.2, C139.2, C140.2, C141.2, C142.2, C143.2, C144.2, C276.2, C279.2, C323.2, D6.2 (A), D7.1 (K), D8.1 (K), D9.1 (K), D27.2, IC12.10 (VSS_1), IC12.19 (VSSA), IC12.26 (VSS_2), IC12.49 (VSS_3), IC12.74 (VSS_4), IC12.99 (VSS_5), J7.A1 (GND), J7.A12 (GND), J7.B1 (GND), J7.B12 (GND), J7.S1 (SHIELD), J8.10, J9.1, J10.10, Q1.2 (S), R97.2, R98.2, R101.1, R104.2, R105.2, R106.1, R111.1, R112.1, R113.2, R120.1, S1.1, S1.2, U6.3 (GND), U6.11 (EP), U7.5 (GND); also elsewhere on the board
unnamed: C140.1, R102.2, Y1.2
unnamed: D6.1 (K), D27.1, F1.1, Q1.3 (D)
unnamed: D7.2 (A), R108.2
unnamed: D8.2 (A), R109.2
unnamed: D9.2 (A), R110.2
unnamed: F1.2, J9.2
unnamed: IC12.81 (PD0), TP24.1 (1_1)
unnamed: IC12.57 (PD10), TP25.1 (1_1)
unnamed: IC12.13 (PH1-OSC_OUT), R102.1
unnamed: C276.1, C279.1, IC12.20 (VREF+)
unnamed: J7.A5 (CC1), R97.1
unnamed: J7.B5 (CC2), R98.1
unnamed: J7.A6 (D+), J7.B6 (D+), R100.2
unnamed: J7.A7 (D-), J7.B7 (D-), R99.2
unnamed: Q1.1 (G), R71.2, R104.1
unnamed: R101.2, U6.6 (TNOW)
unnamed: R100.1, U6.1 (UD+)
unnamed: R99.1, U6.2 (UD-)
unnamed: C142.1, C144.1, FB2.2, U7.2 (VDD)

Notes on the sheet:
20MHz Cl:20pF DL-max:0.1mW Cs:~5F
DEBUG
SERIAL DEBUG
User Button Switch
ALARM OUTPUT
JTAG INTERFACE


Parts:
C58, C59, C60, C61: 100nF; C_0402_1005Metric; Mfr. Part # 0402B104K500CT; LCSC Part # C152814
IC5, IC7: S25FL128LAGMFI010; SOIC127P800X216-8N; Mfr. Part # S25FL128LAGMFI010; LCSC Part # C2959152
IC6, IC8: TS3A5018DBQR; SOP64P600X175-16N; Mfr. Part # TS3A5018DBQR; LCSC Part # C202285
R53, R55, R196, R197, R198, R199: 4K7; R_0402_1005Metric; Mfr. Part # RC0402FR-074K7L; LCSC Part # C105871

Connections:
+3V3: C58.1, C59.1, C60.1, C61.1, IC5.8 (VCC), IC6.16 (V+), IC7.8 (VCC), IC8.16 (V+), R53.1, R55.1, R196.1, R197.1, R198.1, R199.1; also elsewhere on the board
/CS_FLASH_FPGA2: IC8.2 (NC1); also elsewhere on the board
/CS_FLASH_uC: IC6.3 (NO1), IC8.3 (NO1); also elsewhere on the board
/Config-SPI FLASH/CS_Flash_FPGA1: IC6.2 (NC1); also elsewhere on the board
/Config-SPI FLASH/MUX_EN1: IC6.15 (~EN); also elsewhere on the board
/Config-SPI FLASH/MUX_EN2: IC8.15 (~EN); also elsewhere on the board
/Config-SPI FLASH/SCK_Flash_FPGA1: IC6.14 (NC4); also elsewhere on the board
/Config-SPI FLASH/SCK_Flash_FPGA2: IC8.14 (NC4); also elsewhere on the board
/Config-SPI FLASH/SI_Flash_FPGA1: IC6.11 (NC3); also elsewhere on the board
/Config-SPI FLASH/SI_Flash_FPGA2: IC8.11 (NC3); also elsewhere on the board
/Config-SPI FLASH/SO_Flash_FPGA1: IC6.5 (NC2); also elsewhere on the board
/Config-SPI FLASH/SO_Flash_FPGA2: IC8.5 (NC2); also elsewhere on the board
/Config-SPI FLASH/SWITCH_FLASH_1: IC6.1 (IN); also elsewhere on the board
/Config-SPI FLASH/SWITCH_FLASH_2: IC8.1 (IN); also elsewhere on the board
/SCK_FLASH_uC: IC6.13 (NO4), IC8.13 (NO4); also elsewhere on the board
/SI_FLASH_uC: IC6.10 (NO3), IC8.10 (NO3); also elsewhere on the board
/SO_FLASH_uC: IC6.6 (NO2), IC8.6 (NO2); also elsewhere on the board
GND: C58.2, C59.2, C60.2, C61.2, IC5.4 (VSS), IC6.8 (GND), IC7.4 (VSS), IC8.8 (GND); also elsewhere on the board
unnamed: IC5.1 (CS#), IC6.4 (COM1), R53.2
unnamed: IC5.7 (IO3/RESET#), R199.2
unnamed: IC5.6 (SCK), IC6.12 (COM4)
unnamed: IC5.5 (SI/IO0), IC6.9 (COM3)
unnamed: IC5.2 (SO/IO1), IC6.7 (COM2)
unnamed: IC5.3 (WP#/IO2), R198.2
unnamed: IC7.1 (CS#), IC8.4 (COM1), R55.2
unnamed: IC7.7 (IO3/RESET#), R196.2
unnamed: IC7.6 (SCK), IC8.12 (COM4)
unnamed: IC7.5 (SI/IO0), IC8.9 (COM3)
unnamed: IC7.2 (SO/IO1), IC8.7 (COM2)
unnamed: IC7.3 (WP#/IO2), R197.2

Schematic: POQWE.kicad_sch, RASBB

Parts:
C3, C7: 10nF; C_0603_1608Metric; Mfr. Part # CGA0603X7R103K101JT; LCSC Part # C6119837
C4: 10uF/100V; C_1206_3216Metric; Mfr. Part # C3216X6S2A106K160AC; LCSC Part # C6872041
C5, C6: 4.7uF; C_1206_3216Metric; Mfr. Part # GRM31CZ72A475KE11L; LCSC Part # C2997285
C8: 22pF; C_0402_1005Metric; Mfr. Part # CC0402JRNPO7BN220; LCSC Part # C2175872
C9: 4.7nF; C_0402_1005Metric; Mfr. Part # CC0402KRX7R6BB472; LCSC Part # C1852867
C10, C16, C18, C27, C28, C31, C33, C34, C35, C36, C37, C55, C356: 100nF; C_0402_1005Metric; Mfr. Part # 0402B104K500CT; LCSC Part # C152814
C11, C38, C39, C40, C50, C51: 10nF; C_0402_1005Metric; Mfr. Part # 0402B103K500CT; LCSC Part # C301927
C12, C13, C14, C15, C21, C22, C23, C24, C25, C26: 10uF; C_1206_3216Metric; Mfr. Part # CGA5L1X7R1H106KT0Y0N; LCSC Part # C531431
C17: 33uF; EEE0JA152UAP; Mfr. Part # EEE-FP1V330AP; LCSC Part # C178581
C19: 1uF; C_0402_1005Metric; Mfr. Part # 0402X105M160CT; LCSC Part # C3889771
C20: 4.7uF; C_0402_1005Metric; Mfr. Part # GRM155R61A475KEAAD; LCSC Part # C77004
C29: 4.7uF; C_0603_1608Metric; Mfr. Part # GMK107BBJ475KA-T; LCSC Part # C7281848
C30, C32: 470nF; C_0402_1005Metric; Mfr. Part # GRT155R71A474KE01D; LCSC Part # C471404
C41: 10pF; C_0402_1005Metric; Mfr. Part # C0402C100J4GAC7867; LCSC Part # C2182752
C42, C46, C49, C52: 47uF; C_0805_2012Metric; Mfr. Part # GRM21BR61A476ME15L; LCSC Part # C124129
C43: 5.1pF; C_0402_1005Metric; Mfr. Part # GRM1555C1E5R1CA01D; LCSC Part # C3855079
C44, C45, C47, C48, C53, C54, C56, C57: 22uF; C_0603_1608Metric; Mfr. Part # 0603YD226MAT2A; LCSC Part # C6776252
C354, C355: 2.2uF; C_0805_2012Metric; Mfr. Part # 0805B225K500CT; LCSC Part # C2918681
D1: SDT5A60SA-13; SDT5A60SA13; Mfr. Part # SDT5A60SA-13; LCSC Part # C3024223
D2, D3: VSSAF5L45HM3_A_H; SODFL5226X100N; Mfr. Part # VSSAF5L45HM3_A/H; LCSC Part # C6000165
D17, D18, D19, D20, D21: A-SP192DGHC-C01-4T; LED_0603_1608Metric; Mfr. Part # A-SP192DGHC-C01-4T; LCSC Part # C19171301
F2: Polyfuse 2A; BSMD1812; Mfr. Part # BSMD1812-200-30V; LCSC Part # C960026
IC1: RT6365GSP; SOIC127P600X175-9N; Mfr. Part # RT6365GSP; LCSC Part # C3024482
IC2, IC4: TPS56528DDAR; SOIC127P600X170-9N; Mfr. Part # TPS56528DDAR; LCSC Part # C138716
IC3: TPS563201DDCR; SOT95P280X110-6N; Mfr. Part # TPS563201DDCR; LCSC Part # C116592
J1: PJ-002AH-SMT-TR; CUI_PJ-002AH-SMT-TR; Mfr. Part # PJ-002AH-SMT-TR; LCSC Part # C22434687
L1: 10uH; 0630CDMCDDS-100MC; Mfr. Part # 0630CDMCDDS-100MC; LCSC Part # C2595948
L2: 15uH; SMDRS6028-150N; Mfr. Part # SMDRS6028-150N; LCSC Part # C163563
L3: 360nH; INDPM109103X400N; Mfr. Part # IHLP4040DZERR36M01; LCSC Part # C845083
L4, L5, L6: 2.2uH; IND_IHLP-2525CZ_VIS; Mfr. Part # IHLP2525EZER2R2M01; LCSC Part # C845037
R25: 24.9K; R_1206_3216Metric; Mfr. Part # WR12X2492FTL; LCSC Part # C171074
R26: 249K; R_0805_2012Metric; Mfr. Part # WR08X2493FTL; LCSC Part # C170853
R27: 51K; R_0603_1608Metric; Mfr. Part # WR06X5102FTL; LCSC Part # C227390
R28: 590K; R_0402_1005Metric; Mfr. Part # WR04X5903FTL; LCSC Part # C172103
R29, R30: 18K; R_0402_1005Metric; Mfr. Part # WR04X1802FTL; LCSC Part # C168206
R31: 120K; R_0402_1005Metric; Mfr. Part # RC0402JR-07120KL; LCSC Part # C137924
R32, R44: 3.3; R_0402_1005Metric; Mfr. Part # CRCW04023R30FKEDC; LCSC Part # C384380
R33: 180K; R_0402_1005Metric; Mfr. Part # WR04X1803FTL; LCSC Part # C168207
R34: 12K; R_0402_1005Metric; Mfr. Part # SR04X1202FTL; LCSC Part # C2991361
R35, R41, R42, R43, R49: 100K; R_0402_1005Metric; Mfr. Part # RC0402FR-07100KL; LCSC Part # C60491; not fitted
R36: 220K; R_0402_1005Metric; Mfr. Part # 0402WGF2203TCE; LCSC Part # C25767
R37: 100K; R_0402_1005Metric; Mfr. Part # RC0402FR-07100KL; LCSC Part # C60491
R38: 5.49K; R_0402_1005Metric; Mfr. Part # CRCW04025K49FKED; LCSC Part # C2092200
R39: 2.32K; R_0402_1005Metric; Mfr. Part # CRCW04022K32FKED; LCSC Part # C2091739
R40: 3.48K; R_0402_1005Metric; Mfr. Part # CRCW04023K48FKED; LCSC Part # C4336043
R45: 11K; R_0402_1005Metric; Mfr. Part # WR04X113JTL; LCSC Part # C172152
R46: 2.1K; R_0402_1005Metric; Mfr. Part # WR04X2101FTL; LCSC Part # C170256
R47: 7.68k; R_0402_1005Metric; Mfr. Part # WR04X7681FTL; LCSC Part # C334733
R48: 10K; R_0402_1005Metric; Mfr. Part # WR04X1002FTL; LCSC Part # C163810
R50, R52: 49.9K; R_0402_1005Metric; Mfr. Part # CRCW040249K9FKED; LCSC Part # C350874
R51: 226K; R_0402_1005Metric; Mfr. Part # CRCW0402226KFKED; LCSC Part # C2076623
R128, R129, R130: 715; R_0402_1005Metric; Mfr. Part # WR04X7150FTL; LCSC Part # C334727
R131, R138: 1K; R_0402_1005Metric; Mfr. Part # MR04X1001FTL; LCSC Part # C327796
R165: 0.005; R_2512_6332Metric; Mfr. Part # FRM252WJR005TN; LCSC Part # C7419996
U1: SZMMSZ4702T1G; SOD-123_ONS; Mfr. Part # SZMMSZ4702T1G; LCSC Part # C463904
U2: SI2324DS-T1-GE3; SOT_4DS-T1-GE3_VIS; Mfr. Part # SI2324DS-T1-GE3; LCSC Part # C190351
U3: SIC453ED-T1-GE3; POWERPAK_MLP34-57_VIS; Mfr. Part # SIC453ED-T1-GE3; LCSC Part # C5334327
U4: JW5026; SOT-23-6; Mfr. Part # JW5026; LCSC Part # C185109
Z1: MMSZ5255BT1G; SOD3716X135N; Mfr. Part # MMSZ5255BT1G; LCSC Part # C242284

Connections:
+1V0: R130.1, R165.1; also elsewhere on the board
+1V8: C41.1, C50.1, C54.2, C57.2, L5.1, R49.1, R128.1; also elsewhere on the board
+1V35: C39.1, C44.2, C47.2, L4.1, R47.1, R129.1; also elsewhere on the board
+3V3: C43.1, C51.1, C53.2, C56.2, L6.1, R51.2, R131.1; also elsewhere on the board
+5V: C40.1, C45.2, C48.2, L2.2, R45.2, R138.1; also elsewhere on the board
/POWER/12.8V: C11.1, C12.1, C13.1, C14.1, C15.1, D2.2, L1.2, R33.1
/POWER/PGOOD_1V: IC2.1 (EN), IC4.1 (EN), R35.2, U3.13 (PGOOD)
/POWER/PGOOD_1V8: C30.1, IC2.3 (VREG5), R41.1
/POWER/PGOOD_3V3: C32.1, IC3.5 (EN), IC4.3 (VREG5), R43.1
/POWER/VSEN_P: C38.1, C42.1, C46.1, C49.1, C52.1, C55.2, L3.2, R165.2, U3.12 (VSEN+)
/VDC_IN: C3.1, C4.1, C5.1, C6.1, C7.1, IC1.2 (VIN), R25.2, R28.1, Z1.1; also elsewhere on the board
/VSS_POE: C3.2, R25.1, R26.1, U1.2, U2.3 (D); also elsewhere on the board
GND: C4.2, C5.2, C6.2, C7.2, C8.2, C9.2, C11.2, C12.2, C13.2, C14.2, C15.2, C16.2, C17.2, C18.2, C19.2, C20.2, C21.2, C22.2, C23.2, C24.2, C25.2, C26.2, C27.2, C28.2, C29.2, C30.2, C31.2, C32.2, C38.2, C39.2, C40.2, C42.2, C44.1, C45.1, C46.2, C47.1, C48.1, C49.2, C50.2, C51.2, C52.2, C53.1, C54.1, C55.1, C56.1, C57.1, C354.2, C355.2, C356.2, D1.2, D17.1 (K), D18.1 (K), D19.1 (K), D20.1 (K), D21.1 (K), IC1.7 (GND_1), IC1.9 (GND_2), IC2.5 (GND), IC2.9 (EP), IC3.1 (GND), IC4.5 (GND), IC4.9 (EP), J1.2, J1.3, R29.1, R31.1, R34.2, R37.1, R38.1, R39.1, R40.1, R46.1, R48.2, R50.1, R52.1, U2.2 (S), U3.7 (AGND), U3.11 (VSEN-), U3.16 (AGND), U3.32/33 (PGND), U4.2 (GND); also elsewhere on the board
unnamed: C9.1, R30.1
unnamed: C10.2, R32.2
unnamed: C16.1, D2.1, D3.1, F2.2
unnamed: C37.2, R44.2
unnamed: D3.2, J1.1A, J1.1B
unnamed: D17.2 (A), R130.2
unnamed: D18.2 (A), R129.2
unnamed: D19.2 (A), R128.2
unnamed: D20.2 (A), R131.2
unnamed: D21.2 (A), R138.2
unnamed: C10.1, IC1.1 (BOOT)
unnamed: C8.1, IC1.6 (COMP), R30.2
unnamed: IC1.3 (EN), R28.2, R29.2
unnamed: IC1.5 (FB), R33.2, R34.1
unnamed: IC1.4 (RT/SYNC), R31.2
unnamed: D1.1, IC1.8 (SW), L1.1, R32.1
unnamed: IC2.4 (PG), R41.2
unnamed: C35.1, IC2.6 (SW), L5.2
unnamed: C35.2, IC2.7 (VBST)
unnamed: C41.2, IC2.2 (VFB), R49.2, R50.2
unnamed: C34.1, IC3.2 (SW), L4.2
unnamed: C34.2, IC3.6 (VBST)
unnamed: IC3.4 (VFB), R47.2, R48.1
unnamed: IC4.4 (PG), R43.2
unnamed: C36.1, IC4.6 (SW), L6.2
unnamed: C36.2, IC4.7 (VBST)
unnamed: C43.2, IC4.2 (VFB), R51.1, R52.2
unnamed: R27.2, Z1.2
unnamed: R26.2, R27.1, U1.1, U2.1 (G)
unnamed: R40.2, U3.14 (ADDR)
unnamed: C37.1, U3.6 (BOOT)
unnamed: R36.1, R37.2, U3.21 (EN)
unnamed: R44.1, U3.4 (PH)
unnamed: R38.2, U3.17 (RT/SYNC)
unnamed: L3.1, U3.26-31 (SW)
unnamed: R39.2, U3.15 (VSET)
unnamed: C20.1, U3.24 (PVCC)
unnamed: C19.1, R35.1, U3.22 (VDD)
unnamed: C33.1, U4.1 (BST)
unnamed: R42.2, U4.4 (EN)
unnamed: R45.1, R46.2, U4.3 (FB)
unnamed: C33.2, L2.1, U4.6 (SW)

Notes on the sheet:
Fsw:800kHz
L->H:39.83 H->L:37.82
VIN(MAX):14V VIN(NOM):12V
VOUT:1.8V(+-4%) IOUT:5A VOUT,ripple:5mV Eff@25degC:82%
VOUT:12.8V IOUT:4A VOUT,ripple:3mV
VOUT:3.32V(+-4%) IOUT:5A VOUT,ripple:8mV Eff@25degC:87%
VOUT:5V IOUT:800mA VOUT,ripple:
VOUT:1VDC
Vin:40-60V
VOUT:1.35V(+-3.5%) IOUT:3A VOUT,ripple:5.5mV Eff@25degC:77%
fsw:800kHz
VEN_Max:4V4
VOUT:1V IOUT:15A VOUT,ripple:3mV Eff@25degC:75-86%

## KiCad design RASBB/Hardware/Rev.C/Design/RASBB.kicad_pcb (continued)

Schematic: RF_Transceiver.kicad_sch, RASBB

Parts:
C145, C149: 20p; C_0402_1005Metric; Mfr. Part # 0402N200J500CT; LCSC Part # C123468
C146, C147: 10uF; C_0402_1005Metric; Mfr. Part # 0402X106M100CT; LCSC Part # C2992625
C148, C152, C154: 100nF; C_0402_1005Metric; Mfr. Part # 0402B104K500CT; LCSC Part # C152814
C150, C151: 10nF; C_0402_1005Metric; Mfr. Part # 0402B103K500CT; LCSC Part # C301927
C153: 470nF; C_0402_1005Metric; Mfr. Part # GRT155R71A474KE01D; LCSC Part # C471404
C155: 0.8pF; C_0402_1005Metric; Mfr. Part # RF15N0R8B500CT; LCSC Part # C396870
C156, C158: 1.2pF; C_0402_1005Metric; Mfr. Part # 0402N1R2C500CT; LCSC Part # C301969
C157: 0.5pF; C_0402_1005Metric; Mfr. Part # RT15N0R5B500CT; LCSC Part # C2918554
C159: 100pF; C_0402_1005Metric; Mfr. Part # 0402N101G500CT; LCSC Part # C387967
FB3: BLM15BD601SH1D; NFZ15SG152SN10B; Mfr. Part # BLM15BD601SH1D; LCSC Part # C710334
IC13: SX1280IMLTRT; QFN50P400X400X100-25N-D; Mfr. Part # SX1280IMLTRT; LCSC Part # C125969
J11: Conn_Coaxial; U.FL_Hirose_U.FL-R-SMT-1_Vertical; Mfr. Part # CONUFL001-SMD-T or similar; LCSC Part # C22418213
L9: 3nH; L_0402_1005Metric; Mfr. Part # MHQ1005P3N0BT000; LCSC Part # C433005
L10: 2.5nH; L_0402_1005Metric; Mfr. Part # FHW0402UC2N5KST; LCSC Part # C317668
Y2: XC21M4-52.000-F10NNHPL; Mfr. Part # XC21M4-52.000-F10NNHPL; LCSC Part # C3034316

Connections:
+3V3: FB3.1; also elsewhere on the board
/RF_Transceiver/BUSY_LORA_G: IC13.7 (BUSY); also elsewhere on the board
/RF_Transceiver/DIO1_LORA_G: IC13.8 (DIO1); also elsewhere on the board
/RF_Transceiver/DIO2_LORA_G: IC13.9 (DIO2); also elsewhere on the board
/RF_Transceiver/DIO3_LORA_G: IC13.10 (DIO3); also elsewhere on the board
/RF_Transceiver/LORA_VDDIO: C146.1, C147.1, C148.1, C152.1, C154.1, FB3.2, IC13.11 (VBAT_IO), IC13.15 (VBAT)
/RF_Transceiver/NRST_LORA_G: IC13.3 (NRESET); also elsewhere on the board
/RF_Transceiver/SPI_MISO_LORA_G: IC13.16 (MISO_TX); also elsewhere on the board
/RF_Transceiver/SPI_MOSI_LORA_G: IC13.17 (MOSI_RX); also elsewhere on the board
/RF_Transceiver/SPI_NSS_LORA_G: IC13.19 (NSS_CTS); also elsewhere on the board
/RF_Transceiver/SPI_SCK_LORA_G: IC13.18 (SCK_RTSN); also elsewhere on the board
GND: C145.2, C146.2, C147.2, C148.2, C149.2, C150.2, C151.2, C152.2, C153.2, C154.2, C155.2, C156.2, C158.2, IC13.5 (GND_1), IC13.13 (GND_2), IC13.20 (GND_3), IC13.21 (GND_4), IC13.23 (GND_5), IC13.24 (GND_6), IC13.25 (EP), J11.2 (Ext), Y2.2 (GND_1), Y2.4 (GND_2); also elsewhere on the board
unnamed: C156.1, C157.1, L9.2, L10.1
unnamed: C157.2, C158.1, C159.2, L10.2
unnamed: C150.1, C153.1, IC13.2 (VDD_IN), IC13.12 (DCC_FB)
unnamed: C155.1, IC13.22 (RFIO), L9.1
unnamed: C151.1, IC13.1 (VR_PA)
unnamed: C149.1, IC13.4 (XTA), Y2.3 (XTAL_2)
unnamed: C145.1, IC13.6 (XTB), Y2.1 (XTAL_1)
unnamed: C159.1, J11.1 (In)

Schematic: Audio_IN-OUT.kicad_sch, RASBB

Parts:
C160, C161, C166: 10uF; C_0603_1608Metric; Mfr. Part # 0603X106M250CT; LCSC Part # C4555498
C162: 47nF; C_0402_1005Metric; Mfr. Part # C0402C473J8RAC7867; LCSC Part # C2178375
C163: 100pF; C_0402_1005Metric; Mfr. Part # 0402N101G500CT; LCSC Part # C387967
C164, C353: 100nF; C_0402_1005Metric; Mfr. Part # 0402B104K500CT; LCSC Part # C152814
C165: UUD1A221MCL1GS; CAPAE660X800N; Mfr. Part # UUD1A221MCL1GS; LCSC Part # C445275
C167: 1uF; C_0402_1005Metric; Mfr. Part # 0402X105M160CT; LCSC Part # C3889771
J12: AudioJack4; FC68128; Mfr. Part # HC-PJ-313E8-B-SMT; LCSC Part # C7501803
R67, R124: 10K; R_0402_1005Metric; Mfr. Part # WR04X1002FTL; LCSC Part # C163810
R121: 1.2K; R_0402_1005Metric; Mfr. Part # WR04X1201FTL; LCSC Part # C168197
R122: 10; R_0402_1005Metric; Mfr. Part # 0402WGF100JTCE; LCSC Part # C25077
R123: 51K; R_0603_1608Metric; Mfr. Part # WR06X5102FTL; LCSC Part # C227390
R125, R126: 100K; R_0402_1005Metric; Mfr. Part # RC0402FR-07100KL; LCSC Part # C60491; not fitted
R127: 5.6K; R_0402_1005Metric; Mfr. Part # WR04X5601FTL; LCSC Part # C168239
U8: LM386; SOP-8_3.9x4.9mm_P1.27mm; Mfr. Part # LM386D; LCSC Part # C510560
U9: LM321; SOT-23-5; Mfr. Part # LM321-TR; LCSC Part # C280706

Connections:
+3V3: C164.1, R67.2, R125.2, R127.1, U9.5 (V+); also elsewhere on the board
+5V: C353.1, U8.6 (V+); also elsewhere on the board
/Audio_IN-OUT/Audio_IN: C163.2, R123.2, U9.4; also elsewhere on the board
/Audio_IN-OUT/Audio_PTT: J12.4A (R1), J12.4B (R1), R67.1; also elsewhere on the board
/Audio_IN-OUT/LM386_INP: U8.3 (+); also elsewhere on the board
GND: C160.2, C162.2, C164.2, C353.2, J12.1A (S), J12.1B (S), R124.2, R126.1, U8.2 (-), U8.4 (GND), U9.2 (V-); also elsewhere on the board
unnamed: C161.1, U8.8 (GAIN)
unnamed: C161.2, R121.2
unnamed: C162.1, R122.1
unnamed: C165.1, R122.2, U8.5
unnamed: C165.2, J12.2A (T), J12.2B (T)
unnamed: C166.2, R124.1
unnamed: C167.2, J12.3A (R2), J12.3B (R2), R127.2
unnamed: R121.1, U8.1 (GAIN)
unnamed: C160.1, U8.7 (BYPASS)
unnamed: C167.1, R125.1, R126.2, U9.1 (+)
unnamed: C163.1, C166.1, R123.1, U9.3 (-)

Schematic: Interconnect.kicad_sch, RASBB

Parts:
C125, C256: 22uF; C_0603_1608Metric; Mfr. Part # 0603YD226MAT2A; LCSC Part # C6776252
J5: FH12-50S-0.5SV; CON50_1X50_DUTB_HRS_HIR; Mfr. Part # FH12-50S-0.5SVA(54); LCSC Part # C597991
RN1, RN2, RN3, RN4, RN5, RN6, RN7, RN8, RN9, RN10: CAY10-330J4LF; CAY10-XXXJ4; Mouser Part Number 652-CAY10-330J4LF
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

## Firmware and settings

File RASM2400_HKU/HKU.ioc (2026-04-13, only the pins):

Mcu.UserName=STM32C031G6Ux
PA0.Signal=USART1_TX
PA1.Signal=USART1_RX
PA13.Signal=DEBUG_SWDIO
PA14-BOOT0.Signal=DEBUG_SWCLK
PA15.GPIO_Label=LED_PIN
PA15.Signal=GPIO_Output
PA2.Signal=SPI1_MOSI
PA3.GPIO_Label=LVL_SH_EN
PA3.Signal=GPIO_Output
PA4.GPIO_Label=ADC_NCS
PA4.Signal=GPIO_Output
PA5.Signal=SPI1_SCK
PA6.Signal=SPI1_MISO
PB3.GPIO_Label=MAX_LD
PB3.Signal=GPXTI3
PB6.Signal=I2C1_SCL
PB7.Signal=I2C1_SDA

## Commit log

2026-04-13 Initial commit - RASRF2400WBMC Rev A.0 hardware design
    [ADC3221.kicad_sch, ADC3244.kicad_sch, ADC3244kicad_sch.kicad_sch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]
2026-04-16 Rename Folder
    [ADC3221.kicad_sch, MAX2831.kicad_sch, PCIe.kicad_sch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]
2026-04-16 Fix PCB folder name and formatting in README
    Updated PCB design folder name and fixed formatting issues in the README.
2026-04-18 Fix board name formatting in README
2026-04-19 Correct the U2 Regulator P/N
    [RASRF2400WBMC_BoM.xlsx, REG-OSC-CLK_kicad_sch.kicad_sch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]
2026-04-19 Correct part number for LDO regulator
2026-04-25 Correct the MPN for a resistor/ Added NLNet and OSHW logos
    [RASRF2400WBMC-B_Courtyard.gbr, RASRF2400WBMC-B_Cu.gbr, RASRF2400WBMC-B_Mask.gbr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]
2026-04-25 Added 2.4GHz Antenna Board
    [RASANT2400.kicad_pcb, RASANT2400.kicad_sch]
2026-08-15 Added the Rev C BoM to send to the supplier for pre-buying parts.
    [RASBB_REVC_01.csv]
2026-09-13 Draft AC
    [Audio_IN-OUT.kicad_sch, Config-SPI FLASH.kicad_sch, Ethernet_FPGA.kicad_sch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]
2026-09-16 Add open item for shunt resistor at 12V entry
2026-09-20 Modified Based on Findings -Draft
    [Audio_IN-OUT.kicad_sch, Config-SPI FLASH.kicad_sch, Ethernet_FPGA.kicad_sch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]

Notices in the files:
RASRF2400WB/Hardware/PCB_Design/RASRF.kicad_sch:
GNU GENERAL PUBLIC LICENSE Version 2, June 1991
